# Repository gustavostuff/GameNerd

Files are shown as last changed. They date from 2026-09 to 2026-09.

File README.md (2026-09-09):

Logo V2

> **Status:** Active work has shifted to **[Retr01 Nano](nano/README.md)**, a smaller, simpler sibling meant to ship first. The full Retr01 design below is paused for now. It remains the long-term target once Nano is solid.

Retr01 is an MCU-assisted 8-bit system, complemented by a software toolchain. The software consists of 3 different (WIP) packages:

- **Retr01 Studio**: the game editor. Draw maps, tiles, and sprites, then hit **Play** to try your game (uses the emulator render code).
- **Retr01 Emu**: the standalone game player. Runs a cartridge image on your computer. Studio Play uses this same engine.
- **Retr01 Sim**: the board simulator. Shows the ICs and wiring of the motherboard so we can bring up the real design before hardware.

This is the overall hardware roadmap:

- **Retr01-A and Retr01-C** (Arcade and Console): One THT board for both shells. Same **23-IC** core, [**36-pin cart**](docs/cart.md), **RGBS + composite**, 5 V barrel. Arcade microswitch headers **and** PCB footprints for **2x Switchcraft 35RAPC** TRS ([`docs/controllers.md`](docs/controllers.md)).
- **Retr01-H (stage 2)**: Handheld. SMD, battery, LCD + driver, contact pads. Same software contract. It will also include 3.5mm ports for controllers and possibly one more for mono audio + composite.

## Apps

`./build-all` builds Release **Studio**, **Emu**, **Sim**, **Nano Studio**, **Nano Emu**, and **Nano Sim** into `bin/`. `./studio`, `./emu`, and `./sim` (at root) run the full Retr01 binaries. `./unit-tests` runs their test suites.

**Retr01 Nano** (design + apps under [`nano/`](nano/README.md)): `./nano_studio` (optional project path), `./nano_emu [cart.r01nano]`, and `./nano_sim [cart.r01nano]`.

## Main specs

| Aspect | Description |
|--|--|
| CPU | W65C02S @ **8 MHz** |
| Playfield | **128 x 120** of logical resolution (**16 x 15** tiles), board **2x** to **256 x 240** RGBS field |
| Art | **8 x 8** tiles, **2 bpp**, **64** master colors on-board Color PROM IC |
| Worlds | up to **8** worlds x **48** screens each (384-screen "real state"). All within a 512KB cartridge |
| Scroll | **2 x 2** live nametable window + **true second BG** (SNES-like parallax via color-0 show-through) |
| Sprites | **128** OAM entries, **16** per scanline |
| VRAM / RAM | **32 KB** interleaved VRAM + **32 KB** system RAM |

In cartridge, same **32 KB PRG** as classic NES NROM games (Exitebike, Balloon Fight, Ice Climbers) but it buys far more game: **4.5x** more CPU cycles per frame at **8 MHz**, **32 KB** system RAM (not 2 KB). Scroll, sprite line fill and world map streaming are hardware jobs, so PRG stays game logic, not VBlank nametable tricks. A structured **BG0** far plane scrolls under BG1 (color **0** windows) for real dual-layer parallax, not a mapper hack. See [`docs/selling_points.md`](docs/selling_points.md).

## Screenshots

Peek at Retr01 Studio:

Studio - Graphics

Studio - Audio

Emulator:

Emu

Sim:

Sim

Main PCB - preliminary design, not tested:

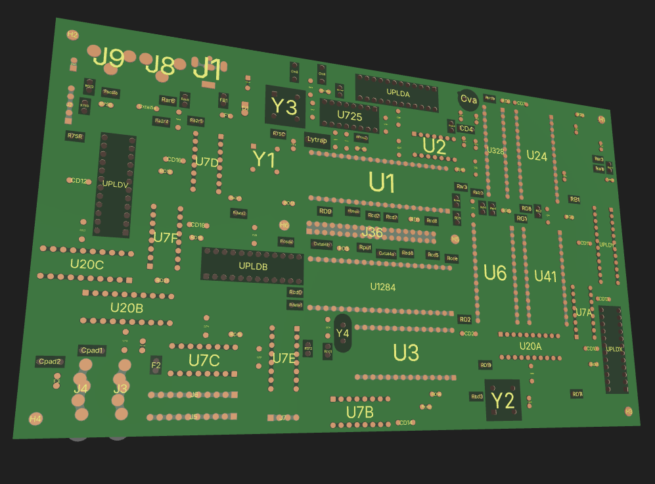
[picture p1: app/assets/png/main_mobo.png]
Main PCB


Cart PCB - preliminary design, not tested:

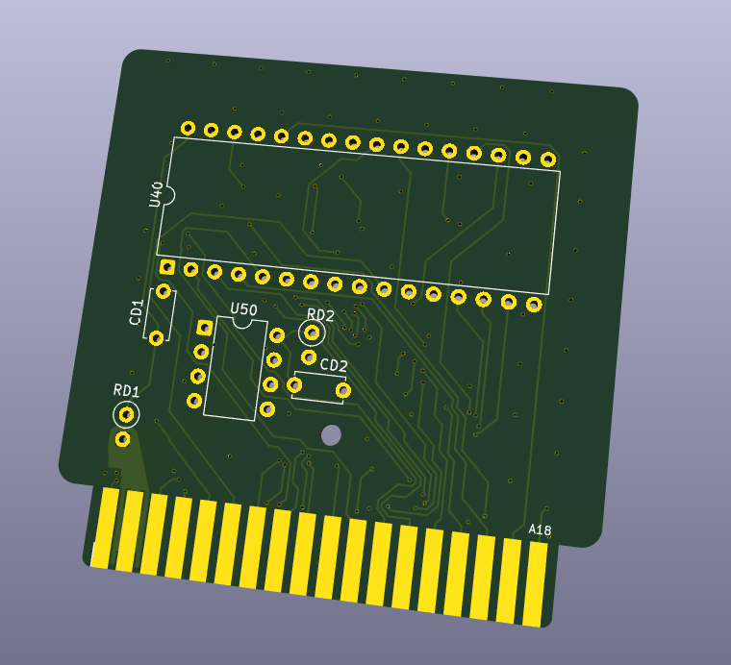
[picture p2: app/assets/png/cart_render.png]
Cart PCB


## Where to go next

- [`docs/graphics.md`](docs/graphics.md): VRAM, BG0/BG1, sprites, palettes, graphics ports
- [`docs/selling_points.md`](docs/selling_points.md): NES vs Retr01, including **SNES-like parallax (BG0)**
- [`docs/memory.md`](docs/memory.md): chips, cart layout, read/write timing
- [`docs/hardware.md`](docs/hardware.md): IC BOM, block diagram, bring-up (chips only)
- [`docs/cart.md`](docs/cart.md): cartridge pinout, form factor, USB-C flasher
- [`docs/controllers.md`](docs/controllers.md): Retr01-A arcade vs Retr01-C pad protocol
- [`docs/lightgun.md`](docs/lightgun.md): CRT light gun accessory (roadmap)
- [`docs/passive_rf_etc.md`](docs/passive_rf_etc.md): passives, ports, stackup / RF
- [`docs/sound.md`](docs/sound.md): APU and bytecode
- [`hw/`](hw/): part list + [`hw/md/`](hw/md/) chip notes. Live KiCad: [`hw/kicad/`](hw/kicad/README.md)

Built for people who want to *make* 8-bit games, not only play them.

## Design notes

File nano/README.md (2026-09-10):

# Retr01 Nano

**The smallest, cutest, simplest cartridge-based dual gaming system (arcade + console).**

**Status: Phase 1 bring-up next.** Host Studio / Emu / Sim already run a MAP-only picture path. Console silicon starts with a bare RGBS lab setup (below). Later phases grow toward the full Nano form already sketched in [`docs/`](docs/).

Retr01 Nano is a **spiritual child** of [Retr01](../README.md): same 128-wide arcade language, far less hardware. One **ATmega1284P** runs a **fixed, open console firmware**. Games live on a **tiny dual-sided cartridge** (SPI EEPROM + save EEPROM). There is **no 6502** and **no external video ASIC**.

## Roadmap (phases)

We are starting at **Phase 1** (not phase 0). Later phases add the rest of the product. The tables and docs below describe that **final form**. Phase 1 is only the smallest path that proves RGBS on a real CRT.

### How we bring up hardware

We grow the console **one phase at a time** instead of assembling the full board and then sorting out every fault at once. Each phase documents, models, builds, and tests a bounded slice of hardware. If something fails, the cause is almost certainly in what that phase added.

Within each phase:

1. **Document** the hardware and how it should behave (pin map, nets, timing, expected picture / signals). Much of the final BOM is already planned in [`docs/`](docs/), so this step often refines known parts rather than inventing them.
2. **Model** that slice in SKiDL directly, or first in **Nano Sim** and then in SKiDL (see [`schematic_generator/`](schematic_generator/), including `generate_phase1.py`).
3. **Import** the updated / expanded netlist into KiCad. Generate or refresh a realistic BOM there (cross-check against the docs from step 1).
4. **Buy** only the new parts for that phase, wire them onto the current protoboard, and **test** on the bench (flash, probe, CRT).

That loop keeps documentation, design, implementation, and validation aligned. Full-board bring-up is deferred until the slices already work.

### Phase 1 (now): RGBS video lab

Goal: prove the video pipeline on a real CRT. Firmware holds a small pattern in ATmega RAM (black backdrop plus a few randomly placed colored squares from the **8** board FG colors), composes **128x96 @ ~60 Hz**, and drives **RGBS** at **256x192** via **2x**. No cart load yet.

| Need | Role |
|---|---|
| ATmega1284P **PDIP-40** | MCU. Flash open firmware. Hold the RAM pattern |
| External **20 MHz** crystal (+ load caps) | Solid clock from Phase 1 (same preferred rate as the final board) |
| 1 or 2 protoboards | Wire MCU + crystal + resistor DAC + power only |
| USBasp | Flash the ATmega (ISP / `J_ISP` pinout) |
| DC barrel jack to screw-terminal adapter | Plug Mean Well **+5V** into the female jack. Screw jumpers on **+** / **-** into the proto rails |
| Resistors | Build analog **R / G / B / CSYNC** (RGBS) per [`docs/pinmap.md`](docs/pinmap.md) |

**Out of scope for Phase 1:** player input, audio, cart flash, save EEPROM, AD725 / composite, sprites, Studio cart load on the MCU.

**Success:** flash via USBasp, run a minimal scanline kernel, see a stable **128x96** (shown **2x**) picture of random colored squares on black over RGBS on the CRT.

### Later phases (final form)

Build toward the full Nano already planned in the docs:

| Area | Final form (docs) |
|---|---|
| Worlds / screens | Up to **8** worlds, **16** present screens/world, **16x16** virtual grid |
| Picture | **1 bpp** tiles, **8** board FG colors, black backdrop, **128x96** logical, **256x192** RGBS via **2x** |
| Motion | Instant screen switch only (no scrolling) |
| Sprites | Soft display sprites (rebuilt after MAP base). Caps TBD in [`docs/graphics.md`](docs/graphics.md) |
| Players | **2P** pad bytes (Retr01 spirit) |
| Audio | **2 PWM** channels (music pulse + SFX), resistor-mixed |
| Cart | **25LC1024** (128 KB game) + **24C64** save, cute **8+8** edge |
| Firmware | Fixed open image on the 1284. Games are cart data |

| | Retr01 (full) | Retr01 Nano (final form) |
|--|---|---|
| CPU / host | 6502 + MCUs | Single ATmega1284P @ 20 MHz (preferred) |
| Storage | Large cart flash + 24C64 | **Cute cart:** **25LC1024** (128 KB, DIP-8) + **24C64** (DIP-8) |
| Firmware | Cart PRG + MCU assists | **Fixed open** 1284 firmware (community-flashable) |
| Video | Multi-layer tile / sprite pipeline | 1 bpp tiles, attr FG color, soft sprites (later) |
| Worlds | Up to 8, rich MAP | Up to **8** worlds, **16** screens/world, **16x16** screen grid |
| Resolution (target) | 128x120 logical playfield | **128x96** logical, **256x192** RGBS via **2x** |
| Motion | Pixel scroll + streaming | **Instant screen switch only** |
| Players | 2P arcade GPIO | **2P** same pad-byte spirit |
| Audio | Multi-channel APU path | **2 PWM channels** (music pulse + SFX), resistor-mixed |

Primary product goal: a **minimal, stable 60 Hz** board with the smallest carts we can get away with, still feeling like Retr01. See [`docs/video.md`](docs/video.md) and [`docs/overview.md`](docs/overview.md).

## Host apps (Studio / Emu / Sim)

For now, **Nano Studio**, **Nano Emu**, and **Nano Sim** are **independent** trees under [`apps/`](apps/) (and root launchers). They may start as copies of the full Retr01 tools and diverge freely.

Later they are intended to **share common code** with the full Studio / Emu / Sim apps (shared libraries or extracted modules) instead of remaining permanent forks. Until that merge, prefer fixing Nano behavior in the Nano tree and keep full apps unchanged unless a change is deliberately shared.

**Apps:** [`apps/studio/`](apps/studio/) is Nano Studio. [`apps/emu/`](apps/emu/) is Nano Emu (MAP preview). [`apps/sim/`](apps/sim/) is the IC/netlist board. See [`apps/README.md`](apps/README.md).

| Runner | Picture | Host audio overlay |
|---|---|---|
| Nano Studio Play | MAP preview (export + emu) | Yes |
| `./nano_emu` | MAP preview | No |
| `./nano_sim` | Soft compose MAP | No |

Host runners are **ahead of Phase 1 silicon**. They already compose MAP tiles from a cart image. Phase 1 MCU firmware does not load carts yet. It only proves RGBS from patterns in ATmega RAM.

## Docs

| Doc | Topic |
|-----|---|
| [`docs/overview.md`](docs/overview.md) | Goals, cuts, roadmap |
| [`docs/graphics.md`](docs/graphics.md) | Worlds, screens, attr byte, MAP compose |
| [`docs/video.md`](docs/video.md) | RGBS, 2x to 256x192, line buffers, VBlank loads |
| [`docs/memory_and_software.md`](docs/memory_and_software.md) | MCU vs cart budgets, open firmware, SDK |
| [`docs/cache_architecture.md`](docs/cache_architecture.md) | How 16 KB SRAM caches cart MAP/CHR without filling to the brim |
| [`docs/sound.md`](docs/sound.md) | 2-channel music + SFX PWM |
| [`docs/cart_format.md`](docs/cart_format.md) | `.r01proj` + `.r01nano` / 128 KB flash layout |
| [`docs/hardware.md`](docs/hardware.md) | Mobo + cute cart connector, BOM sketch |
| [`docs/pinmap.md`](docs/pinmap.md) | MCU PORT / PDIP-40 map, headers, cart edge |
| [`schematic_generator/`](schematic_generator/) | SKiDL. Phase 1: `generate_phase1.py` -> `nano_phase1.net`. Full: `nano_mobo.net` + `nano_cart.net` |

From the repo root:

| Command | Role |
|---|---|
| `./nano_studio [project.r01proj]` | Nano Studio (`bin/nano_studio` from `./build-all`) |
| `./nano_emu [cart.r01nano]` | Nano Emu MAP preview (`bin/nano_emu`) |
| `./nano_sim [cart.r01nano]` | Nano Sim: IC/netlist board UI (islands + DIPs + SCR), not a fullscreen emu |

Source concept notes also live in `temp/Retr01_Nano_Spec.md`. Where this tree disagrees, **these docs win**.

## Non-goals (final product v1)

- Compatibility with full Retr01 `.retr01` cart images or 36-pin edge
- Composite / NTSC encoder chips on the Phase 1 lab (AD725 remains a later board option)
- Hardware sprites, BG0, any screen scrolling
- Full Retr01 Sim netlist reuse

**Authoring:** Nano Studio exports `.r01nano` today (MAP + CHR). Console firmware / C SDK on the 1284 start with Phase 1 RGBS bring-up. Direction: open **C** firmware/SDK plus a tiny assembly video kernel. Game data lands on the SPI cart in later phases.

## Screenshots

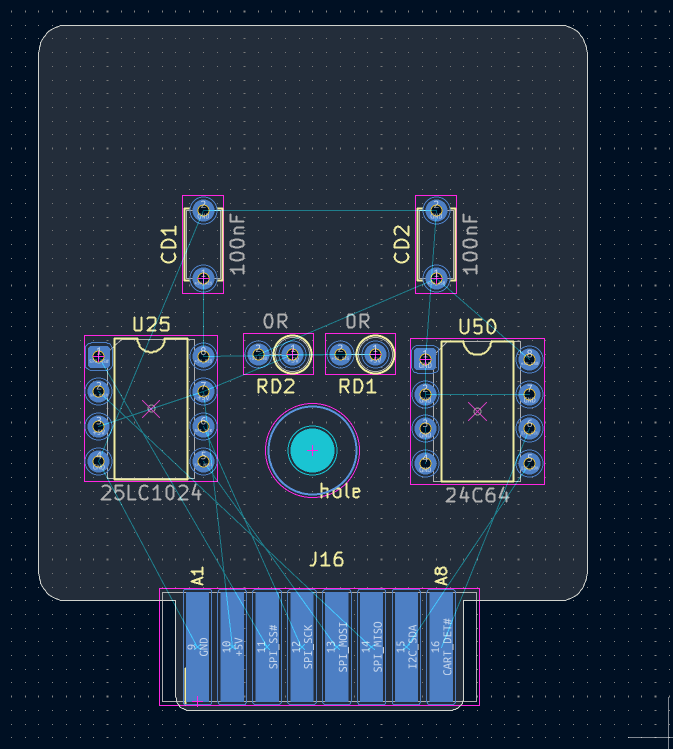
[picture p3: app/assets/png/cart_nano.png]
Nano cart


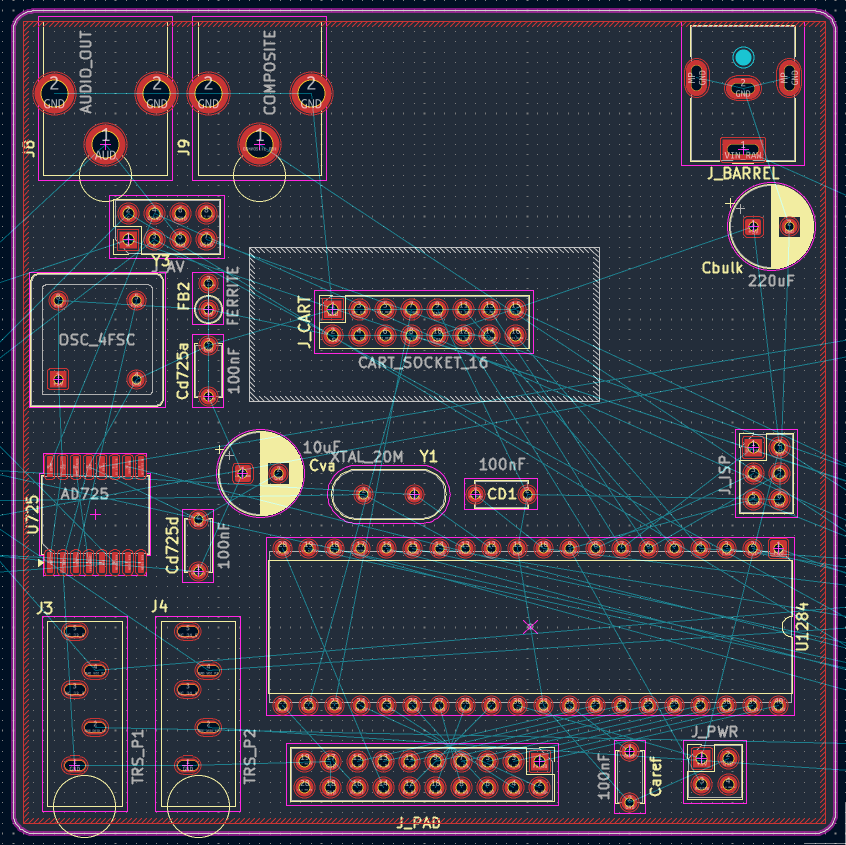
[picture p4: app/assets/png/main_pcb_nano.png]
Nano Main PCB


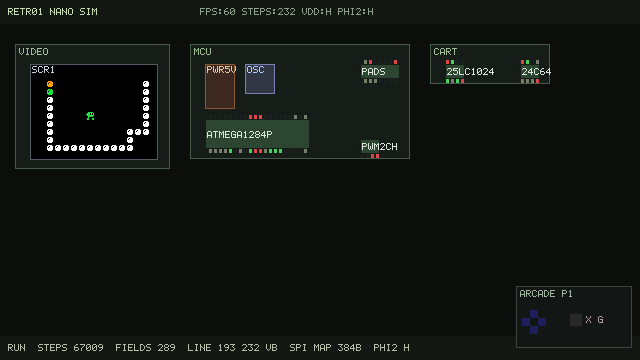
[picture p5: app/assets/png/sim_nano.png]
Nano Sim


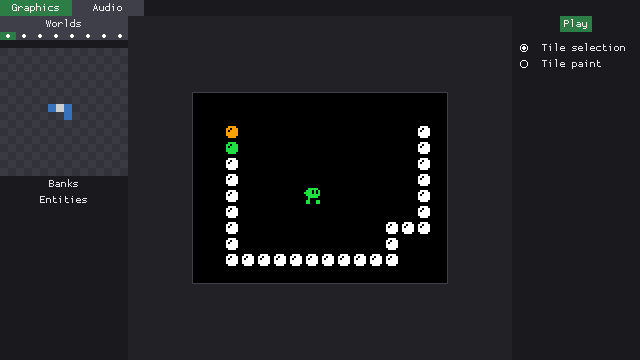
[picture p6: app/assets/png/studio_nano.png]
Nano Studio


## License / ownership

Same project umbrella as Retr01. Console firmware is intended to stay **open** for the community. See the parent repo for licensing when published.

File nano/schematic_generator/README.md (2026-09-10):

# Nano schematic generator (SKiDL)

Python package that turns Retr01 Nano motherboard + cart wiring into KiCad netlists.
Mirrors `app/schematic_generator/` (parent Retr01): pin numbers from official KiCad
symbols, inline SKiDL parts, separate mobo / cart netlists.

## Code-to-copper

1. Docs SoT: `nano/docs/pinmap.md`, `nano/docs/hardware.md`
2. `python generate.py --check`
3. `python generate.py` -> `output/nano_mobo.net` + `output/nano_cart.net`
4. Import each netlist into its KiCad project (see [Netlist import](#netlist-import) below). Outline starts at 100x100 mm (provisional).
5. Route (Quilter optional). Bypass uses per-IC local `+5V_<refdes>` + 0R bridges.

## Netlist import

Nano and full Retr01 share **one** footprint library: [`hw/kicad/Retr01_Lib.pretty`](../../hw/kicad/Retr01_Lib.pretty). The netlist only carries a **name** (e.g. `Retr01_Lib:Jack_3.5mm_Switchcraft_35RAPC2BVN4_Vertical`); KiCad loads the actual `.kicad_mod` from the project **`fp-lib-table`**.

Each Nano KiCad project includes `fp-lib-table` pointing at that folder. After editing a footprint in `Retr01_Lib.pretty`, re-import or **Update Footprints from Library** so pcbnew picks up the change (placed footprints are copies until refreshed).

**Mobo** (`nano/nano_main_pcb/nano_main_pcb_v_01/`):

1. Open `nano_main_pcb_v_01.kicad_pro`.
2. Confirm **Preferences -> Manage Footprint Libraries** shows **Retr01_Lib** (no broken path).
3. **File -> Import -> Netlist** -> `nano/schematic_generator/output/nano_mobo.net`.
4. Enable **Exchange footprint** (or delete old J3/J4/J8/J9 before re-import if footprints were stale).
5. Place / route. Custom parts from netlist: **J3/J4** TRS, **J8/J9** RCA, **J_CART** uses stock PinSocket 2x8 (not Retr01_Lib).

**Cart** (`nano/nano_cart_pcb/Nano_Cart_PCB_v_01/`):

1. Same `fp-lib-table` -> **Retr01_Lib**.
2. Import `output/nano_cart.net`. **J16** -> `Retr01_Lib:Cart_Edge_2x8_P2.54mm`.

## KiCad symbol mapping

Same pattern as parent `retr01_schem/pinmap.py` / `kicad_pin_extract.json`:

| Nano MPN | KiCad lib | KiCad symbol | Notes |
|---|---|---|---|
| ATmega1284P | MCU_Microchip_ATmega | **ATmega1284P-P** | PDIP-40 (mobo THT) |
| AD725 | (inline) | AD725ARZ wide SOIC-16 | `Package_SO:SOIC-16W_7.5x10.3mm_P1.27mm` |
| 25LC1024 | (inline / datasheet) | JEDEC SPI EEPROM | **PDIP-8** cart game image |
| 24C64 | Memory_EEPROM | **24LC64** (extends 24LC16) | **PDIP-8** |
| Passives | Device | R, C | |
| Barrel | Connector | Barrel_Jack_MountingPin | Footprint CUI PJ-063AH |
| Headers | Connector_Generic | Conn_02xN | 2x2 PWR, 2x3 ISP, 2x4 AV, 2x10 arcade |
| TRS / RCA | Retr01_Lib | 35RAPC2BVN4 / RCJ-01x | Same footprints as full Retr01 |

SKiDL still builds `Part(tool=SKIDL)` with **physical pad numbers**. Official KiCad
signal names are aliases (`PB5`, `~{CE}`, ...).

## Quick start

```bash
cd nano/schematic_generator
# reuse parent venv, or:
python -m venv .venv && source .venv/bin/activate
pip install -r requirements.txt

# Phase 1 lab (MCU + crystal + RGBS + ISP, no cart):
python generate_phase1.py --check
python generate_phase1.py
# -> output/nano_phase1.net

# Full mobo + cart (later phases / final form):
python generate.py --check
python generate.py
# -> output/nano_mobo.net + output/nano_cart.net
```

## Layout

```
nano/schematic_generator/
+-- generate.py              # full mobo + cart
+-- generate_phase1.py       # Phase 1 RGBS lab (no cart)
+-- requirements.txt
+-- nano_schem/
|   +-- bom.py
|   +-- pinmap.py
|   +-- kicad_pin_extract.json
|   +-- parts.py
|   +-- connect.py
|   +-- manifest.py
|   +-- cart_manifest.py
|   +-- board.py
|   +-- phase1_bom.py
|   +-- phase1_manifest.py
|   +-- phase1_board.py
+-- library/          # symlink to hw/kicad/Retr01_Lib.pretty
+-- output/
```

Cart gold fingers: `Retr01_Lib:Cart_Edge_2x8_P2.54mm` (same pad recipe as 2x18, 8/side).
Mobo cart slot: PinSocket 2x8 stand-in until EDAC CAD lands.

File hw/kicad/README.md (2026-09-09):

# Retr01 KiCad projects

Single home for PCB / project files and the custom footprint library.

**Netlists** still come from [`app/schematic_generator/`](../../app/schematic_generator/) (`python generate.py`). Import into the live projects below. Quilter Circuit Comprehension notes: [`docs/passive_rf_etc.md`](../../docs/passive_rf_etc.md) (power nets + bypass caps).

## Layout

| Path | Role |
|---|---|
| **[`motherboard/`](motherboard/)** | **Live** motherboard project. Open `Retr01_Motherboard.kicad_pro` |
| **[`cartridge/`](cartridge/)** | **Live** cartridge project. Open `Retr01_Cartridge.kicad_pro` |
| **[`Retr01_Lib.pretty/`](Retr01_Lib.pretty/)** | Custom footprints (TRS, RCA, cart gold fingers). Full Retr01 + **Nano** KiCad projects point here via `fp-lib-table` |
| **[`archive/`](archive/)** | Old boards and Quilter downloads (not the working copy) |

```text
hw/kicad/
+-- Retr01_Lib.pretty/     # authority footprint lib
+-- motherboard/           # live mobo (from former v07)
+-- cartridge/             # live cart
+-- archive/
    +-- motherboard_v01/   # first KiCad project
    +-- snapshots_v02/     # intermediate v02-v07 saves
    +-- quilter/           # Quilter candidate exports
```

## Cartridge gold fingers

Cart netlist `J36` uses `Retr01_Lib:Cart_Edge_2x18_P2.54mm` (pads **1-18** = A / F.Cu, **19-36** = B / B.Cu). Motherboard `J36` stays on the PinSocket stand-in.

**Import / swap in Pcbnew:**

1. Draw `Edge.Cuts` (~**55 x 55 mm**, thickness **1.6 mm**, **4-layer** F/GND/GND/B).
2. `File` -> `Import` -> `Netlist` -> `app/schematic_generator/output/retr01_cart.net` (or Update PCB from schematic if you keep a sch).
3. If an old PinSocket `J36` is still on the board: delete it, then Update PCB so the gold-finger footprint appears.
4. Place `J36` with origin on the insert edge. Pads point into the board (+X in the footprint). Silk **A1** marks side A pin 1.
5. Place U40 / U50 / caps and route.

**Quilter (cart):** Circuit Comprehension checklist is in [`docs/passive_rf_etc.md`](../../docs/passive_rf_etc.md#quilter-circuit-comprehension---cartridge-pcb) (4-layer SIG/GND/GND/SIG, full-board `+5V` on outers, `GND` on inners, stubs pour off, `CD1`/`CD2` only). KiCad: `J36` and `Edge.Cuts` locked; copper zones cover the full outline. After reopen, **Edit -> Fill All Zones**.

Confirm `fp-lib-table` resolves `Retr01_Lib` (already set for `cartridge/`).

SKiDL / schem generator uses the same footprints via a symlink: `app/schematic_generator/library/Retr01_Lib.pretty` -> this folder.

## Archive policy

Do not edit under `archive/` for new layout work. Copy a snapshot into `motherboard/` only if you intentionally revive an old spin. Quilter zips and candidate PCBs stay in `archive/quilter/`.

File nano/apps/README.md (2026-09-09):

# Nano apps

Host-side tools for Retr01 Nano.

| App | Path | Notes |
|-----|---|---|
| **Nano Studio** | [`studio/`](studio/) | Independent for now (started as a Studio fork). Built by `./build-all` as `bin/nano_studio` (`./nano_studio`). Nano caps: graphics, `.r01nano` / 128 KB, **Music+SFX**, 128x96 logical / 2x preview. Host Play via embedded emu. Host BGM/SFX overlay on Play. |
| **Nano Emu** | [`emu/`](emu/) | `.r01nano` picture + Host Play (WASD, Walk state, solid MAP). `./nano_emu`. No audio yet (lags Studio Play). |
| **Nano Sim** | [`sim/`](sim/) | IC/netlist board (islands, pins, wire settle). Nano parts only + SCR on canvas. Links emu core inside behavioral 1284. `./nano_sim`. Not a fullscreen emu. No host audio. |

**Independence now, shared code later:** Nano Studio / Emu / Sim do not need to stay wire-compatible with the full apps while Nano is designed. A later pass should extract shared modules so Nano and full tools stop duplicating forever.

Build and run details live in each app README. Nano console firmware is not here yet (design docs under [`../docs/`](../docs/)).

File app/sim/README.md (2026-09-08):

# Retr01 Board Simulator

IC-first board simulator for the Retr01 motherboard (arcade + console share one netlist). Separate from Retr01 Studio (authoring). Pin/behavior: [`hw/md/`](../../hw/md/). BOM and islands: [`docs/hardware.md`](../../docs/hardware.md).

**Goal:** simulate the Retr01 motherboard as discrete ICs (pins, package, datasheet behavior) wired like the real board. End state: boot a cart, accept pad input, show a digital playfield (logical 128x120 inside a 256x240 RGBS field / LCD sink). Accuracy tightens as tests demand it.

## Status

**9 canvas islands (O first / top-left) + wired-only E/I/P sprite glue, 23-IC soft `$FExx` on L, layer-2 smoke.** SDL board UI. No control-strip power/reset/cart UI (cart image comes from the argv `.retr01` path). Cart USB flasher is **not** on the main canvas: unit-tested via `flasher_bench` only.

| Island | Components (canvas) |
|---|---|
| O Video | `COMPOSITOR` + `AT28C16` (sim, target **AT27C256R**) + `LCD_SINK` + video `SN74HC245` (top-left) |
| A Power+clk | `PWR5V` + `OSC8M` + `SN74HC14` |
| C CPU + decode | `W65C02S`, `AS6C62256`, `ATF22V10` decode, CPU `SN74HC245` |
| G VRAM | 2nd `AS6C62256` + **3x** `SN74HC157` + `ATF22V10` VRAM glue |
| H Beam | `OSC_DOT` + `BEAM_XY` (X PLD) + `ATF22V10` Y compare vs soft `$FE04` |
| J Cart | cart `SN74HC245` (mobo socket path) |
| K APU | `ATMEGA328P` stub, `$FE40`-`$FE5F`, 8-voice mix (BGM+SFX) + digital PWM + WAVE monitor (no host speaker audio) |
| L MCU+linebuf | `ATMEGA1284P` (soft `$FExx`) + linebuf `AS6C62256` + **3x** `SN74HC157` |
| N Cart module | `SST39SF040` + cart `24C64` (detachable module. Argv `.retr01` is copied into flash) |

**Wired on the netlist, not separate canvas frames:** soft `$FExx` (no DIP island), **E** pads (`$FE60`/`$FE61` via 1284), **I** `BG_FETCH`, sprite field fill stats, **P** integration / NMI stats.

Bench-only (wired, not on canvas): `PRG_ROM` fallback when cart does not own `$8000+`.

**Letter note:** Silicon bring-up docs use **N** for the sprite path ([`docs/hardware.md`](../../docs/hardware.md)). On the sim canvas, **N** is the detachable **cart module** island. Sprite milestones still show as **N** in the health strip detail line.

**Cart load:** argv / default **`output/test_2.retr01`** is copied into cart `SST39SF040` after board reset (override: `./sim path/to/cart.retr01`). The **6502 executes cart PRG from flash** (Studio export includes palette + MAP->VRAM boot via `$FE93`->`$FE12`). Startup catchup runs that stream on a **worker thread** (~12k pin-level steps) so the SDL window stays responsive. `board_build` still installs a synthetic image for unit tests that do not call `r01s_board_load_cart`. Host softboot is opt-in only (`R01S_SOFTBOOT=1`). See [`PERFORMANCE.md`](PERFORMANCE.md).

**Cart flasher:** isolated from the main sim. Use `flasher_bench` + `test_cart_flash_flow` / `test_island_flasher`.

**1_FRAME_DEBUG:** `1_FRAME_DEBUG=true ./sim cart.retr01` logs byte-scale IC traffic (PRG/MAP/VRAM/beam/BG0/sprites/play) into a paginated on-screen panel (`[` `]` or PgUp/PgDn). Logging stops once BG (MAP->VRAM) and the first sprite field fill are done. Full dump: `retr01_sim/debug/frame1_trace.log`.

Why the worker exists: [`CATCHUP_THREADING.md`](CATCHUP_THREADING.md).

**Next:** optional machine EEPROM (1284 path). Retire bring-up overlay when game PRG owns MAP.

## Test layers

```text
  Layer 1: Unit (one IC)
       |
       v
  Layer 2: Island (few ICs + wires). See docs/hardware.md + test_island_abcdeghiojklmnp.c
       |
       v
  Layer 3: System (full board + cart + input + screen)
```

Layer 1: per-chip harness tests in `tests/`. Layer 2: island smoke in `tests/test_island_abcdeghiojklmnp.c`. Layer 3: full netlist + golden cart `output/test.retr01`.

## Cart ROM vs runners (triage)

When something looks wrong on screen, do not assume the `.retr01` is bad and do not assume the emu/sim is bad. Studio authoring, cart image, emu, and sim are different layers.

### Who owns what

| Layer | Artifact | On silicon / runners? | Notes |
|---|---|---|---|
| **Studio editor** | `output/test.r01proj` (+ UI) | **No** | Authoring only. Does not execute PRG |
| **Studio Play** | export then shared emu | **Yes** (via cart) | Same path as **Ctrl+E** + emu render. No Studio-only soft preview |
| **Cart image** | `output/test.retr01` (+ `test_flash.bin`) | **Yes** (flash) | Packed bytes SoT for PRG/CHR/MAP/pals. Layout in [`docs/graphics.md`](../../docs/graphics.md) |
| **Color PROM burn** | `test_prom.bin` | **Yes** (motherboard) | Not inside the cart. Kit -> R3G3B2. Target part **AT27C256R** ([`hw/md/AT27C256R.md`](../../hw/md/AT27C256R.md)) |
| **Boot asm listing** | `test_boot.s` | Human-readable only | Binary inside `.retr01` is what runners execute |
| **Emulator** | `retr01_emu` | Software-visible CPU/`$FExx` | Loads `.retr01`. Default: PRG catchup streams pals + start MAP. Softboot opt-in (`R01E_SOFTBOOT=1`). Host Play for camera/player. Used by Studio Play and standalone `./emu` |
| **Board sim** | `retr01_sim` | IC / island netlist | Copies argv/default `.retr01` into cart `SST39SF040`. Catchup ~12k pin-level steps. Flasher is `flasher_bench` unit tests only (not on main canvas). Softboot opt-in (`R01S_SOFTBOOT=1`). Host Play after catchup |

### What is in `test.retr01` today

| In ROM | Meaning |
|---|---|
| Header + pointer table | magic `retr01`, `format_ver` **2** only, world count, **36 B** ptr table (24-bit offs + lens) |
| Other screens + credits | Title + interstitial + credits **pages** in other-screens blob (raw 480 B or RLE). PRG owns presentation |
| Global BG/sprite palettes | 8 BG rows + 8 sprite rows (master indices, not RGB) |
| SPR CHR banks | Real tile bytes from Studio export (4 banks x up to 256 tiles) |
| Entity tables | Per-world type records (origin, hitbox, up to 4 parts) + instance list (type, world x/y) |
| 32 KB PRG | Palette + start-screen MAP stream (`$FE93` -> `$FE08`/`$FE09`/`$FE12`). Scroll/player/warps still **host** Play |
| World table + blobs | CHR banks, screen dir, 480 B present-screen payloads |

| **Not** in ROM | Meaning |
|---|---|
| **Metasprite catalog** | Studio JSON only. Export flattens parts into entity type records |
| Host Play motion, camera dead zone, player anim, warps | Emu / sim Host Play + `../common/r01_play_camera.c` (cart-backed). Not a Studio-only preview |
| Host Play BG0 | Emu + sim Host Play: cart BG0 cache, show-through under BG1 color 0, proportional scroll from present extents. Host overlay only (does not drive IC VRAM slots 4-7 or `$FE06`/`$FE07`) |
| Host collision source | Cart flash MAP attrs (`R01_ATTR_SOLID`). PRG collision stub not used by host runners |
| Editor UI state | UI only. Cart boots world **0** |
| Live camera seam streaming (2x2 shift) | Phase 1 PRG loads start screen only |
| Full game loop in 6502 | Still future. Host Play stands in |

### How to tell ROM bug vs runner bug

1. **Hex / dump the cart first.** If the dump is wrong, it is Studio export. If right, blame the runner or soft helpers.
2. **Same `.retr01` on emu and sim.** Both wrong the same way -> ROM/content or shared contract (`02`). Only one fails -> that runner.
3. **Studio Play is cart-backed.** It exports then runs emu. If Studio Play looks wrong, dump the cart. Do not assume a separate Studio compositor.
4. **Call out soft helpers.** `R01E_SOFTBOOT=1` / `R01S_SOFTBOOT=1` are opt-in host poke only.
5. **Color wrong?** Check `*_prom.bin` / board PROM path separately from cart palette indices.

## Architecture (summary)

| Topic | Choice |
|---|---|
| Time base | PHI2 half-steps from `OSC8M` (`R01S_PHI2_HALF_NS`). Combinatorial settle. `DELAY=typical|max` prints datasheet path budget (pin netlist stays zero-delay so catchup works) |
| Bus | Settle loop (`R01S_SETTLE_PASSES`). H+L -> hard abort. Undriven -> pull-up HIGH (`$FF`) |
| Wiring | Explicit `wire_*` in `board.c`. Global netlist deferred |
| Boot UX | Worker-thread MAP catchup. See [`CATCHUP_THREADING.md`](CATCHUP_THREADING.md) |
| Perf | [`PERFORMANCE.md`](PERFORMANCE.md) |

**Model:** every IC is an `R01sEntity` (pins + vtable). Islands hold entities. Island groups wire them. `r01s_board_build()` binds the full netlist onto **11** canvas frames. Undriven pins pull high. H+L aborts with a bus-fight report.

## Build

From the repo root:

```bash
./build-all
./sim
./unit-tests
```

Developer rebuild of this tree only:

```bash
cd app/sim
cmake -B build -DCMAKE_BUILD_TYPE=Release
cmake --build build
ctest --test-dir build --output-on-failure
./build/retr01_sim
```

Needs: CMake, a C compiler, SDL2 (`sdl2` package).

## Run

```bash
./sim
./sim output/other.retr01
./sim DELAY=typical   # print typ path budget vs PHI2 half
./sim DELAY=max       # print max (worst-case) path budget
# or: ./sim output/test_2.retr01 DELAY=max
```

`DELAY=typical|max` selects the datasheet corner and prints **path budget** (decode+245+573 vs PHI2 half). The pin netlist stays combinatorial. Deferred HC/PLD outputs miss `STA $FExx` in this settle model. Wall-clock UI FPS != sim ns. See [`PERFORMANCE.md`](PERFORMANCE.md).

**Controls:** `Space` pause/resume * `Ctrl+R` reset * `Ctrl+1` / `Ctrl+2` present scale * `R` rotate selected IC * **SCALE 1X/2X** (left sidebar or `G`. **2X** grows the video island to fit SCR1) * `.` single-step (while paused) * **COMPACT / ISLANDS** (HUD) * **left-drag chip** move * **right-click chip** orient H/V * **left-drag empty island** move frame * **bottom-right grip** resize * **Shift+arrows / wheel / middle-drag** pan * `Esc` quit.

**Layout persistence:** island frames + chip positions saved to `app/sim/ui_layout.json` (override with `R01S_LAYOUT`).

**Gamepads (island E -> `$FE60`/`$FE61`):** bottom-right panels or keyboard. HUD **ARCADE** (default) injects the bitfield directly. **PADS** routes through ATtiny85 poll/reply (`0x55`/`0xAA`) then into the same ports. After boot catchup, **Host Play** uses P1 for move + warps (Studio/emu rules: dead-zone camera, player anim blob, collision from cart MAP attrs):

| | Stick | X | Y | Coin | Start |
|--|---|---|---|---|---|
| **P1** | WASD (8-way) | **G** | **H** | 1 | 2 |
| **P2** | Arrows (8-way) | **,** / KP1 | **.** / KP2 | Shift | Enter |

Same keyboard map is used by standalone **emu** and Studio Play.

**Wave monitor (island K):** bottom-left overlay (drag, position in `ui_layout.json`). Lanes **B1-B5** / **S6-S8** draw stable math waveforms from the active voice (period = pitch). **A** is the mixed analog scope ring. After Host Play, silent BGM matches emu: scans `custom_logic.c` for `r01_bgm_play(ctx, N)` and drives B1-B5 from `output/data/bgm_trackN.bin` (Studio **Export**). No host speaker. See [`docs/sound.md`](../../docs/sound.md).

Live probe (top-right) shows **VDD / PHI2 / RESB**. Status bar shows CPU `PC` / `AB` / phase / cycle count.

## Layout

| Path | Role |
|---|---|
| `include/retr01_sim/` | Public headers (`entity`, `pin`, `bus`, `board`, `island*`, `types`) |
| `src/board.c` | Board recipe. 9 canvas islands, wiring, settle loop |
| `src/main.c` | SDL entry |
| `chips/` | Per-part models |
| `tests/` | Layer-1 unit tests + `test_island_abcdeghiojklmnp` (layer 2) |

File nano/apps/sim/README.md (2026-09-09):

# Retr01 Nano Simulator

**Board IC / netlist sim** for Retr01 Nano. Foundation for SKiDL -> Quilter, not a second fullscreen emulator window.

## Is ~60 FPS "because Nano is simple?"

**Yes, now, with one caveat.**

After fixing multi-field catchup, each UI frame advances **exactly one RGBS field** (~232 scanline steps). Scanline work is cheap on this tiny netlist, so the host finishes a field within one vsync easily. Full Retr01 Sim stays ~1 FPS because each step still does heavy beam/VRAM settle across ~23 ICs.

| Still soft (OK for now) | Pin-accurate / board-true |
|---|---|
| Soft compose via emu core (= FW SRAM compose) | Nets in [`nano/docs/pinmap.md`](../../docs/pinmap.md) |
| No AVR instruction ISA | SPI/I2C/PWM/XTAL/pad/sync on real PORT names |
| No pixel-timed FG GPIO DAC shift | 25LC1024 + 24C64 cart entities, WP#/HOLD# tied |
| I2C protocol stub | 1 step = 1 RGBS line + VBlank SPI byte clocks |
| No host BGM/SFX (Studio Play has that overlay) | Pads / move via behavioral 1284 + emu core |

## Board

| Island | Parts |
|---|---|
| **VIDEO** | `SCREEN_SINK` 256x192 |
| **MCU** | `PWR5V`, crystal stand-in (`OSC8M` entity @ 20 MHz timing), `ATMEGA1284P` PDIP-40, `PADS` P1+P2, `PWM2CH` |
| **CART** | `25LC1024` + `24C64` |

MCU package on the PCB is **PDIP-40**. Sim draws the same PORT names (wire by net, not DIP number).

**SCR scaling:** the sink glyph is **128x96**. The **256x192** RGBS buffer is drawn with an **integer** fit (exact 2:1 downscale). That avoids uneven nearest-neighbor pixels from board snap rounding.

## Build / run

```bash
./build-all
./nano_sim output/nano/test.r01nano
```

**Controls:** SPACE pause. WASD+G = P1. arrows+,.= P2. Esc. RMB pan. Ctrl+1/2/3 scale.

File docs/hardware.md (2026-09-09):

# Retr01 Hardware

**IC-focused** doc: the **23-chip** Retr01 motherboard + cart (shared by arcade and console shells), how those blocks connect, and island bring-up. Through-hole DIP target, ~**14 x 12 cm** minimum 4-layer PCB.

Passives, connectors, stackup, ESD/PPTC, and RF practice live in [`passive_rf_etc.md`](passive_rf_etc.md). Not here.

**Related:** [`memory.md`](memory.md) (chips, read/write timing). [`graphics.md`](graphics.md) (VRAM, sprites). [`sound.md`](sound.md) (APU). [`cart.md`](cart.md) (cartridge + flasher). [`programming.md`](programming.md) (AVR / PLD / OTP / cart flash tools). [`controllers.md`](controllers.md) (pads). [`passive_rf_etc.md`](passive_rf_etc.md) (non-IC). Per-chip notes: [`hw/md/`](../hw/md/). Bring-up sim: [`app/sim/`](../app/sim/README.md).

---

## Runners today vs silicon target

**Emu / Sim Host Play / Studio Play** are the source of truth for what runs in software today. **Silicon** sections in this doc family describe the motherboard and cart we are building toward. When they differ, runners win until code is updated.

| Topic | Runners today | Silicon / roadmap target |
|---|---|---|
| Cart image | `.retr01` loaded from host file path (Sim default: `output/test_2.retr01` into cart flash) | SST39SF040 on 36-pin cart, USB-C flasher ([`cart.md`](cart.md)) |
| Cart flasher | Sim island **F** is visual only. Programming path tested via `flasher_bench` harness (**WIP** in main sim UI) | USB-C bench programs cart in socket ([`cart.md`](cart.md#usb-c-cartridge-flasher)) |
| Color PROM | Sim chip model **AT28C16** (64-entry table) | **AT27C256R** OTP ([`hw/md/AT27C256R.md`](../hw/md/AT27C256R.md)) |
| `PPUCTRL` (`$FE00`) | Emu honors L1/L0/SPR enable + NMI. Camera-wrap bits stored, not enforced | Full bitfield incl. wrap modes ([`graphics.md`](graphics.md#ppuctrl-fe00)) |
| `$FExx` ports | Soft `$FExx` on `R01sBoard` (`peek_fe` / `poke_fe`) | Scroll/raster in ATF22V10. Soft ports on 1284 ([`graphics.md`](graphics.md#fexx-ownership)) |
| Cart save | `$FE22`-`$FE24` in-memory 8 KB buffer, no `RDY` stall | 1284 I2C master + `RDY` stall ([`memory.md`](memory.md)) |
| Machine EEPROM | `$FE70`-`$FE72` in-memory 4 KB buffer, no `RDY` stall | 1284 internal EEPROM + `RDY` stall ([`memory.md`](memory.md)) |
| Pads | `$FE60` / `$FE61` from Host Play / UI (Sim: ARCADE direct or PADS via ATtiny85 poll) | Arcade GPIO or Retr01-C UART ([`controllers.md`](controllers.md)) |
| Pad UART netlist | Sim Pads mode: byte-level OD poll/reply on ATtiny85 entities (no TRS / 1284 USART) | 115200 open-drain on TRS DATA |
| BG0 scroll | `$FE06` / `$FE07` latched. Host Play uses proportional scroll unless CPU overrides | Soft on 1284 (`SEL_FE06`/`FE07`) |

Studio Play uses the same Emu core as standalone `./emu`.

---

## 23 IC parts is the current goal

| Block | Parts | Role on PCB |
|---|---|---|
| CPU | W65C02S | Game logic, `$FExx` writes, MAP/VRAM streaming |
| Helper MCUs | ATmega1284P, ATmega328P | Sprites/pads/EEPROM/soft `$FExx` vs dedicated APU |
| SRAM x3 | AS6C62256 | System RAM, interleaved VRAM, sprite line buffer |
| Cart storage | SST39SF040 + 24C64 | 512 KB flash on cart + I2C save EEPROM ([`cart.md`](cart.md)) |
| Video glue | 5x ATF22V10, 6x HC157, 3x HC245 | Decode, beam, interleave, registered scroll/raster, bus isolation |
| Color out | AT27C256R OTP | 64-entry R3G3B2 PROM -> binary-weighted DAC -> RGBS (75 ohm to GND) |
| Composite (support) | AD725 + 14.31818 MHz can | RGB->NTSC into J9. Outside the 23-IC logic count. Chip is wide SOIC-16. Full Retr01: DIP-16 + Proto Advantage PA0006. Nano: direct SOIC-16W ([`passive_rf_etc.md`](passive_rf_etc.md)) |

**Count:** **23** (21 mobo + 2 cart). Escape **+1 PLD** if compositor or scroll/raster fit overflows. **74HC14** (reset/clock) and **AD725** (composite) are outside the 23.

**Clocks:** CPU **8.000 MHz**, dot **5.369318 MHz**, 1284 **20 MHz**, 328P **16 MHz**. Raster **341x262**, ~**60.098 Hz**.

---

## Bill of materials

| Qty | Part | PCB role |
|-----|---|---|
| 1 | W65C02S | 8 MHz game CPU |
| 1 | ATmega1284P | 20 MHz: OAM, sprite line fill, pads, machine EEPROM, soft `$FExx` |
| 1 | ATmega328P | 16 MHz: APU (`$FE40`-`$FE5F`) |
| 1 | AS6C62256 | 32 KB system RAM |
| 1 | AS6C62256 | 32 KB interleaved VRAM |
| 1 | AS6C62256 | 32 KB sprite line-buffer SRAM |
| 1 | SST39SF040 | 512 KB cart flash (socket on mobo early) |
| 5 | ATF22V10 | Decode, VRAM+scroll X, beam X+scroll Y, beam Y+raster, compositor+MAP A14-18 |
| 6 | 74HC157 | VRAM + line-buffer address mux |
| 3 | 74HC245 | CPU / video / cart-OAM bus isolation |
| 1 | AT27C256R | Color PROM (6-bit index -> R3G3B2, 45 ns OTP) |
| 1 | 24C64 (cart) | Per-game save EEPROM |

Vendor datasheets (WDC, Alliance, Microchip / Atmel, SST): look up each part by name on the manufacturer site when pinouts or AC timing matter.

---

## How blocks connect on the PCB

Four compute domains share **5 V** and **never** paint a full framebuffer:

```text
                    +------------------+
  Cart SST39SF040 --| PRG / CHR / MAP  |-- CHR read (BG dots + 1284 VBlank/HBlank)
                    +--------+---------+
                             |
  W65C02S -------------------+------- $FExx (PLD regs + 1284 soft) + PLD decode
       |                     |              |
       | PHI2                |              +---> ATmega328P (APU)
       v                     |
  AS6C62256 sys RAM          +---> ATmega1284P (OAM, pads, EEPROM, soft $FExx)
       |
       +-- $FE10-$FE12 -----> AS6C62256 VRAM (interleaved with BG fetch)
                                    |
  Dot clock + beam PLDs ------------+---> tile/attr -> cart CHR -> palette -> PROM
                                    |
  ATmega1284P ---------------------> AS6C62256 (sprite field + BG0 ping-pong)
                                    |
  Compositor PLD -------------------> RGBS (+ SCALE DIP 1x/2x)
```

**Bus rule:** three HC245 domains + PLD `/OE` ---> one driver at a time per domain.

**SCALE DIP:** **2x** default (128x120 logical fills **256x240** RGBS). **1x** centers 128x120. Raster timing unchanged.

**VRAM interleave (island G):** PHI2 high = CPU may R/W `$FE10`-`$FE12`. PHI2 low = BG fetch owns VRAM. Three HC157 mux low address bits between CPU path and beam VA (line-buffer uses the other three). Details: [`memory.md`](memory.md).

---

## Signal paths

### Background video

1. Beam PLDs step **341x262** and fetch tile/attr from **VRAM** on PPU phases (BG1 slots 0-3).
2. BG1 scroll (`$FE02`/`$FE03`) is registered inside VRAM-glue / beam-X PLDs and offsets into the BG1 2x2 workbench ([`graphics.md`](graphics.md)).
3. Attr **BANK** picks CHR tile from cart flash. Active palette indices -> **Color PROM** -> DAC.
4. Compositor PLD muxes sprite vs BG1 vs BG0 (show-through when BG1 index is **0**) vs backdrop.

### Second background (BG0)

SNES-like far plane: authored second tilemap, color-0 show-through under BG1, proportional scroll for depth ([`selling_points.md`](selling_points.md#snes-like-parallax-bg0)).

1. Software keeps BG0 screens in VRAM slots **4-7** and sets `$FE06`/`$FE07` (often proportional to BG1 scroll).
2. Target silicon / sim: **HBlank** fills the next BG0 line from slots 4-7 + cart CHR (sim uses cart BG0 cache into linebuf). Sprites use **VBlank** for a full playfield field so they do not steal HBlank.
3. Emu Host Play composites BG0 under BG1 color 0 from the cart BG0 cache in the full-frame renderer (not a separate HBlank worker). See [`graphics.md`](graphics.md).

### Sprites

1. CPU fills **OAM** in 1284 via `$FE20`/`$FE21`.
2. Locked split with BG0: **VBlank** plots the full **120x128** sprite field. **HBlank** fills the next BG0 line. Active dots apply BG1 color-0 show-through. Cap **16** sprites per logical scanline.

### Pads

1. All pad paths feed the **ATmega1284P**. CPU reads packed bits at **`$FE60`** (P1) and **`$FE61`** (P2). Bit set = pressed ([`controllers.md`](controllers.md)).
2. **Silicon / PCB target:** one motherboard carries **both** I/O styles (arcade vs console is shell / population, not a different PCB):
 - **Retr01-A (arcade):** **J5/J6** 1x10 microswitch headers + **J7** 1x4 power/reset ([`controllers.md`](controllers.md#locked-headers-schematic-freeze)).
 - **Retr01-C (console):** **2x Switchcraft 35RAPC** TRS for aux pads. Pad boards use **ATtiny85** on a **3-wire** (5 V / DATA / GND) half-duplex UART link ([`controllers.md`](controllers.md)). Populate jacks for console. DNP OK on pure arcade builds.
3. **Runners today (Emu / Sim):** Host Play drives `$FE60` / `$FE61`. Sim HUD **ARCADE** = direct inject. **PADS** = ATtiny85 poll/reply into those ports. TRS jack netlist / 1284 USART not modeled yet.
4. Ports / ESD / PPTC: [`passive_rf_etc.md`](passive_rf_etc.md).

### Audio

1. CPU writes **`$FE40`-`$FE5F`** (bytecode to 328P). See [`sound.md`](sound.md).
2. Path = PLD decode + CPU HC245 + 328P latch/port. **1284 does not synthesize.**

### Raster IRQ

1. `$FE04` compare value is registered inside the beam-Y PLD (load on `SEL_FE04`).
2. Y-beam match ---> **IRQB** to 6502.

### Five ATF22V10 roles (target)

| PLD | Job |
|-----|-----|
| Decode (UPLDA) | Chip-selects for `$FExx` windows and bus `/OE` |
| VRAM glue (UPLDB) | Interleave enable with PHI2 + HC157 AB + **scroll X** register |
| Beam X (UPLDX) | Dot counter / H timing inside 341 + **scroll Y** register |
| Beam Y (UPLDY) | Line counter / **raster Y** register + compare / NMI edges |
| Compositor (UPLDV) | Sprite vs BG1 vs BG0 show-through + Color PROM index + **CART_A14-A18** MAP export |

---

## Protoboard bring-up

Prove **islands** on breadboard before full PCB. Pass = island smoke test, not a shipped game.

```text
A Power --> B Clocks --> C CPU+RAM+PRG --> D soft $FExx --> E Pads
                              |
                              +--> G VRAM interleave --> H Beam --> I BG fetch ----+
                              |                                                    |
J Cart flash -----------------+                                                    +--> O RGBS --> P Integration
K 328P APU ------------------------------------------------------------------------+
L 1284 soft $FExx / OAM --> M Line buf --> N Sprites ------------------------------+
```

| Island | Pass |
|---|---|
| **G** VRAM | `$FE10`-`$FE12` R/W, no PHI2 fight |
| **H** Beam | Stable 341x262, NMI stub |
| **N** Sprites | Expected pixels in line buffer |
| **O** Video | RGBS stable at 2x or 1x SCALE |

Full letter list, sim canvas grouping (11 frames), and port smoke checks: [`app/sim/README.md`](../app/sim/README.md). Sim canvas **N** is the cart module. Silicon bring-up **N** in the diagram below is the sprite path (wired via 1284/L, not a separate sim frame).

---

## Form factors

| Variant | What differs |
|---|---|
| **Retr01-A** | Arcade shell. Wire **arcade controller** headers to cabinet microswitches. RGBS + composite + mono audio, 5 V barrel. TRS jacks optional (DNP OK). |
| **Retr01-C** | Console shell. **Same motherboard.** Populate **2x 35RAPC** TRS for aux pads ([`controllers.md`](controllers.md)). Arcade headers still present for DIY sticks. Same AV + cart ([`cart.md`](cart.md)). |
| **Retr01-H** | Handheld SMD later, same cart / `$FExx` software contract |

**Cart programming:** USB-C **cartridge flasher** (ATmega32U4 bench board). Not on the motherboard. See [`cart.md`](cart.md). **Sim:** flasher island is on the canvas for layout. USB programming is **WIP** (harness tests only).

Ports and passives: [`passive_rf_etc.md`](passive_rf_etc.md).

---

## Resolved / deferred topics

| Topic | Resolution |
|---|---|
| Color PROM speed | **AT27C256R** 45 ns OTP ([`hw/md/AT27C256R.md`](../hw/md/AT27C256R.md)). Unused address pins tied **GND**. Binary-weighted outputs through **75 ohm** to ground -> **~0.7 Vpp** RGBS. |
| Composite | **AD725** NTSC from RGBS + CSYNC ([`passive_rf_etc.md`](passive_rf_etc.md)). **AV outs: RGBS + composite.** Full Retr01: DIP-16 + PA0006. Nano: direct SOIC-16W. |
| `$FExx` | Scroll/raster in PLDs. Soft ports on 1284 ([`graphics.md`](graphics.md#fexx-ownership)). |
| Cart I2C save API | `$FE22`-`$FE24` via 1284 master ([`memory.md`](memory.md#cart-save-eeprom-24c64-on-cartridge)). |
| Machine EEPROM API | `$FE70`-`$FE72` + `RDY` stall ([`memory.md`](memory.md#atmega1284p-internal-eeprom-4-kb)). |
| Aux pad protocol | Retr01-C 3-wire UART ([`controllers.md`](controllers.md)). |
| Cart edge + flasher | 36-pin pinout + USB-C flasher ([`cart.md`](cart.md)). |
| Chip programming | AVR ISP, ATF JEDEC, Color PROM OTP, cart flash ([`programming.md`](programming.md)). |
| VBlank sprite budget | 1284 @ 20 MHz: ~25k cycles in VBlank. Full **128**-entry field with Y-buckets ~12-16k cycles ([`graphics.md`](graphics.md#sprites)). |

| Topic | Still open |
|---|---|
| RGBS / AD725 analog tuning | Targets locked in [`passive_rf_etc.md`](passive_rf_etc.md). Bench on first spin |
| Flasher firmware | Protocol locked in [`cart.md`](cart.md). Implement on 32U4 |
| UPLDA SEL pin sharing | **Accepted this spin:** pin 14=`FE00`/`FE06`, 15=`FE02`/`FE07`, 22=`FE92`/`FE93`, 23=`FE10`/`FE11`/`FE12`. Soft ports that share a SEL need address demux or +1 PLD before freeze. See [`hw/md/ATF22V10.md`](../hw/md/ATF22V10.md#uplda-sel-sharing) |
| UPLDB FE10/FE11 | **Accepted:** both on pin 22 after FE02 took pin 23 |
| HC245 DIR/OE | **Accepted this spin:** driven from UPLDB (UPLDA I/O budget) |
| 1284 soft strobe pins | Only PD0/PD1 free for FE08 + MAP family. FE00/FE05 share FE06/FE08 pins. Firmware contract: [`hw/md/ATmega1284P.md`](../hw/md/ATmega1284P.md#soft-fexx) |

---

## Historical note

Nine SN74HC573 latches once held `$FExx` I/O. They are gone from the BOM. Port ownership is in [`graphics.md`](graphics.md#fexx-ownership).

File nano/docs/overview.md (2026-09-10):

# Overview

**Status: Phase 1 RGBS lab next.** Host Studio / Emu / Sim run a MAP-only picture path today. Console silicon starts with ATmega + proto + resistor RGBS only. Later phases grow toward the locked feature sketch below (worlds, sprites, 2P, audio, cart). Hardware is brought up **incrementally** (document, model, KiCad/BOM, proto test per phase). See [`../README.md`](../README.md#roadmap-phases).

## Intent

Retr01 Nano keeps the *feel* of Retr01:

- 128-wide playfield
- Arcade cabinet language
- Worlds and screens on a small cart
- One clear machine you can reason about end to end

It drops the heavy motherboard: no 6502, no PLD tile engine, no OAM, no BG0, no rich APU. The console MCU runs **fixed open firmware**. Each game is a **tiny cartridge**.

## Design goals

1. One **ATmega1284P** (20 MHz preferred) as the whole console.
2. Stable progressive **RGBS** at **60 Hz**.
3. **Cute dual-sided carts** (**8+8** gold fingers, same pad pitch/width as full Retr01). See [`hardware.md`](hardware.md).
4. Instant screen switches only (no scrolling).
5. **MAP-only** picture path today. Soft sprites will be rebuilt later from this base.

## Locked feature sketch

| Feature | Value | Notes |
|---|---|---|
| Resolution | **128x96** logical, **256x192** RGBS (2x) | Letterboxing / empty bands OK in the logical grid |
| Frame rate | **60 Hz** stable | Progressive RGBS only (v1) |
| Pixels | **1 bpp** | FG color from per-tile attr (8 colors). Backdrop always **black** |
| Tiles | **8x8** | |
| Screen | **16x12** tiles | Matches 128x96 |
| World grid | **16x16** screens | Max **8** worlds, **16** present screens/world |
| BG banks | **4** per world | Selected by attr bank bits |
| Sprites | **None** (MAP-only host compose) | Soft sprites TBD. See [`graphics.md`](graphics.md) |
| Scroll | **None** | Instant screen switch in VBlank |
| Audio | **2 PWM channels** | Music pulse + SFX. Resistor mix to one jack ([`sound.md`](sound.md)) |
| Input | **2 players** | Retr01 `$FE60` / `$FE61` bit spirit |
| Console Flash | 128 KB on 1284 | Open firmware + kernel only |
| Cart game ROM | **25LC1024** **128 KB** (PDIP-8) | PRG data, MAP, CHR, music. **8+8** edge ([`hardware.md`](hardware.md)) |
| Cart save | **24C64** always | Simpler cart routing than optional populate |

## Explicitly dropped (vs full Retr01)

- 6502 CPU and `$FExx` bus as a product requirement
- Large 36-pin cart edge / SST39SF040 class flash
- Hardware tile engine / full Retr01 OAM ASIC path (Nano has no sprites yet)
- Color PROM and multi-layer BG0
- Fine pixel or tile scrolling
- Complex multi-channel APU
- Composite / NTSC encode path

## Relationship to full Retr01

**Spiritual child**, not a binary-compatible subset.

- Same pad-byte spirit and 128-wide arcade language
- Different cart electricals and image format
- Studio / Emu / Sim for full Retr01 stay separate

## Build roadmap (firmware first)

1. Rock-solid **128x96** compose + **256x192** (2x) RGBS kernel with double line buffer.
2. In-RAM nametable renderer (tile + attr, black backdrop).
3. SPI cart read + **instant screen load** in VBlank.
4. Entity stamp pass (priority over MAP).
5. PWM audio + 2P GPIO.
6. Tiny sample cart game.
7. Only then push vertical resolution.

PCB and cute-cart connector can proceed in parallel (see [`hardware.md`](hardware.md)). Motherboard outline starts at **100 x 100 mm**, provisional. SKiDL: [`../schematic_generator/`](../schematic_generator/). Provisional port pin map: [`pinmap.md`](pinmap.md). SRAM cache policy: [`cache_architecture.md`](cache_architecture.md).

## Open items

- Exact C SDK / host OS tooling
- Community flash tools for cart images (Studio already exports `.r01nano`)
- Game authoring polish beyond Nano Studio
- Final RGBS connector shell
- Later: TRS light gun on the pad bus ([`hardware.md`](hardware.md#planned-later-not-in-v1-netlist--pcb)). RCA/AD725/TRS are already in the mobo netlist

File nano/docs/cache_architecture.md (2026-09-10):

# Cart cache architecture (ATmega1284P)

**Status: design.** MCU stays **ATmega1284P** (16 KB SRAM). Cart flash is the source of truth. Firmware **caches aggressively** into SRAM for the live world/screen, and **leaves explicit headroom** so the kernel never sits at 100% RAM.

Related: [`memory_and_software.md`](memory_and_software.md), [`graphics.md`](graphics.md), [`video.md`](video.md).

## Goals

1. **Never SPI-fetch in the active scanline kernel.** RGBS timing plays only from SRAM.
2. **Cache everything that makes 60 Hz easy:** current MAP screen, all **4** CHR banks for the active world, world directory, small audio scratch.
3. **Do not saturate** the 16 KB. Keep a reserved free band for stack growth and future firmware.
4. Cart remains authoritative. Caches are disposable views refilled on world/screen changes.

## Planning assumptions (freeze later with cart format)

| Item | Planning value | Notes |
|---|---|---|
| Tiles per BG bank | **256** | Index is one byte |
| Bytes per 8x8 1 bpp tile | **8** | |
| CHR bank size | **2 KB** | 256 x 8 |
| Four banks / world | **8 KB** | Fits in 1284P with room to spare |
| Screen nametable | **384 B** | 16x12 x (tile + attr) |
| Soft sprites | **TBD** | Not in host compose yet |

If a future cart format uses fewer tiles per bank, the CHR cache shrinks and headroom grows.

## SRAM map (16 KB)

Target fill: about **70-80%** used when a world is hot. About **20-30%** kept free.

```text
+---------------------------+  0
| Soft stack + ISR slack    |  ~0.75 KB  (grows downward in practice)
+---------------------------+
| Firmware BSS / globals    |  ~0.5 KB
| Pads, PWM, frame counters |
+---------------------------+
| RESERVED HEADROOM         |  ~2.5 KB   never assigned to caches
+---------------------------+
| Audio scratch / song ptrs |  ~0.25 KB
+---------------------------+
| (sprite / game RAM TBD)   |  ~1.0 KB   reserved for future soft sprites
+---------------------------+
| Screen MAP cache          |  384 B     current nametable
| Screen MAP prefetch (opt) |  384 B     next screen (optional)
+---------------------------+
| World directory cache     |  ~0.25 KB  present-screen list / offsets
+---------------------------+
| CHR cache bank 0..3       |  8 KB      full world CHR
+---------------------------+
| Compose / stamp scratch   |  ~0.25 KB  optional dirty helpers
+---------------------------+
| Double line buffers       |  32 B      scanout
+---------------------------+  16 KB
```

### Budget table

| Region | Size | Lifetime |
|---|---|---|
| CHR banks 0-3 (active world) | **8192 B** | Until world change |
| Current screen nametable | **384 B** | Until screen switch |
| Prefetch nametable (optional) | **384 B** | Until consumed / discarded |
| World directory | **~256 B** | Until world change |
| Soft sprite / game RAM (TBD) | **~1024 B** | Reserved; unused in MAP-only hosts |
| Line buffers | **32 B** | Permanent |
| Audio scratch | **~256 B** | Permanent / track change |
| Firmware BSS + pads | **~512 B** | Permanent |
| **Reserved headroom** | **~2560 B** | Untouched by cache allocator |
| Stack peak allowance | **~768 B** | Inside / beside headroom |

Exact linker layout can shuffle order. The numbers are the contract: **CHR all four banks resident**, **MAP current resident**, **~2.5 KB reserved empty**.

## Cache tiers

```text
COLD   Cart SPI only (25LC1024)
         |
         |  world enter (multi-VBlank OK)
         v
WARM   World directory + CHR banks 0..3 in SRAM
         |
         |  screen enter (one VBlank)
         v
HOT    Current nametable (+ optional prefetch) + linebufs
         |
         |  active display
         v
KERNEL Reads HOT/WARM SRAM only. No SPI.
```

### World enter (WARM fill)

When `world` changes:

1. SPI-read world directory into RAM.
2. SPI-read **all four** CHR banks into the 8 KB CHR cache.
3. May span **several VBlanks** (8 KB SPI is fine across a few frames at 60 Hz). Show a black frame or previous screen until WARM is valid.

### Screen enter (HOT fill)

When the screen switches (only motion model):

1. SPI-read **384 B** nametable for the new screen into the current MAP slot (one VBlank, easy).
2. If prefetch holds that screen already, **swap pointers** instead of reading.
3. Optionally kick a prefetch read for a predicted neighbor (door / edge) into the second 384 B slot during later spare VBlank time.

### Active frame (no SPI)

Each frame in HOT:

1. Start from cached nametable.
2. Scanline kernel walks tiles, indexes **CHR cache[bank][tile]**, applies flip + FG color, backdrop black.
3. Soft sprites (when reintroduced) stamp after MAP; not in the host path yet.

## What is not cached (stays on cart)

- Other worlds CHR/MAP
- Cold music banks beyond the small scratch / current pattern
- Save payloads (go through 24C64 when needed)
- Large script blobs until the SDK defines streaming windows

This keeps the 16 KB from turning into a second cart image.

## Prefetch policy (optional but recommended)

Because Nano has **no scrolling**, the expensive case is only screen switches.

| Policy | Behavior |
|---|---|
| None | Every switch SPI-reads 384 B in VBlank (still OK) |
| Single prefetch | After a screen loads, read one predicted neighbor MAP into the second slot |
| Pointer swap | On walk into the prefetched screen, swap current/prefetch and refill the empty slot |

CHR does **not** need prefetch if all four banks for the world are already WARM.

## Soft sprites (TBD)

Reserved ~1 KB in the SRAM sketch for a future soft sprite / game table. Host compose is MAP-only until that path is rebuilt.

## Failure / overflow rules

- If a cart world declares more CHR than 8 KB, firmware **rejects** the world or loads a reduced bank set (format must declare sizes).
- Cache allocator must **never** eat the reserved headroom.
- If SPI underruns a WARM fill, stay on black / last good frame. Do not enter the active kernel with incomplete CHR pointers.

## Why 1284P (not 644) for this plan

| | ATmega644 (4 KB) | ATmega1284P (16 KB) |
|--|---|---|
| All 4 CHR banks resident | No (would dominate RAM) | **Yes (~8 KB)** |
| MAP + entities + headroom | Tight / windowed CHR only | **Comfortable** |
| SPI only on world/screen edges | Required + CHR streaming | **World/screen edges only** |

Nano keeps **1284P** so "cache all we can" means **full world CHR + live MAP**, not a thin tile window.

## Summary

- Cart = source of truth  
- SRAM = full **world CHR** + **current screen MAP** + **entities** + linebufs  
- SPI = world enter + screen enter (+ optional MAP prefetch)  
- Active video = SRAM only  
- **~2.5 KB** deliberately left free  

That is the intended use of the 1284P memory advantage.

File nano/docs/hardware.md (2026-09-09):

# Hardware

**Status: design -> connector freeze for Sim/SKiDL.** Goals: **smallest practical motherboard**, and the **cutest dual-sided carts** we can build.

Reference class to beat on mobo size: early Uzebox-style boards (DIP AVR, RCA pair, NES plugs, NTSC encoder). See [uzebox.org](https://uzebox.org/). Nano wins by deleting parts and using a tiny cart, not by packing a large BOM tighter.

Port / edge electrical SoT: [`pinmap.md`](pinmap.md).  
SKiDL netlists: [`nano/schematic_generator/`](../schematic_generator/) (`nano_mobo.net`, `nano_cart.net`).

## Why Nano can be smaller

| Uzebox-like board | Retr01 Nano |
|---|---|
| DIP-40 AVR | **DIP-40** ATmega1284P (THT). Only SMD IC is **AD725ARZ** |
| 8-bit R-2R + NTSC encoder | **1 bpp** FG + **AD725ARZ** SOIC-16 + RGBS header |
| Dual RCA | **CUI RCJ-012/014** mono audio + composite (same as full Retr01) |
| NES plugs | **2x10** arcade + **2x Switchcraft 35RAPC** TRS (Retr01-C pads) |
| No / large cart | **Tiny dual-sided gold-finger cart**, **8 pads/side** |
| MIDI | None |

## Motherboard block diagram

```text
  Barrel 5V (PJ-063AH) ---> protection / bulk ---> 5V plane
                                    |
                          +----------+-------------+
   Crystal 20 MHz ------> |      ATmega1284P       |<-- J_ISP (2x3 AVR)
                          |      (open FW)         |
  J_PAD arcade 2P ------> |                        |---- FG + CSYNC -------> J_AV (RGBS+AUD)
  J3/J4 TRS (UART) -----> |  PD2 PAD_DATA          |---- PWM mix ------+---> J8 audio RCA
                          |                        |                   |
                          |                        |---- SPI/I2C ----------> J_CART (2x8 edge)
                          +----------+-------------+
                                    |
                              R/G/B + CSYNC (AC couple)
                                    |
                              +-----+------+
                              | AD725ARZ   |<-- Y3 14.31818 MHz
                              | (SOIC-16)  |
                              +-----+------+
                                    |
                                 J9 composite RCA
```

## Motherboard outline (provisional)

| Item | Value |
|---|---|
| Board size | **100 x 100 mm** (10 x 10 cm) |
| Status | **Starting target only** (not locked). Quilter / hand layout may shrink or grow |

Fits DIP-40, cart edge, barrel, headers, and passives with room to spare for first spin. Prefer keeping connectors on edges. Final outline follows placement.

## Cute cartridge (locked 8+8)

Classic **plane gold fingers**, both sides. Same finger recipe as full Retr01 cart ([`docs/cart.md`](../../docs/cart.md)), fewer positions.

| Item | Value |
|---|---|
| Contacts | **8 per side** (16 total) |
| Pitch | **2.54 mm** (same as Retr01 36-pin) |
| Finger pad size | **8 x 1.7 mm** (same as Retr01) |
| Board thickness | **1.6 mm** |
| Finger center span | **7 x 2.54 = 17.78 mm** (A1..A8) |
| Outline | As small as flash + EEPROM + fingers allow (no minimum size goal beyond that) |

**Doable:** yes. Same pad width/pitch as the large cart. Only the mating length shrinks.

### Cart IC packages (hand-buildability)

**Edge pads != IC pins.** The cart connector is **8+8** for SPI/I2C/power only. Both cart ICs are **PDIP-8** (fully THT).

| Role | Locked MPN | Package | Notes |
|---|---|---|---|
| Game image | **25LC1024-I/P** | **PDIP-8** | 1 Mbit SPI EEPROM, **2.5-5.5 V**, JEDEC SPI pinout. SKiDL default. |
| Save EEPROM | **24C64** family | **PDIP-8** | Same pinout as SOIC. |

Optional SMD twin for game chip: **25LC1024-I/SM** (SOIJ-8, ~208 mil). Legacy **SST25VF010A** (SOIC-8 150 mil, 3.3 V only) is no longer the cart default.

Flasher FW must use **25LC1024** write/erase commands (SPI EEPROM), not raw NOR flash opcodes. Reads for `.r01nano` streaming match JEDEC SPI.

DIP-16 / parallel NOR still do not fit the cute **8+8** edge model (see prior notes).

### Female connector (motherboard + flasher)

| Role | Part (target) | Notes |
|---|---|---|
| Mobo / flasher cart slot | **EDAC 395-016-520-201** class (**2x8**, straight / vertical) or Sullins **EBC08DRXN** | Same family as full Retr01's 2x18 EDAC 395. KiCad stand-in until CAD lands: `PinSocket_2x8_P2.54mm_Vertical` |
| Cart PCB fingers | Custom `Cart_Edge_2x8_P2.54mm` (clone of `Cart_Edge_2x18_...` truncated) | Pads 1-8 = side A (F.Cu), 9-16 = side B (B.Cu under A) |

Right-angle 2x8 (console shell later) can swap footprint later. **Electrical pinout stays**.

### Cart edge pinout (play + program)

Signals needed for **25LC1024** + 24C64 are only **eight unique nets**. Both sides carry mirrored power/SPI/I2C for contact reliability. **B8** is detect.

| Pos | Side A | Side B |
|-----|---|---|
| 1 | `GND` | `GND` |
| 2 | `VCC` | `VCC` |
| 3 | `SPI_SS#` | `SPI_SS#` |
| 4 | `SPI_SCK` | `SPI_SCK` |
| 5 | `SPI_MOSI` | `SPI_MOSI` |
| 6 | `SPI_MISO` | `SPI_MISO` |
| 7 | `I2C_SDA` | `I2C_SDA` |
| 8 | `I2C_SCL` | `CART_DET#` (cart ties to `GND`, mobo pull-up) |

Flash `HOLD#` / `WP#` **tied on the cart PCB** (not on the edge). SPI programming uses the **same SPI pins** (no parallel `WE#`).

## Programming: USBasp for MCU, then MCU flashes the cart

**Yes:** one **USBasp** on **J_ISP** fully programs the **ATmega1284P** (console firmware + fuses). After that, with the ATmega **running**, that firmware flashes the **plugged-in cart** (SPI master, `PB4` = `SPI_SS#`) with the `.r01nano` game image into the **25LC1024**. Optional 24C64 work goes over I2C from the same FW.

USBasp never talks to the cart chips itself (wrong protocol: `SPI_SS#` / I2C are not on the 6-pin ISP header). The cart write is always **through the running 1284**.

```text
  USBasp --J_ISP--> ATmega1284P   (console FW, once / when updating)
                         |
                         | SPI (PB4 SS#) + I2C
                         v
                    plugged-in cart (25LC1024 + 24C64)
```

### Preferred field flow

1. **USBasp -> J_ISP:** write open console firmware (and fuses) into the 1284. While ISP holds `RESET#`, cart `SPI_SS#` stays idle (high) so the 25LC1024 stays deselected on the shared SPI lines.
2. **Unplug USBasp (or leave it idle).** Power the board, cart inserted. Console FW runs and **SPI-masters** the cart to program / verify `.r01nano`.

How the host feeds the image *into* that running FW is TBD (UART, USB CDC, Studio tool, etc.). That host link is not ISP / avrdude.

### Bench flasher (still useful)

| Port on **motherboard** | Connector | Programs |
|---|---|---|
| **J_ISP** | **2x3** vertical pin header (AVR ISP) | ATmega1284P console firmware / fuses (USBasp) |
| **J_CART** | **2x8** card-edge female | Play socket. Also the face a bench tool uses for direct cart SPI/I2C |

| Port on **Nano flasher** (bench PCB) | Connector | Programs |
|---|---|---|
| Cart slot | Same **2x8** EDAC-class | `.r01nano` into 25LC1024 + optional 24C64 (no console required) |
| Console ISP lead | **2x3** ISP cable / header | Same USBasp/Atmel-ICE pinout as J_ISP |

**One hardware flasher** = USB MCU (or host + USBasp dock) with **both** a 2x8 cart socket and a 2x3 ISP header. Use it for blank carts, recovery, or before console FW cart-write exists.

Motherboard **J_ISP** stays for field console updates without removing the DIP.

## Connectors (motherboard, locked intent)

All bring-up I/O uses **vertical 2.54 mm pin headers** unless noted.

| Ref | Connector | Pins | Nets |
|-----|---|---|---|
| **J_BARREL** | **CUI PJ-063AH** (2.1 mm ID), same as full Retr01 | n/a | Tip = +5 V in, sleeve = GND ([`docs/passive_rf_etc.md`](../../docs/passive_rf_etc.md)) |
| **J_PAD** | **2x10** vertical pin header | 20 | P1 left col + P2 right col (`Px_D0..D7`), dual `GND`, key/NC (microswitches to GND) |
| **J3 / J4** | **Switchcraft 35RAPC2BVN4** vertical TRS | 5 each | Tip=`+5V` (PPTC), Ring=`PAD_DATA`, Sleeve=`GND` ([`controllers.md`](../../docs/controllers.md)) |
| **J_PWR** | **2x2** vertical pin header | 4 | `+5V`, `GND`, `RESET#`, `NC` (bench power/reset access) |
| **J_AV** | **2x4** vertical pin header | 8 | `R`, `G`, `B`, `CSYNC`, `AUD`, `AGND`, `VGND`, key/NC (bench RGBS) |
| **J8** | **CUI RCJ-012** black RCA | 2 | Mono `AUD` tip / shell GND |
| **J9** | **CUI RCJ-014** yellow RCA | 2 | NTSC `COMPOSITE_OUT` tip / shell GND |
| **J_ISP** | **2x3** vertical pin header | 6 | Standard AVR ISP: `MOSI`, `MISO`, `SCK`, `RESET#`, `VCC`, `GND` |
| **J_CART** | EDAC-class **2x8** vertical card edge | 16 | See cart table |

**J_AV notes:** Bring-up / scope RGBS + AUD. Same `R`/`G`/`B`/`CSYNC` guns feed the AD725. `CSYNC` is H+V resistor-mix (FW XOR later). `AGND` / `VGND` star to plane near the connector.

**AV encode:** **U725** = **AD725ARZ** soldered direct (wide SOIC-16, only SMD IC). **Y3** = Abracon **ACH-14.31818MHZ-EK**. COMP -> 75 ohm -> **J9**. Same electrical recipe as full Retr01 ([`docs/passive_rf_etc.md`](../../docs/passive_rf_etc.md)).

**J_PAD notes:** One ribbon-friendly **2x10**. Bit *n* is paired across columns. Full pin table: [`pinmap.md`](pinmap.md).

**TRS notes:** Same jack + 3-wire protocol as Retr01-C (**35RAPC2BVN4** on VN4 CD holes only, not arbitrary 3.5 mm geometries). Full footprint / pad map: [`docs/passive_rf_etc.md` VN4 TRS](../../docs/passive_rf_etc.md#vn4-trs-footprint-authoritative). Arcade **J_PAD** and TRS **J3/J4** coexist. Shell/BOM chooses which path you use. Software pad bytes stay the same bitfield.

## Motherboard floorplan sketch

```text
+--------------------------------------------------+
| [J_BARREL]  [J_ISP 2x3]  [J_PWR 2x2]  [J3] [J4]  |
|              ATmega1284P DIP-40                  |
|           xtal + decoupling                      |
|   FG R-pack     PWM R-mix + DC block             |
| [J_AV 2x4]  [J8 aud] [J9 comp]  [J_CART 2x8]     |
|         [U725 SOIC] [Y3 14.3]                    |
|              [J_PAD 2x10 arcade]                 |
+--------------------------------------------------+
```

## Passiveives / other parts (reasonable v1 estimate)

Outside the ICs. Counts are order-of-magnitude for SKiDL BOM planning.

| Class | Est. qty | Role |
|---|---|---|
| 100 nF X7R (MCU, flash, EEPROM, local) | **8-12** | HF bypass at every VCC pin |
| 1-10 uF ceramic bulk | **2-4** | Island / post-barrel bulk |
| Bulk electrolytic / polymer at barrel | **1** | Input reservoir |
| Reverse-polarity diode or P-FET ideal diode | **1** | Barrel abuse |
| Optional PPTC on barrel | **1** | Cable fault |
| 20 MHz crystal | **1** | MCU clock |
| Crystal load caps | **2** | Per crystal datasheet |
| I2C pull-ups (SDA/SCL) | **2** | Typically 4.7 kohm to 5 V |
| RESET pull-up (+ optional RC) | **1-2** | Open RESET# |
| Cart `CART_DET#` pull-up | **1** | |
| Series R on SPI/I2C to cart edge (optional ESD) | **4-8** | Soften edges / TVS companion |
| TVS at barrel / cart / headers (bring-up: light) | **2-6** | Touchable nets |
| FG resistor network (3-bit -> RGB + sync) | **1 network or ~10 discretes** | 8 FG colors + black |
| PWM mix resistors + DC block cap | **4-6** | Music + SFX -> `AUD` -> J_AV + J8 |
| AD725 AC couple / YTRAP / 75R / analog ferrite | **~10** | Same class as full Retr01 |
| TRS PPTC + series R + pull-up + local C | **~7** | J3/J4 path |
| ISP / header pin shrouds | as needed | Polarized 2x3 preferred |

**ICs (recap):** ATmega1284P **PDIP-40**. Cart **25LC1024 PDIP-8** + **24C64 PDIP-8**. AV: **AD725ARZ** wide SOIC-16 (direct) + **ACH-14.31818** can. See [cart IC packages](#cart-ic-packages-hand-buildability).

## Pad bit layout

Same spirit as full Retr01 `$FE60` / `$FE61` (bit set = pressed):

| Bit | Button |
|-----|---|
| 0 | Right |
| 1 | Left |
| 2 | Down |
| 3 | Up |
| 4 | X |
| 5 | Y |
| 6 | Coin / Select |
| 7 | Start |

## Power

- **5 V** from barrel for bring-up (logic level of the 1284 @ 20 MHz).
- USB-C power-only remains an optional later shell feature. **Barrel is the locked v1 inlet**.
- ISP is the recovery path for console firmware.

## Planned later (not in v1 netlist / PCB)

These are intentional follow-ons beyond the current SKiDL bring-up.

| Feature | Intent | Parent Retr01 reference |
|---|---|---|
| **TRS TVS / full ESD** | Populate TVS packs on Tip/DATA like parent `--full-esd` | [`docs/passive_rf_etc.md`](../../docs/passive_rf_etc.md) |
| **Light gun** | Same TRS bus / protocol family as pads (CRT accessory roadmap) | [`docs/lightgun.md`](../../docs/lightgun.md) |
| **RCA shell polish** | Final connector placement / silkscreen for console shell | - |

v1 already includes **J_AV**, **J8/J9** RCA, **AD725**, **J_PAD**, and **J3/J4** TRS. Pad byte contract matches full Retr01 so TRS pads and arcade headers share game I/O meaning.

## Bring-up order

1. Video kernel on a 1284 breakout (RGBS on **J_AV**, no cart yet)
2. SPI memory on a breakout as a fake cart
3. First cute cart PCB + 2x8 slot
4. Dual-port flasher (cart socket + ISP)
5. Populate **U725/Y3** and verify **J9** composite, then **J8** mono
6. TRS pad boards on **J3/J4** (console FW UART poll)
7. Refine motherboard outline from the **100 x 100 mm** starting target

## Non-goals for v1 PCB

- Full Retr01 36-pin cart compatibility
- MIDI
- Complex PMIC / Li-ion
- Light-gun accessory (roadmap only)

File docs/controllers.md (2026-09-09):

# Retr01 Controllers

Input paths for the **shared motherboard** (arcade **Retr01-A** and console **Retr01-C**). Software contract is always **`$FE60`** (P1) and **`$FE61`** (P2): bit set = pressed. Layout: [`graphics.md`](graphics.md#graphics-fexx-ports).

**Related:** [`hardware.md`](hardware.md) (pads section, [runners vs silicon](hardware.md#runners-today-vs-silicon-target)). TRS jack passives: [`passive_rf_etc.md`](passive_rf_etc.md). Light gun extension (roadmap): [`lightgun.md`](lightgun.md).

---

## Software bitfield (all paths)

Same mask for P1 and P2:

| Bit | Button |
|-----|---|
| 7 | Start |
| 6 | Coin |
| 5 | Y |
| 4 | X |
| 3 | Up |
| 2 | Down |
| 1 | Left |
| 0 | Right |

**1 = pressed**, **0 = released**.

The **ATmega1284P** owns pad sampling and presents bytes at `$FE60` / `$FE61`. The W65C02S only reads those ports.

---

## Retr01-A: Arcade (direct GPIO)

Sticks and buttons are **microswitch-to-GND** circuits into the **ATmega1284P**. Each switch closes its signal pin to the header **GND**.

| Item | Spec |
|---|---|
| MCU | ATmega1284P samples GPIO and packs `$FE60` / `$FE61` |
| Harness | Series **47 ohm** per signal (in SKiDL). TVS optional at layout |
| TRS jacks | May be **DNP** on pure cabinet builds |

No serial protocol on this path. Debouncing is firmware policy on the 1284.

### Locked headers (schematic freeze)

Three connectors on the motherboard:

| Refdes | Part | Role |
|---|---|---|
| **J5** | **1x10** pin header, 2.54 mm | Player 1 controls |
| **J6** | **1x10** pin header, 2.54 mm | Player 2 controls |
| **J7** | **1x4** pin header, 2.54 mm | Cabinet **+5 V / GND / RESET** |

Pin 1 is marked on the silkscreen (square pad). Headers face the cabinet harness edge.

#### J5 - Player 1 (1x10)

Pin order matches the `$FE60` bitfield (**LSB = pin 1**):

| Pin | Net | `$FE60` bit | Switch |
|-----|-----|---|---|
| 1 | `P1_RIGHT` | 0 | Right |
| 2 | `P1_LEFT` | 1 | Left |
| 3 | `P1_DOWN` | 2 | Down |
| 4 | `P1_UP` | 3 | Up |
| 5 | `P1_X` | 4 | X |
| 6 | `P1_Y` | 5 | Y |
| 7 | `P1_COIN` | 6 | Coin |
| 8 | `P1_START` | 7 | Start |
| 9 | `GND` | - | Switch common |
| 10 | `GND` | - | Switch common (spare) |

#### J6 - Player 2 (1x10)

Same physical order as J5 for `$FE61`:

| Pin | Net | `$FE61` bit | Switch |
|-----|-----|---|---|
| 1 | `P2_RIGHT` | 0 | Right |
| 2 | `P2_LEFT` | 1 | Left |
| 3 | `P2_DOWN` | 2 | Down |
| 4 | `P2_UP` | 3 | Up |
| 5 | `P2_X` | 4 | X |
| 6 | `P2_Y` | 5 | Y |
| 7 | `P2_COIN` | 6 | Coin |
| 8 | `P2_START` | 7 | Start |
| 9 | `GND` | - | Switch common |
| 10 | `GND` | - | Switch common (spare) |

#### J7 - Power / reset (1x4)

Shared cabinet feed for lamps / coin door / front-panel reset. **Does not** replace the barrel jack (J1). It is a harness tap from the post-ferrite **+5 V** rail.

| Pin | Net | Role |
|-----|-----|---|
| 1 | `+5V` | Fused board 5 V out to cabinet |
| 2 | `GND` | Ground |
| 3 | `RESET_N` | Active-low reset (momentary to GND). Ties into HC14 / `RESB` reset tree |
| 4 | `GND` | Ground (return / keying spare) |

**Why 10 + 10 + 4:** eight bitfield lines need eight pins. Dual GND on each player header simplifies harness commons without a third connector. Power and reset stay off the control ribbons so a shorted stick wire cannot backfeed the rail through a signal pin.

---

## Retr01-C: Aux pads (3-wire + ATtiny85)

Console builds populate **2x Switchcraft 35RAPC2BVN4** TRS jacks (P1, P2, vertical). Optional **pad boards** use an **ATtiny85** and a **male-male 3.5 mm aux** cable (no proprietary tether).

### Cable (3 conductors)

| Conductor | Signal |
|---|---|
| Tip | **5 V** (jack pad **4**) |
| Ring | **DATA** (jack pad **2**) |
| Sleeve | **GND** (jack pad **1**, shell) |

Pads **3** and **5** are plated for mechanical hold on the VN4 footprint. They are **NC** on **35RAPC2BVN4** (no internal switches). Exact tip/ring assignment is fixed at schematic time. Protection (PPTC on VCC, TVS, series R on DATA): [`passive_rf_etc.md`](passive_rf_etc.md).

**Footprint intent:** **one** Switchcraft **VN4 CD** hole pattern only (5x oval pill slots, drill 0.90 x 2.00 mm, Y-long. Datasheet "slots" are terminal tabs, not PCB holes. Datasheet recommended round hole is dia 2.00 mm). Fits **2BVN4** (locked) and mechanically **3BVN4** / **4BVN4**. Pads **3** and **4** must stay copper-separate (no peanut short). **Not** a generic dual footprint for inline-3 or unrelated 2+1 jacks. Full detail: [`passive_rf_etc.md` VN4 TRS footprint](passive_rf_etc.md#vn4-trs-footprint-authoritative).

### Electrical: open-drain UART bus

| Item | Spec |
|---|---|
| Pull-up | **4.7 kohm** on **DATA** at the **motherboard** (1284 side) |
| Host | ATmega1284P UART TX/RX tied together, **open-drain** |
| Pad | ATtiny85 UART TX/RX tied together, **open-drain** |
| Topology | Half-duplex **1-wire UART** on the DATA line |

Both ends release high (idle). Either side pulls low to transmit.

### Protocol

| Parameter | Value |
|---|---|
| Baud | **115200** 8N1 |
| Frame budget | **< 200 us** per exchange (fits in **VBlank**) |
| Poll (host -> pad) | Host sends **1 byte**: **`0x55`** = P1 poll, **`0xAA`** = P2 poll (**locked**) |
| Reply (pad -> host) | Pad samples buttons, then sends **1 byte** state using the bitfield table above |

**Per-frame sequence (once per vertical blank):**

1. 1284 asserts open-drain TX and sends poll byte.
2. Target ATtiny receives poll. If addressed, drives reply byte on DATA.
3. 1284 captures reply into shadow for `$FE60` or `$FE61`.

Pads that miss a poll hold last state until the next good frame.

### Pad MCU

| Item | Spec |
|---|---|
| Part | **ATtiny85** (pad PCB) |
| Power | **5 V** from Tip (through port PPTC on mobo) |
| Buttons | Active-low into GPIO. Firmware packs the bitfield |

### Bring-up status

| Layer | Status |
|---|---|
| Silicon / docs | Protocol locked (this file) |
| Sim / emu | **Arcade** (default): Host Play drives `$FE60`/`$FE61` directly. **Pads**: Sim ATtiny85 entities + poll/reply into those ports (HUD ARCADE/PADS toggle). No TRS netlist / 1284 USART yet |
| Firmware | 1284 pad firmware + ATtiny85 pad sketch. Post-schematic. Flash tools: [`programming.md`](programming.md) |

---

## Open topics (controllers)

| Topic | Note |
|---|---|
| Debounce | Pad-side vs 1284-side threshold |
| Light gun | Identify **`0x02`**, timer read **`0x5A`**. See [`lightgun.md`](lightgun.md) |
| Arcade series-R / TVS footprints | **47 ohm** in SKiDL. Optional TVS at layout |

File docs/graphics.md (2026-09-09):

# Retr01 Graphics

How the picture is built: VRAM workbench, BG fetch, sprites, palettes. Software-visible behavior lives here.

**Related:** [`memory.md`](memory.md) (cart layout, chip timing). [`hardware.md`](hardware.md) (BOM, beam path).

---

## Display

| Item | Value |
|---|---|
| Logical playfield | **128x120** (**16x15** tiles). Games and Studio work here |
| RGBS active field | **256x240** inside **341x262** |
| Clocks | CPU **8.000 MHz**, dot **5.369318 MHz**, ~**60.098 Hz** |
| SCALE DIP | **2x** default (fills CRT). **1x** centers 128x120. Not a `$FExx` bit |

Games author and scroll in **128x120**. Hardware scales that rectangle into the RGBS field. Emulators draw the logical field (often presented 2x for pixels).

---

## Tiles (CHR)

| Item | Value |
|---|---|
| Size | **8x8** pixels |
| Depth | **2 bpp** (color index **0-3** inside a 4-color palette) |
| Bytes | **16** per tile (NES-style bitplanes) |
| Banks | **4** BG + **4** sprite per world (**256** tiles each, **4 KB**/bank) |

Layout of one tile:

```text
 bytes 0-7   bitplane 0 (LSB of color index), one byte per row
 bytes 8-15  bitplane 1 (MSB of color index), one byte per row
 bit 7 = leftmost pixel
```

Color index **0** is transparent for sprites and shared backdrop for BG. Final RGB comes from active palette indices -> board Color PROM. CHR lives in **cart flash**, not CPU address space. Attr **BANK** bits pick which of the four banks supplies the tile.

---

## VRAM workbench

Eight live nametable slots in 32 KB VRAM. Each slot **512 B** (**480 B** used: 240 tile + 240 attr at `+0xF0`, **32 B** pad).

| Slots | Role |
|---|---|
| **0-3** | BG1 camera field (**2x2**, main playfield) |
| **4-7** | BG0 camera field (**2x2**, second BG behind BG1) |

**BG1** is the normal graphics layer: the playable, navigable screens (camera, collision, platforms). **BG0** is the second background behind that main BG. It shows through where BG1 uses color index **0**. This BG is not interactive for the player. Details: [Second background (BG0)](#second-background-bg0).

Scroll `$FE02`/`$FE03` (BG1): **0-127** / **0-119**. Scroll `$FE06`/`$FE07` (BG0): same ranges for the far plane. Hardware does **not** auto-load MAP. Crossing a screen border = software streams **480 B**/screen via `$FE12` (or MAP `$FE93` -> VRAM).

**How BG1 scroll works in practice:**

1. Keep four neighboring playfield screens loaded in slots **0-3** (the 2x2 workbench).
2. Write BG1 scroll latches as the camera moves inside that 128x120 window.
3. When the camera would leave the workbench, stream the newly needed screen(s) into the far slots (interleaved VRAM writes), then keep scrolling.
4. Mid-frame scroll changes apply on the **next** tile fetch.

```text
+-------------+-------------+
|  Slot 0     |  Slot 1     |
+-------------+-------------+
|  Slot 2     |  Slot 3     |
+-------------+-------------+
        ^ 128x120 viewport (BG1 scroll)
```

```text
MAP grid (6 screens)             VRAM slots (2x2 load)
+-----+-----+-----+              +---------+---------+
|  A  |  B* |  C  |              | 0: B    | 1: C    |
+-----+-----+-----+              +---------+---------+
|  D  |  E  |  F  |  player -->  | 2: E    | 3: F    |
+-----+-----+-----+              +---------+---------+

 With zero scroll values for X and Y, VRAM sees B, C, E and F.

 If we scroll left a bit, VRAM loads:

+---------+---------+
| 0: A    | 1: B    |
+---------+---------+
| 2: D    | 3: E    |
+---------+---------+
```

| VRAM offset | Use |
|---|-----|
| `$0000`-`$07FF` | BG1 camera slots 0-3 |
| `$0800`-`$0FFF` | BG0 camera slots 4-7 |
| `$1000`-`$3FFF` | Scratch |
| `$4000`-`$7FFF` | Reserved |

**Streaming cost:** ~480 B per screen (~**11** CRT lines @ ~12 cyc/B with interleave). Scroll 1 px = 1-2 latch writes. See [`memory.md`](memory.md) for PHI2 CPU/PPU phases.

---

## Background fetch (hardware)

Each visible dot:

1. Beam + BG1 scroll ---> VRAM tile index + attr byte (slots 0-3).
2. Attr **BANK** (bits 1-0) ---> cart CHR tile fetch.
3. Attr **PAL** + active palette row ---> master index ---> **Color PROM** (board).
4. Compositor picks sprite vs BG1 vs BG0 vs backdrop (see **Second background** below).

Mid-frame scroll applies on the **next** tile fetch. Do not edit a nametable cell under the beam (tear).

```text
BG attr byte
7 6 5 4 3 2 1 0
| | | | | | |_|__ BANK 0-3   (hardware)
| | | | |_|______ PAL 0-3    (hardware)
| | | |__________ FLIP_H     (hardware)
| | |____________ FLIP_V     (hardware)
| |______________ SOLID      (software only, video ignores)
|________________ ANIM       (software only, 4-frame strip B..B+3)
```

`$FE31`-`$FE37` optional bank **stamp** helpers. Live fetch uses per-tile / per-OAM attr bits.

---

## Sprites

**128** OAM entries via `$FE20`/`$FE21` in **1284**. Entry: `Y, tile, attr, X` (**512 B** total).

```text
OAM attr byte (all bits hardware - 1284 sprite field / compositor)
7 6 5 4 3 2 1 0
| | | | | | |_|__ BANK 0-3
| | | | |_|______ PAL 0-3
| | | |__________ FLIP_H
| | |____________ FLIP_V
| |______________ PRIORITY
|________________ SIZE (0=8x8, 1=8x16 tile pair)
```

**`$FE20` / `$FE21`:** `$FE20` loads pointer bits **[7:0]** and clears bit **8**. `$FE21` data auto-incs a **9-bit** pointer that wraps at **512**, so a sequential fill from `$FE20=0` covers all 128 entries. Cap **16** sprites per **logical** scanline (unchanged).

**Locked raster split (with BG0):** fill the **full 120x128** sprite field in **VBlank** (Y-buckets of 8 px, then plot). Give **HBlank** to BG0 line fill. Beam reads sprite pixels from the field during active display. Where BG1 color index is **0**, the compositor shows the prepared BG0 line (BG1 mask / show-through).

**VBlank budget (1284 @ 20 MHz):** ~20 scanlines of vertical blank, about **25,000** CPU cycles. With **128** OAM + Y-buckets, field fill targets about **12-16k** cycles (~50-65%). Sim models this as `linebuf_oam_fill_field` and records `oam_fill_cycles_est`. Entity / metasprite expansion on the 1284 is the next phase ([`temp/128_sprites_and_entities_design.md`](../temp/128_sprites_and_entities_design.md)).

```text
Priority (opaque wins):
  sprite  >  BG1  >  BG0  >  backdrop
```
---

## Palettes

Two layers: **cart indices** and **board Color PROM**.

1. **Cart** stores 8 global BG rows + 8 global sprite rows (**256 B** total). Each entry is a **6-bit master index** (0-63), not RGB.
2. **Active row:** software picks row N (often via `$FE38` hint) then copies **4 BG + 4 sprite** palettes (**32** indices) into `$FE08`/`$FE09`.
3. **Color PROM (board):** 64 entries of packed **R3G3B2**. Studio quantizes kit swatches when burning the PROM.
4. **Shared color 0** across all 8 active palettes (backdrop / BG1 show-through / sprite transparency).

`$FE08` = address into the 32-byte active buffer. `$FE09` = data with auto-inc. No `$FE08`/`$FE09` load at boot = undefined colors until PRG writes them. Phase 1 boot PRG streams the start row from cart pals.

---

## Second background (BG0)

**Pitch:** Retr01's SNES-like parallax plane. BG1 is the playfield. BG0 is a real second tilemap that scrolls underneath wherever BG1 uses palette index **0**. Make the far world's present bbox smaller than BG1's and you get slower motion for free (`scroll_BG0 = scroll_BG1 * extent_BG0 / extent_BG1`). Not a mapper IRQ trick. Compositor show-through every dot (Sim / silicon). Emu Host Play composites the same order in the full-frame renderer. Selling narrative: [`selling_points.md`](selling_points.md#snes-like-parallax-bg0).

Structured far plane (**BG0**) behind the main BG. **BG1** is the normal playable/navigable playfield.

This **replaces** the old two-slot parallax payload model (former slots 4-5 only, Single / Pair H / Pair V).

| Item | Value |
|---|---|
| Layout | Up to **8** present screens anywhere on the **16x16** map. Scroll ratio uses the enclosing present bbox |
| Live window | VRAM slots **4-7** (2x2), same MAP stream path as BG1 |
| Scroll | `$FE06` / `$FE07` (0-127 / 0-119 inside the BG0 workbench) |
| Cart | Up to **8** present BG0 screens per world (dir + **480 B** payloads after BG1 MAP). Dir coords are bbox-origin relative |
| Authoring | Studio Worlds: BG1/BG0 sub-button. Place screens freely on the **16x16** chess (max **8** present) |

### Show-through

Where BG1 palette index is **0**, the compositor shows the BG0 pixel (else backdrop if BG0 is also transparent). **Missing / unloaded BG1 VRAM slots** (outside the present-screen world bbox streamed into the 2x2 workbench) show **backdrop**, not BG0 - only true color-0 show-through reveals the far plane.

```text
if sprite opaque      -> sprite
else if BG1 index != 0 -> BG1
else                  -> BG0 (or backdrop)
```

Emu Host Play composites BG0 under BG1 color 0 from the cart BG0 cache in the full-frame renderer. Sim prepares each BG0 line in **HBlank** and applies the BG1 color-0 mask on active dots. Silicon target matches that split (VRAM slots 4-7 + cart CHR on the BG0 path).

### Proportional scroll (parallax)

Default is software (6502 or Host Play), not a PLD auto-ratio. This is the **parallax depth** knob:

```text
scroll_BG0_x = scroll_BG1_x * cols_BG0 / cols_BG1
scroll_BG0_y = scroll_BG1_y * rows_BG0 / rows_BG1
```

`cols_*` / `rows_*` are the **enclosing present extents** of each plane (used screens bbox), not the virtual **16x16**. Example: BG0 **2x2**, BG1 **4x4** -> BG0 scrolls at half rate on both axes (mountains crawl while the playfield runs). If `cols_BG0 == 1`, X stays 0 (same for rows). If BG0 extent is **equal or larger** than BG1 on an axis (`cols_BG0 >= cols_BG1`), that axis does not scroll. Absolute BG0 scroll override is allowed for cutscenes.

World/screen/cart caps: [`memory.md`](memory.md) (**48** BG1 present/world, **16x16** virtual grid, cell coords as nibbles).

---

## Graphics `$FExx` ports

| Addr | Name | Role |
|---|---|---|
| `$FE00` | `PPUCTRL` | See [bitfield](#ppuctrl-fe00) |
| `$FE01` | `PPUSTATUS` | bit7 VBlank, bit6 raster hit (read clears latched bits) |
| `$FE02`/`$FE03` | BG1 scroll X/Y | 0-127 / 0-119 inside the BG1 2x2 workbench |
| `$FE04`/`$FE05` | raster / IRQ | Scanline compare Y (`$FE04`) + raster control (`$FE05`) |
| `$FE06`/`$FE07` | BG0 scroll X/Y | 0-127 / 0-119 inside the BG0 2x2 workbench |
| `$FE08`/`$FE09` | pal addr/data | Active master indices (**32 B**), auto-inc on `$FE09` |
| `$FE10`-`$FE12` | VRAM addr/data | hi, lo, data auto-inc (interleaved) |
| `$FE20`/`$FE21` | OAM addr/data | auto-inc into 1284 OAM |
| `$FE22`-`$FE24` | cart EEPROM | Save mailbox via 1284 ([`memory.md`](memory.md)) |
| `$FE30` | `WORLD` | Active world index **0-7** (select helper) |
| `$FE31`-`$FE37` | bank helpers | Optional attr stamps |
| `$FE38` | `PAL_ROW` | Palette row hint (software still copies `$FE08`/`$FE09`) |
| `$FE40`-`$FE5F` | APU | Bytecode window to 328P ([`sound.md`](sound.md)) |
| `$FE60`/`$FE61` | pads P1/P2 | Bit set = pressed ([`controllers.md`](controllers.md)) |
| `$FE70`-`$FE72` | machine EEPROM | 1284 internal EEPROM mailbox ([`memory.md`](memory.md)) |
| `$FE90`-`$FE93` | MAP | Cart seek + read auto-inc ([`memory.md`](memory.md)) |

`$FE80` unused.

### `PPUCTRL` (`$FE00`)

**Silicon target** bitfield:

| Bit | Name | Meaning |
|-----|---|---|
| 7 | NMI_EN | **1** = assert CPU **NMI** on VBlank |
| 6-5 | L1_CAM | BG1 camera mode: **00** clamp, **01** wrap H, **10** wrap V, **11** wrap both |
| 4-3 | L0_CAM | BG0 camera mode (same encoding) |
| 2 | SPR_EN | Sprites enable |
| 1 | L0_EN | Layer 0 / BG0 enable |
| 0 | L1_EN | Layer 1 / BG1 enable |

**Runners today (Emu):** **L1_EN**, **L0_EN**, **SPR_EN**, and **NMI_EN** affect rendering. Camera-wrap bits (4-3, 6-5) are stored but not enforced yet. See [`hardware.md`](hardware.md#runners-today-vs-silicon-target).

### `$FExx` ownership

Critical real-time bytes are registered inside existing ATF22V10s. Soft bytes live on the ATmega1284P. Software writes the same `$FExx` addresses either way.

| Port | Owner | Notes |
|---|---|---|
| `$FE02` | UPLDB (scroll X reg) | Load on `SEL_FE02` + CPU D. Used every beam/dot. |
| `$FE03` | UPLDX (scroll Y reg) | Load on `SEL_FE03`. |
| `$FE04` | UPLDY (raster Y reg) | Internal compare vs beam Y. `EQ#` -> IRQB. No external Q hop. |
| `$FE00` | ATmega1284P soft | `PPUCTRL` |
| `$FE05` | ATmega1284P soft | Raster control |
| `$FE06` / `$FE07` | ATmega1284P soft | BG0 scroll (already soft) |
| `$FE08` | ATmega1284P soft | Palette address |
| `$FE90`-`$FE92` | ATmega1284P soft | Full 24-bit MAP seek |
| `CART_A0`-`A13` | W65C02S `CPU_A` | Unchanged direct to J36 |
| `CART_A14`-`A18` | UPLDV registered export | Hard pin path for MAP high bits (1284 GPIO budget exhausted). Loaded from CPU D on `SEL_FE91`/`FE92`. |

Ports **not** in this table (`$FE09` palette data, `$FE10`-`$FE12` VRAM, OAM, APU, mailboxes) use other paths (MCU, qualified strobes, or direct read ports).

**Sim note:** soft `$FExx` on `R01sBoard` (`peek_fe` / `poke_fe`) and health under island L (1284). No separate soft-$FExx DIP island on the Sim canvas. See [runners vs silicon](hardware.md#runners-today-vs-silicon-target).

**Fitter escape:** if product terms or pins overflow on the three PLDs holding 24 scroll/raster bits, add +1 ATF22V10 for those bits only.

---

## Resolved topics

| Topic | Resolution |
|---|---|
| `PPUCTRL` camera bits | Bitfield above |
| `$FExx` ownership | table above |
| 8x16 sprite VBlank timing | ~12-16k / ~25k cycles at 128 OAM ([sprites](#sprites)) |
| BG0 HBlank fill | Next BG0 line into linebuf `$4000` ping-pong. BG1 color-0 mask on active dots |

| Topic | Still open |
|---|---|
| BG `ANIM` rate | Global vs per-game |
| Living-tile list cap | **32** vs **64** cells (`retr01_ANIM_MAX`) |

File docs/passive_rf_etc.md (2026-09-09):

# Retr01 Passives, Ports, and RF

Non-IC parts and board-level RF / EMC practice. ICs, bus architecture, and island bring-up stay in [`hardware.md`](hardware.md) (that doc is chip-focused on purpose).

**Related:** [`hardware.md`](hardware.md) (23-IC BOM, islands). [`sound.md`](sound.md) (APU DAC). [`cart.md`](cart.md) (36-pin edge). Color PROM: [`hw/md/AT27C256R.md`](../hw/md/AT27C256R.md). Pads: [`controllers.md`](controllers.md).

Power assumption: **stable external 5 V** (barrel / PSU). No on-board switching regulator in the baseline. Passives are **outside** the 23-IC goal.

---

## What actually bites first

RF emissions are real, but they rarely keep a discrete 5 V game board from **booting and painting**. Function-first risks are usually **propagation delay** across HC / PLD / SRAM paths (datasheet ranges, worth simulating). MCU clocks sit mostly **inside** the package. Board clocks (PHI2, dot) matter more for layout than for "will it work."

Take CE / FCC seriously when selling into regulated markets. Until then, prefer **direct traces**, a **continuous return path**, and comparative RF checks over over-engineering every harmonic.

---

## 4-layer stackup (return path first)

The highest-frequency content on this board is not the clock fundamental. It is the **harmonics of sharp digital edges**. Those currents need a **continuous, nearby return**.

**Avoid** the common trap **signal-power-ground-signal**:

- HF return wants to hug the adjacent plane.
- A layer change from top signal to bottom signal jumps the return from the power plane to the ground plane (or vice versa).
- That discontinuity radiates.
- Stitch caps between power and ground can pass some of that return (high-pass between planes), but real caps have inductance. The **highest** frequencies still see an open. Cap impedance vs frequency is **V-shaped**. Audio "bypass" intuition does not map cleanly onto digital edge harmonics.

**Target stackup for Retr01** (motherboard and cartridge):

| Layer | Role |
|---|---|
| Top | Signals + **5 V pours** (flood around traces, pour last) |
| Inner 1 | **GND** |
| Inner 2 | **GND** |
| Bottom | Signals + **5 V pours** as needed |

Both inners as ground keeps a solid reference under every signal layer and avoids power-plane return hops. Distribute 5 V with shapes on the outer layers, not a dedicated mid-board power plane.

Still: keep high-activity nets relatively **direct**, return to ground **ASAP** (vias, stitching at connectors and under DIPs), and keep clocks / bus runs off long pad-port cables.

---

## Propagation delay (functional, not RF)

Before chasing antennas, budget chip-to-chip delay:

- PHI2 / decode / HC245 / latch / SRAM / PLD paths must close inside the 8 MHz and dot-clock windows.
- Use datasheet **min/typ/max** propagation. Worst-case stacks matter more than RF folklore.
- Sim (`app/sim`): default is zero-delay for catchup. Opt in with **`./sim ... DELAY=typical|max`** (or env `R01S_PROP_DELAY`) to print HC/PLD/SRAM path budget vs PHI2 half. Pin netlist stays combinatorial. See `tests/test_timing.c` and [`PERFORMANCE.md`](../app/sim/PERFORMANCE.md).

---

## Power entry and rail hygiene

External 5 V is trusted for regulation, not for abuse or cable noise. Treat the barrel as a noisy entry.

| Item | Role |
|---|---|
| Barrel jack (**CUI PJ-063AH**, 2.1 mm ID) | 5 V in (shared motherboard) |
| Series PPTC on VIN | Board-level short / overload. Hold above full-board idle, trip on hard short |
| Reverse-polarity diode (or P-FET ideal diode) | Blocks reverse barrel plug |
| Bulk cap at entry (**220 uF** low-ESR electrolytic or polymer, locked) | Holds rail through plug bounce and load steps |
| Input ferrite (or CMC on 5 V / GND pair) | Damps cable-borne RF before the pours |
| Local **100 nF X7R** on every IC VCC pin (mm from pin) | HF bypass. Mandatory for HC / PLD / AVR edge rates |
| Local **4.7 uF** ceramic per island / large DIP (default in 1-10 uF class) | Mid-band reservoir (6502, 1284, 328P, PLD cluster, SRAM bank) |
| Ferrite + **10 uF** into **analog / video** spur | Isolates Color PROM DAC and APU DAC from digital di/dt |

Never snake return current through video or pad-port copper. Stitch GND vias at every connector shell and under each DIP.

**Package policy:** mobo passives are **THT** (axial R, disc ceramic C, radial electrolytic where noted, axial TVS/inductor). The only intentional SMD silicon is **AD725ARZ** (wide SOIC-16).
- **Full Retr01** mobo: DIP-16 holes + **Proto Advantage PA0006** (SOIC-to-DIP). First spin stays hand-solderable THT via that adapter.
- **Nano** mobo: solder **AD725ARZ** direct (`Package_SO:SOIC-16W_7.5x10.3mm_P1.27mm`). Only SMD IC on that board.
Retr01-H may revisit more SMD later.

**KiCad footprints** (from `bom.py`): standing axials for density. R `Resistor_THT:R_Axial_DIN0207_L6.3mm_D2.5mm_P2.54mm_Vertical`, ESD TVS stand-in `Diode_THT:D_DO-35_SOD27_P2.54mm_Vertical_CathodeUp`, reverse Schottky `Diode_THT:D_DO-41_SOD81_P2.54mm_Vertical_CathodeUp`, YTRAP L `Inductor_THT:L_Axial_L11.0mm_D4.5mm_P5.08mm_Vertical_Fastron_MECC`. PPTC / ferrite beads reuse the resistor axial hole pattern until a THT MPN is locked.

### Footprint audit (KiCad vs locked silicon)

| Class | Verdict |
|---|---|
| **ATF22V10**, **ATmega328P** | `DIP-*_W7.62mm` (300 mil). Was wrongly 600 mil until fixed |
| **AS6C62256**, **AT27C256R**, **SST39SF040**, **W65C02S**, **ATmega1284P** | `DIP-*_W15.24mm` (600 mil). Correct |
| **74HC*** | `DIP-*_W7.62mm`. Correct |
| **Y1-Y3** ACH half-size | `Oscillator_DIP-8`. Correct |
| **Y4/Y5** ABLS7M | `Crystal_HC49-U_Vertical`. Correct |
| **U725** AD725 | Full Retr01: DIP-16 + **PA0006**. Nano: direct SOIC-16W. See locked connectors |
| **R / disc C / YTRAP L** | Vertical THT class footprints. OK for 1/4 W / disc / MECC-class |
| **Cbulk / Cva** | `CP_Radial_D8.0mm_P3.50mm`. Fine for many 10 uF. Confirm **220 uF** can body when locking MPN (some need D10 / P5.00) |
| **D1** Schottky | **DO-41** (not DO-35). 1N581x rectifier class |
| **Tvs*** | DO-35 THT stand-in. Docs target SOD-323 PESD for production SMD |
| **F1/F2/F3 PPTC**, **FB1/FB2** ferrite | Resistor-axial **stand-in** until THT MPN locked |
| **J36** | PinSocket stand-in for EDAC hole pattern |
| **J3/J4**, **J8/J9** | Custom `Retr01_Lib` (locked drawings) |
| **SW1** SCALE | 1x02 header stand-in for SPST / DIP switch |

Do not assume pin-count defaults (24/28 pin => 600 mil). Match each MPN datasheet package code (24P3 / 28P3 = 300 mil).

**Passive profiles** (`python generate.py`):

| Profile | Flag | What changes |
|---|---|---|
| **BRINGUP** (default) | (none) | No cart/TRS **TVS**. No arcade **47 ohm** series (J5/J6 wire straight to 1284). Keeps cart **33 ohm** series, R-2R, bypass, Quilter 0R bridges. |
| **FULL** | `--full-esd` | Production ESD clamps + arcade series resistors. |

Populate TVS / arcade series on a later spin or regenerate with `--full-esd` when you want the full I/O protection BOM.

### Quilter power nets (Circuit Comprehension) - motherboard

SKiDL uses per-IC `+5V_<refdes>` stubs (via `RD*` 0 ohm) so Quilter can parent each bypass cap. Quilter often auto-lists those stubs plus some signal nets as high-current / power. Fix the list before pour:

| Action | Nets |
|---|---|
| **Pour on** (only these) | `+5V`, `+5V_ANALOG` |
| **Keep listed, pour off** | every `+5V_U*`, `+5V_BULK`, `VIN_RAW`, `VIN_PROT`, `VIN_FUSED` |
| **Delete from Power Nets** | `VIDEO_R` / `VIDEO_G` / `VIDEO_B`, all `VRAM_A*` (DAC outs and address bus, not power) |

Quick rule: pour only on bare `+5V` and `+5V_ANALOG`. Everything else in that table is a stub, input chain, or a misclassified signal.

### Quilter bypass capacitors (Circuit Comprehension) - motherboard

Quilter auto-lists many caps as IC bypass. Keep only true VCC/pin bypass. Trash the rest before place/route.

| Action | Caps |
|---|---|
| **Keep** | `CD1`-`CD21` (per-IC 100 nF on `+5V_<refdes>`). `Cd725a` / `Cd725d` (U725 APOS pin **4** / DPOS pin **14**) |
| **Delete** | `Cbulk` (entry bulk, often parented to `RDbulk`). `Cva` (analog spur reservoir). `Cxtal4a`/`Cxtal4b`/`Cxtal5a`/`Cxtal5b` (Y4/Y5 **load** caps, 22 pF. Crystal Oscillators section owns those). `Cytrap` if listed (YTRAP tank C, not pin bypass) |
| **Delete (optional)** | `Cpad1` / `Cpad2` (TRS VCC after PPTC at J3/J4. Correct near the jack, wrong for the bypass engine) |

Expected keep set: **23** rows (21x `CD*` + 2x `Cd725*`). Do not chase high confidence on deleted rows. They are not IC bypass by design.

### Quilter (Circuit Comprehension) - cartridge PCB

Project: [`hw/kicad/cartridge/`](../hw/kicad/cartridge/). Same stub pattern as the mobo (`RD*` 0 ohm into `+5V_U*`), fewer parts.

**Stackup (4-layer, matches motherboard):** **F.Cu** signal - **In1.Cu** GND - **In2.Cu** GND - **B.Cu** signal. Board thickness **1.6 mm** (edge-connector mating). Inner planes are solid `GND` pours over the full board. Outers carry signals + full-board `+5V` pours (clearance around non-power finger pads). Pick Quilter's **4-layer** profile. Map inners as ground.

**Power nets:**

| Action | Nets |
|---|---|
| **Pour on** | `+5V` only on **F.Cu / B.Cu** (**Attempt Power Pour** checked). ~**500 mA** is fine |
| **Keep listed, pour off** | `+5V_U40`, `+5V_U50` (uncheck **Attempt Power Pour**) |
| **Ground** | `GND` = **Primary Ground** (planes on **In1 / In2**) |

On the cart KiCad board, `+5V` must reach **J36** A2/B2 and both **RD*** pin-2 pads (the four copper nodes on bare `+5V`). Keep `J36` seated on `Edge.Cuts` with fingers **on** the board (not hanging past the outline) or Quilter reports **Net is not fully connected**.

**Bypass capacitors:**

| Action | Caps |
|---|---|
| **Keep** | `CD1` -> U40 pin **32**, `CD2` -> U50 pin **8**, both **100 nF** (high confidence is expected) |
| **Delete** | anything else Quilter invents |

**Placement locks** (KiCad before upload): lock `J36` gold fingers and `Edge.Cuts`. Copper zones cover the full board (no tongue keepout). Details: [`hw/kicad/README.md`](../hw/kicad/README.md#cartridge-gold-fingers).

---

## Clocks and reset

| Item | Locked part / value |
|---|---|
| **Y1** PHI2 | **Abracon ACH-8.000MHZ-EK** - 8.000 MHz, 5 V HCMOS, half-size DIP-8 can (~12.7x12.7 mm). Footprint `Oscillator:Oscillator_DIP-8` (pins **1=OE, 4=GND, 5=OUT, 8=Vcc**). OE tied high |
| **Y2** dot | **Abracon ACH-5.369318MHZ-EK** - same package/footprint. Exact NTSC/3. **Primary:** Abracon factory-order. **Alternate:** any 5 V HCMOS DIP-8 XO at **5.369318 MHz +/-50 ppm**. Do **not** use 5.000/6.000 MHz for video |
| **Y3** AD725 4FSC | **Abracon ACH-14.31818MHZ-EK** - same package/footprint |
| **Y4** 1284 | **Abracon ABLS7M-20.000MHZ-D2Y-T** HC-49/U + **2x 22 pF** to GND |
| **Y5** 328P | **Abracon ABLS7M-16.000MHZ-D2Y-T** HC-49/U + **2x 22 pF** to GND |
| Series damping | **33 ohm** locked (`Rphi`, `Rdot`) on PHI2 and DOT at the can output |
| **74HC14** (outside 32-count) | Schmitt cleanup for reset / slow edges |
| RC + Schmitt (or supervisor, e.g. MCP120-class) on `/RESB` and AVR `RESET` | Power-on reset. Hold low until 5 V is solid |
| Pull-ups on open-drain resets / IRQB | Typical **4.7-10 kohm** |

Board clocks matter for layout cleanliness. They are not automatically a show-stopper for RF. Keep traces short, away from cart edge and pad jacks. No unterminated stubs.

---
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

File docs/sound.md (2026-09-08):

# Retr01 Sound

Software + hardware specification for the dedicated APU path. Channel map, DPCM, and bytecode protocol (NES-style tracker on 6502 + software mixer on AVR). Silicon: [`hardware.md`](hardware.md). Register window: **`$FE40`-`$FE5F`** ([`graphics.md`](graphics.md)).

---

## 1. Hardware architecture overview

Retr01 has **no fixed-function audio ASIC**. Roles split like the rest of the board:

| Role | Who |
|---|-----|
| Sequencer / tracker | **W65C02S** (game PRG), driven by **60 Hz NMI** |
| Synthesizer / mixer (APU) | **ATmega328P** @ 16 MHz (island **K**) |
| Analog out | 328P **8-bit digital mix** -> discrete **R-2R** (**R = 10.0 kohm**, **2R = 20.0 kohm**, 1%) + **1 kohm** / **10 uF** AC build-out ([`passive_rf_etc.md`](passive_rf_etc.md)) |

Flow:

1. The **W65C02S** streams **compressed bytecode** from cart ROM.
2. Custom **bus-bridge** logic (below) hands bytes from the 8 MHz 6502 domain to the 16 MHz AVR.
3. The **328P** mixes waveforms in software and drives the DAC.
4. The **ATmega1284P** does **not** synthesize audio (sprites, pads, machine EEPROM only).

```text
  Cart PRG / track data
        |
        v
  W65C02S  -> NMI 60 Hz ->  decompress / delay / bitmask
        |
        |  STA $FE4x...          Bus Bridge
        v
  ATmega328P APU  -> mix 8 ch ->  R-2R DAC / amp
```
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

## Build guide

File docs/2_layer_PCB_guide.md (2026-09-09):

# Two-layer PCB guide (KiCad)

A practical walkthrough for finishing a board like the Nano cart: parts placed, ratsnest visible, copper not routed yet. Aimed at **2-layer** boards in KiCad (PCB Editor).

## What a 2-layer board is

| Layer | Usual KiCad name | Typical use |
|---|---|---|
| Top copper | `F.Cu` (Front) | Most signal traces, component pads (THT pads go through both) |
| Bottom copper | `B.Cu` (Back) | Ground pour, and/or more signal traces |
| Board outline | `Edge.Cuts` | Shape of the PCB |
| Silkscreen | `F.SilkS` / `B.SilkS` | Refdes, labels (optional on bottom) |

Through-hole pads (DIPs, headers, cart fingers) have copper on **both** sides by default. Surface-mount pads live on one side only.

You only have **two** copper sheets. That is enough for many small boards if you plan pours and a few vias carefully.

## Bottom copper: ground only, or traces too?

**Both are valid.** You are not wrong.

Common patterns on 2-layer boards:

1. **Bottom mostly ground pour**  
   Large copper fill on `B.Cu` tied to `GND`. Top carries most signals. Short jumps to the bottom when the top is blocked. Best for noise, return paths, and hand soldering heat sinking.

2. **Bottom used as a second signal layer**  
   When top has no clear path from A to B, drop a **via**, run on `B.Cu`, via back up. Very normal. You may still want a ground pour in the leftover space on bottom (or top).

3. **Split roles**  
   Example: bottom = GND pour + a few power or stubborn nets. Top = SPI/I2C/signals.

What to avoid:

- Long parallel runs of fast clocks on both sides of a thin board without thinking about return path (less critical on a tiny slow SPI cart, more critical on high-speed digital).
- Leaving large floating copper islands (connect pours to a net, usually `GND`, or delete unused copper).

**Rule of thumb for Nano-style carts and bring-up mobos:** pour **GND on the bottom**, route signals on top, and use the bottom for **short escape traces** when top is crowded. That matches your mental model and is a solid default.

## Before you draw copper

1. **Open the PCB** that already has footprints + netlist (ratsnest lines).
2. Confirm **Board Setup -> Layers**: at least `F.Cu` and `B.Cu` enabled (default for 2-layer).
3. **Board Setup -> Design Rules -> Constraints**: set sensible minima for your fab (examples for cheap 2-layer):
   - Clearance ~ 0.2 mm
   - Track width ~ 0.25-0.3 mm for signals. Wider for power (0.5-1.0 mm)
   - Via diameter / drill per fab (e.g. 0.6 / 0.3 mm)
4. **Net classes** (optional): give `+5V` and `GND` a wider track class.
5. Lock **Edge.Cuts** and keep the cart finger geometry alone until routing is done.

Ratsnest is only a reminder of connectivity. Copper traces (and pours) are what the fab builds.

## Routing traces in KiCad (PCB Editor)

### Basic signal trace

1. Press **X** (or toolbar **Route Tracks**).
2. Click the starting pad (or an existing trace end).
3. Move toward the target. Click to place corners.
4. Click the destination pad to finish. Ratsnest for that connection disappears when the net is fully connected.
5. **End** / Esc exits route mode.

Tips:

- Stay on **one layer** until you need to cross something.
- Prefer short, direct runs. Avoid sharp acute angles if you can (45 deg bends are fine).
- For THT DIPs, leave room for the iron. Do not pack traces under where you need access if you hand-solder.

### Changing layer mid-route (via)

When top has no clear path:

1. While routing, press **V** to place a **via** (or switch layer with the layer hotkeys / click the layer tab).
2. Continue on `B.Cu`.
3. Via back to `F.Cu` near the destination if the pad is easier to hit from the top.

Vias are plated holes that connect `F.Cu` to `B.Cu`. Use them freely on 2-layer boards. Just do not sprinkle dozens under a tiny DIP if a short bottom hop will do.

Hotkeys worth remembering:

| Key | Action |
|-----|---|
| **X** | Route track |
| **V** | Place via (while routing) |
| **PgUp / PgDn** | Front / back layer (or use layer selector) |
| **E** | Edit (click a track/via) |
| **Delete** | Remove selected copper |
| **B** | Fill copper zones (after zones exist) |
| **Ctrl+B** | Rebuild all zones |

Exact keys can vary slightly by KiCad version. Check **Preferences -> Hotkeys** if one does not match.

## Ground (and power) pours

A **zone** is a filled copper area attached to a net.

### Add a bottom ground pour

1. Switch active layer to **B.Cu**.
2. **Add -> Copper Zone** (or toolbar zone tool).
3. Outline the board inside `Edge.Cuts` (click corners, double-click / finish to close).
4. In the dialog: set **Net** to `GND`, layer `B.Cu`, clearance and minimum width from your rules.
5. Press **B** to fill.

You should see solid (or hatched) copper on the bottom connected to every GND pad it can reach. Gaps appear around tracks and pads per clearance.

Optional:

- Light **F.Cu** GND pour in empty top areas (helps, but keep soldering pads clear).
- Separate **+5V** zone only if the board is simple and you understand splits. Many small boards just use wide traces for +5V instead.

### Keep pours healthy

- After moving tracks, press **B** again so fills update.
- Use **Inspect -> Continuity** / DRC before fab.
- Cart edge: keep finger pads and soldermask openings as the footprint defines them. Do not flood over gold-finger geometry carelessly.

## Suggested order for a board like the cart image

Your layout already has U25 (25LC1024), U50 (24C64), bypass caps, 0R bridges, and J16 fingers. A calm route order:

1. **Power first**  
   `+5V` from J16 to the 0R bridges / VCC pins with a **wider** track. `GND` stubs short to pads that will sit in the pour.
2. **SPI cluster** (J16 -> U25)  
   SS#, SCK, MOSI, MISO as a neat group on `F.Cu` if possible.
3. **I2C** (J16 -> U50)  
   SDA, SCL. Leave space for pull-ups if they live on the mobo (they do on Nano).
4. **Local bypass**  
   CD1/CD2 should hug U25/U50 VCC-GND with very short leads (already placed near the chips is good).
5. **Bottom pour GND**, then **B** to fill.
6. **Unresolved ratsnest**: use vias + short `B.Cu` hops, then refill zones.
7. **DRC** (Design Rules Checker). Fix clearance, unconnected items, courtyard overlaps.
8. Silkscreen tidy-up, then plot Gerbers / fab outputs.

Mounting holes: if the center hole is non-plated mechanical only, keep copper clearance. If it should tie to GND, use a plated hole or a pad on the GND net.

## Crossings and "no path on top"

| Situation | Typical fix |
|---|---|
| Two signals must cross | One stays on `F.Cu`, the other vias to `B.Cu` and back |
| Trace blocked by a pad row | Arc around, or via under/ beside and run on bottom |
| Power needs to cross a signal bundle | Power on bottom for a short span, or rearrange parts |
| Everything fights on a tiny board | Pour GND on bottom. Accept more vias. Widen outline slightly |

You do **not** need a 4-layer board for this cart class of design.

## Checks before you order

1. **Ratsnest empty** (or only intentional no-connects).
2. **DRC clean** for your rule set.
3. **3D viewer**: parts fit, DIP orientation (pin 1), cart edge direction.
4. Confirm fab accepts your min track/via/clearance.
5. Export Gerbers + drill per fab instructions (File -> Fabrication Outputs).

## Nano cart notes (context for the screenshot)

- Edge nets are few: GND, +5V, SPI, I2C. That is an easy 2-layer route.
- Fully THT DIPs: route on top where possible. Bottom pour helps heat and GND.
- `RD*` 0 ohm parts are for Quilter-style local +5V islands on denser boards. On a tiny cart they still just bridge as short links. Treat them as wire jumpers in copper if that matches your netlist intent.
- Do not confuse **edge pad count (8+8)** with **IC pin count**. Fingers are the connector. Chips sit inland.

## Short glossary

| Term | Meaning |
|---|---|
| Ratsnest | Straight-line "air wires" showing unrouted connections |
| Track / trace | Copper path you draw |
| Via | Plated hole joining layers |
| Zone / pour | Filled copper region on a net |
| DRC | Automatic rule check |
| THT | Through-hole (pads on both sides) |

## Further reading in this repo

- Nano cart / mobo hardware: [`nano/docs/hardware.md`](../nano/docs/hardware.md)
- Cart edge recipe: [`docs/cart.md`](cart.md)
- Full Retr01 passives / fab-ish notes: [`docs/passive_rf_etc.md`](passive_rf_etc.md)

KiCad menus move slightly between versions. If a command name differs, search the PCB Editor command palette / Preferences hotkeys for "Route", "Via", and "Copper Zone".

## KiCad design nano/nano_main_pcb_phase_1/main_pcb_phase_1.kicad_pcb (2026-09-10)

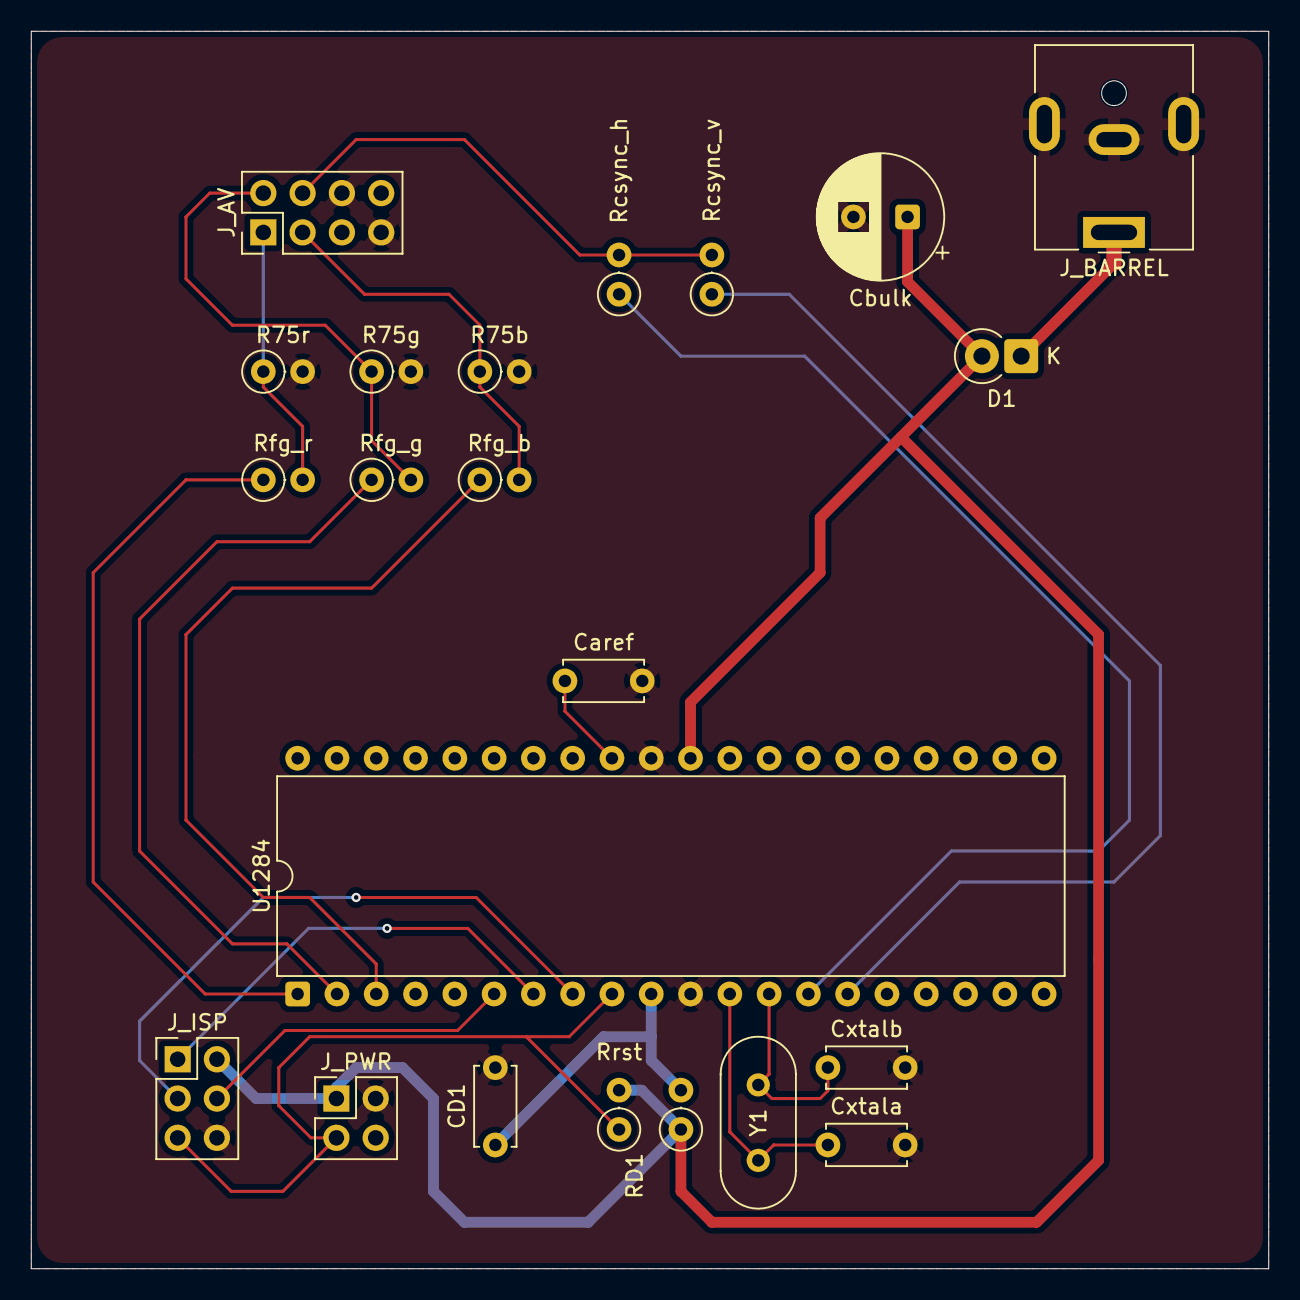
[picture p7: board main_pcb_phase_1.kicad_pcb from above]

Board: 2 copper layers, 80.0 x 80.0 mm, 22 parts (0 on the bottom side), 20 nets.

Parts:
CD1: 100nF; C_Disc_D5.0mm_W2.5mm_P5.00mm
Caref: 100nF; C_Disc_D5.0mm_W2.5mm_P5.00mm
Cbulk: 220uF; CP_Radial_D8.0mm_P3.50mm
Cxtala: 22pF; C_Disc_D5.0mm_W2.5mm_P5.00mm
Cxtalb: 22pF; C_Disc_D5.0mm_W2.5mm_P5.00mm
D1: SCHOTTKY; D_DO-41_SOD81_P2.54mm_Vertical_CathodeUp
J_AV: J_AV; PinHeader_2x04_P2.54mm_Vertical
J_BARREL: BARREL_5V; BarrelJack_CUI_PJ-063AH_Horizontal
J_ISP: J_ISP; PinHeader_2x03_P2.54mm_Vertical
J_PWR: J_PWR; PinHeader_2x02_P2.54mm_Vertical
R75b, R75g, R75r: 75R; R_Axial_DIN0207_L6.3mm_D2.5mm_P2.54mm_Vertical
RD1: 0R; R_Axial_DIN0207_L6.3mm_D2.5mm_P2.54mm_Vertical
Rcsync_h: 1k; R_Axial_DIN0207_L6.3mm_D2.5mm_P2.54mm_Vertical
Rcsync_v: 1k; R_Axial_DIN0207_L6.3mm_D2.5mm_P2.54mm_Vertical
Rfg_b: 470R; R_Axial_DIN0207_L6.3mm_D2.5mm_P2.54mm_Vertical
Rfg_g: 470R; R_Axial_DIN0207_L6.3mm_D2.5mm_P2.54mm_Vertical
Rfg_r: 470R; R_Axial_DIN0207_L6.3mm_D2.5mm_P2.54mm_Vertical
Rrst: 10k; R_Axial_DIN0207_L6.3mm_D2.5mm_P2.54mm_Vertical
U1284: ATmega1284P; DIP-40_W15.24mm
Y1: XTAL_20M; Crystal_HC49-U_Vertical

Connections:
+5V: Cbulk.1, D1.2, J_ISP.2, J_PWR.1, RD1.1, Rrst.2, U1284.30
+5V_U1284: CD1.1, RD1.2, U1284.10
AREF: Caref.1, U1284.32
B: J_AV.3, R75b.1, Rfg_b.2
CSYNC: J_AV.4, Rcsync_h.2, Rcsync_v.2
FG0: Rfg_r.1, U1284.1
FG1: Rfg_g.1, U1284.2
FG2: Rfg_b.1, U1284.3
G: J_AV.2, R75g.1, Rfg_g.2
GND: CD1.2, Caref.2, Cbulk.2, Cxtala.2, Cxtalb.2, J_AV.6, J_AV.7, J_BARREL.2, J_BARREL.MP, J_ISP.6, J_PWR.2, R75b.2, R75g.2, R75r.2, U1284.11, U1284.31
HSYNC: Rcsync_h.1, U1284.14
R: J_AV.1, R75r.1, Rfg_r.2
RESET#: J_ISP.5, J_PWR.3, Rrst.1, U1284.9
SPI_MISO: J_ISP.1, U1284.7
SPI_MOSI: J_ISP.4, U1284.6
SPI_SCK: J_ISP.3, U1284.8
VIN_RAW: D1.1, J_BARREL.1
VSYNC: Rcsync_v.1, U1284.15
XTAL1: Cxtalb.1, U1284.13, Y1.2
XTAL2: Cxtala.1, U1284.12, Y1.1

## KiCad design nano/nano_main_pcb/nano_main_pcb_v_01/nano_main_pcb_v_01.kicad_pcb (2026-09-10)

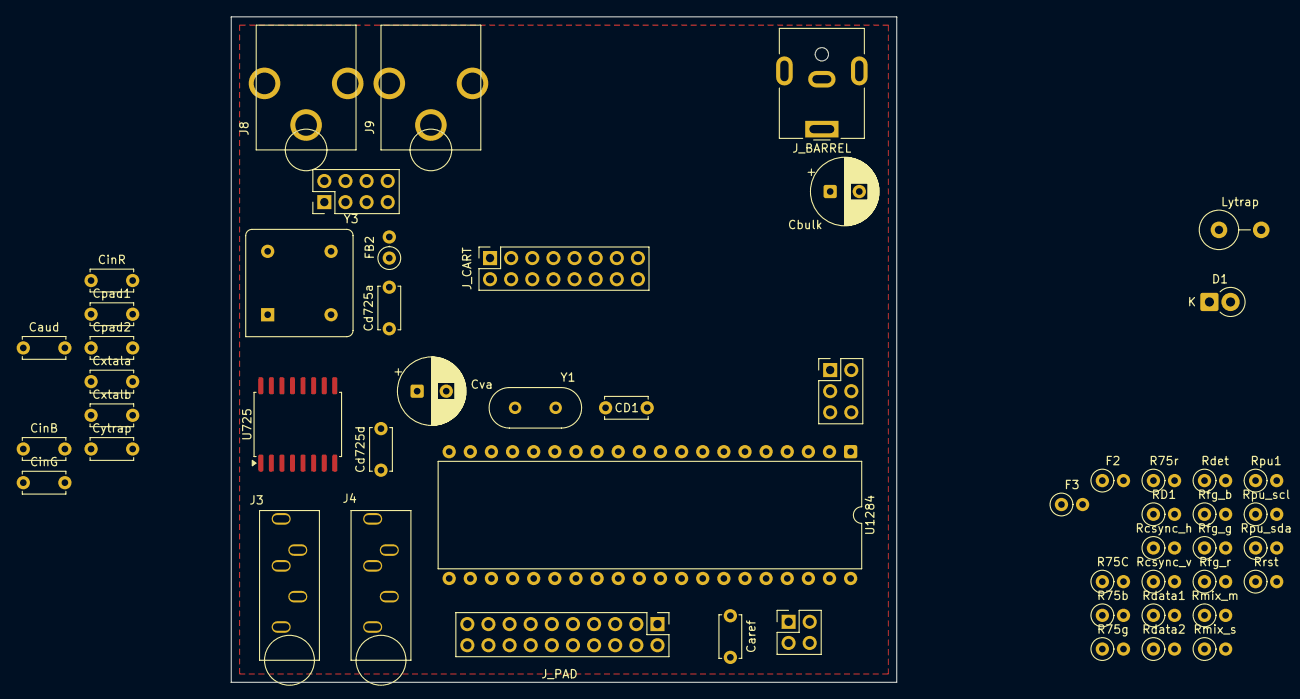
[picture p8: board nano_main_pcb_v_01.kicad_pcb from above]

Board: 2 copper layers, 80.0 x 80.0 mm, 53 parts (0 on the bottom side), 59 nets, no tracks yet.

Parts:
CD1: 100nF; C_Disc_D5.0mm_W2.5mm_P5.00mm
Caref: 100nF; C_Disc_D5.0mm_W2.5mm_P5.00mm
Caud: 10uF; C_Disc_D5.0mm_W2.5mm_P5.00mm
Cbulk: 220uF; CP_Radial_D8.0mm_P3.50mm
Cd725a, Cd725d: 100nF; C_Disc_D5.0mm_W2.5mm_P5.00mm
CinB: 100nF; C_Disc_D5.0mm_W2.5mm_P5.00mm
CinG: 100nF; C_Disc_D5.0mm_W2.5mm_P5.00mm
CinR: 100nF; C_Disc_D5.0mm_W2.5mm_P5.00mm
Cpad1, Cpad2: 100nF; C_Disc_D5.0mm_W2.5mm_P5.00mm
Cva: 10uF; CP_Radial_D8.0mm_P3.50mm
Cxtala: 22pF; C_Disc_D5.0mm_W2.5mm_P5.00mm
Cxtalb: 22pF; C_Disc_D5.0mm_W2.5mm_P5.00mm
Cytrap: 100nF; C_Disc_D5.0mm_W2.5mm_P5.00mm
D1: SCHOTTKY; D_DO-41_SOD81_P2.54mm_Vertical_CathodeUp
F2, F3: PPTC; R_Axial_DIN0207_L6.3mm_D2.5mm_P2.54mm_Vertical
FB2: FERRITE; R_Axial_DIN0207_L6.3mm_D2.5mm_P2.54mm_Vertical
J3: TRS_P1; Jack_3.5mm_Switchcraft_35RAPC2BVN4_Vertical
J4: TRS_P2; Jack_3.5mm_Switchcraft_35RAPC2BVN4_Vertical
J8: AUDIO_OUT; CUI_RCJ-01x_Vertical
J9: COMPOSITE; CUI_RCJ-01x_Vertical
J_AV: J_AV; PinHeader_2x04_P2.54mm_Vertical
J_BARREL: BARREL_5V; BarrelJack_CUI_PJ-063AH_Horizontal
J_CART: CART_SOCKET_16; PinSocket_2x08_P2.54mm_Vertical
J_ISP: J_ISP; PinHeader_2x03_P2.54mm_Vertical
J_PAD: J_PAD; PinHeader_2x10_P2.54mm_Vertical
J_PWR: J_PWR; PinHeader_2x02_P2.54mm_Vertical
Lytrap: L_YTRAP; L_Axial_L11.0mm_D4.5mm_P5.08mm_Vertical_Fastron_MECC
R75C, R75b, R75g, R75r: 75R; R_Axial_DIN0207_L6.3mm_D2.5mm_P2.54mm_Vertical
RD1: 0R; R_Axial_DIN0207_L6.3mm_D2.5mm_P2.54mm_Vertical
Rcsync_h: 1k; R_Axial_DIN0207_L6.3mm_D2.5mm_P2.54mm_Vertical
Rcsync_v: 1k; R_Axial_DIN0207_L6.3mm_D2.5mm_P2.54mm_Vertical
Rdata1, Rdata2: 47R; R_Axial_DIN0207_L6.3mm_D2.5mm_P2.54mm_Vertical
Rdet: 10k; R_Axial_DIN0207_L6.3mm_D2.5mm_P2.54mm_Vertical
Rfg_b: 470R; R_Axial_DIN0207_L6.3mm_D2.5mm_P2.54mm_Vertical
Rfg_g: 470R; R_Axial_DIN0207_L6.3mm_D2.5mm_P2.54mm_Vertical
Rfg_r: 470R; R_Axial_DIN0207_L6.3mm_D2.5mm_P2.54mm_Vertical
Rmix_m: 1k; R_Axial_DIN0207_L6.3mm_D2.5mm_P2.54mm_Vertical
Rmix_s: 1k; R_Axial_DIN0207_L6.3mm_D2.5mm_P2.54mm_Vertical
Rpu1: 4.7k; R_Axial_DIN0207_L6.3mm_D2.5mm_P2.54mm_Vertical
Rpu_scl: 4.7k; R_Axial_DIN0207_L6.3mm_D2.5mm_P2.54mm_Vertical
Rpu_sda: 4.7k; R_Axial_DIN0207_L6.3mm_D2.5mm_P2.54mm_Vertical
Rrst: 10k; R_Axial_DIN0207_L6.3mm_D2.5mm_P2.54mm_Vertical
U725: AD725; SOIC-16W_7.5x10.3mm_P1.27mm
U1284: ATmega1284P; DIP-40_W15.24mm
Y1: XTAL_20M; Crystal_HC49-U_Vertical
Y3: OSC_4FSC; Oscillator_DIP-8

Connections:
+5V: Cbulk.1, D1.2, F2.1, F3.1, FB2.1, J_CART.2, J_CART.10, J_ISP.2, J_PWR.1, RD1.1, Rdet.2, Rpu1.1, Rpu_scl.2, Rpu_sda.2, Rrst.2, U725.1, U725.5, U725.15, U1284.30, Y3.1, Y3.8
+5V_ANALOG: Cd725a.1, Cd725d.1, Cva.1, FB2.2, U725.4, U725.14
+5V_U1284: CD1.1, RD1.2, U1284.10
AD725_BIN: CinB.2, U725.8
AD725_GIN: CinG.2, U725.7
AD725_RIN: CinR.2, U725.6
AREF: Caref.1, U1284.32
AUD: Caud.2, J8.1, J_AV.5
AUD_MIX: Caud.1, Rmix_m.2, Rmix_s.2
B: CinB.1, J_AV.3, R75b.1, Rfg_b.2
CART_DET#: J_CART.16, Rdet.1, U1284.4
COMPOSITE_OUT: J9.1, R75C.2
COMP_RAW: R75C.1, U725.10
CSYNC: J_AV.4, Rcsync_h.2, Rcsync_v.2, U725.16
FG0: Rfg_r.1, U1284.1
FG1: Rfg_g.1, U1284.2
FG2: Rfg_b.1, U1284.3
FSC4: U725.3, Y3.5
G: CinG.1, J_AV.2, R75g.1, Rfg_g.2
GND: CD1.2, Caref.2, Cbulk.2, Cd725a.2, Cd725d.2, Cpad1.2, Cpad2.2, Cva.2, Cxtala.2, Cxtalb.2, Cytrap.2, J3.1, J4.1, J8.2, J9.2, J_BARREL.2, J_BARREL.MP, J_CART.1, J_CART.9, J_ISP.6, J_PAD.17, J_PAD.18, J_PWR.2, U725.2, U725.13, U1284.11, U1284.31, Y3.4
HSYNC: Rcsync_h.1, U1284.14
I2C_SCL: J_CART.8, Rpu_scl.1, U1284.22
I2C_SDA: J_CART.7, J_CART.15, Rpu_sda.1, U1284.23
P1_D0: J_PAD.1, U1284.40
P1_D1: J_PAD.3, U1284.39
P1_D2: J_PAD.5, U1284.38
P1_D3: J_PAD.7, U1284.37
P1_D4: J_PAD.9, U1284.36
P1_D5: J_PAD.11, U1284.35
P1_D6: J_PAD.13, U1284.34
P1_D7: J_PAD.15, U1284.33
P2_D0: J_PAD.2, U1284.24
P2_D1: J_PAD.4, U1284.25
P2_D2: J_PAD.6, U1284.26
P2_D3: J_PAD.8, U1284.27
P2_D4: J_PAD.10, U1284.28
P2_D5: J_PAD.12, U1284.29
P2_D6: J_PAD.14, U1284.20
P2_D7: J_PAD.16, U1284.21
PAD_DATA: Rdata1.1, Rdata2.1, Rpu1.2, U1284.16
PAD_DATA_P1: J3.2, Rdata1.2
PAD_DATA_P2: J4.2, Rdata2.2
PAD_VCC_P1: Cpad1.1, F2.2, J3.4
PAD_VCC_P2: Cpad2.1, F3.2, J4.4
PWM_MUSIC: Rmix_m.1, U1284.19
PWM_SFX: Rmix_s.1, U1284.18
R: CinR.1, J_AV.1, R75r.1, Rfg_r.2
RESET#: J_ISP.5, J_PWR.3, Rrst.1, U1284.9
SPI_MISO: J_CART.6, J_CART.14, J_ISP.1, U1284.7
SPI_MOSI: J_CART.5, J_CART.13, J_ISP.4, U1284.6
SPI_SCK: J_CART.4, J_CART.12, J_ISP.3, U1284.8
SPI_SS#: J_CART.3, J_CART.11, U1284.5
VGND: J_AV.7, R75b.2, R75g.2, R75r.2
VIN_RAW: D1.1, J_BARREL.1
VSYNC: Rcsync_v.1, U1284.15
XTAL1: Cxtalb.1, U1284.13, Y1.2
XTAL2: Cxtala.1, U1284.12, Y1.1
YTRAP: Lytrap.1, U725.12
YTRAP_MID: Cytrap.1, Lytrap.2

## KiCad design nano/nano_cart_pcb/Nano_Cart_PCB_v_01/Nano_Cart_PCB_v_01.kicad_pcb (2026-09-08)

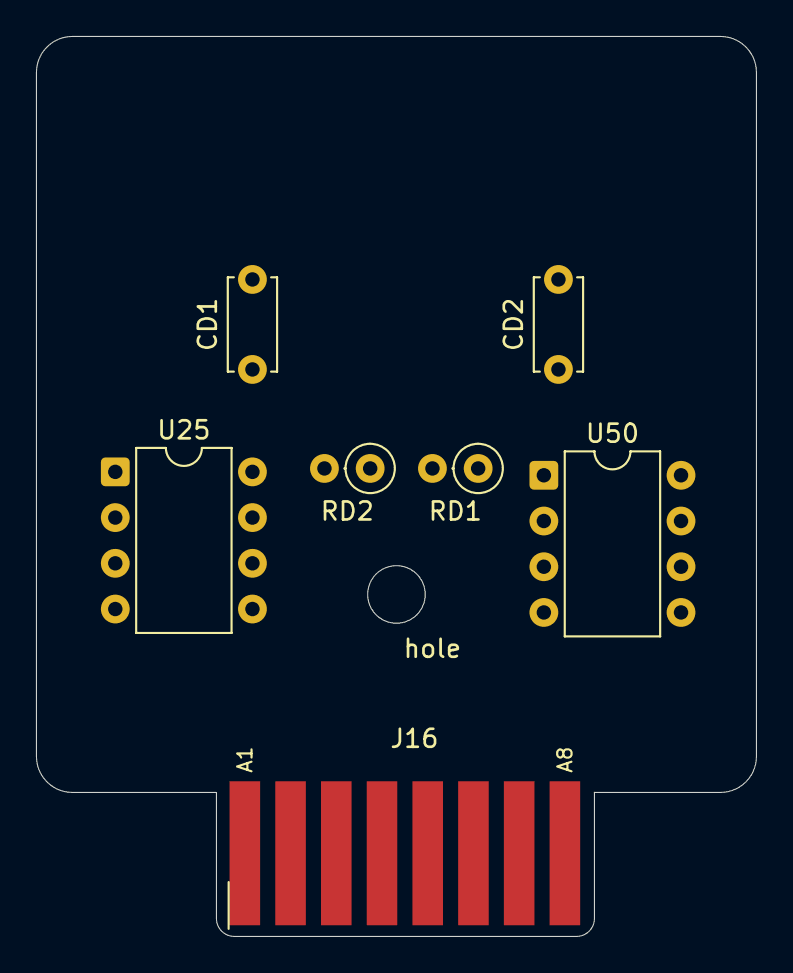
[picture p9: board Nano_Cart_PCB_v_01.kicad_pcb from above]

Board: 2 copper layers, 40.0 x 50.0 mm, 8 parts (0 on the bottom side), 10 nets, no tracks yet.

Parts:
CD1, CD2: 100nF; C_Disc_D5.0mm_W2.5mm_P5.00mm
J16: CART_EDGE_16; Cart_Edge_2x8_P2.54mm
RD1, RD2: 0R; R_Axial_DIN0207_L6.3mm_D2.5mm_P2.54mm_Vertical
U25: 25LC1024; DIP-8_W7.62mm
U50: 24C64; DIP-8_W7.62mm
hole: MountingHole_3.2mm_M3

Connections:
+5V: J16.2, J16.10, RD1.1, RD2.1, U25.3, U25.7
+5V_U25: CD1.1, RD1.2, U25.8
+5V_U50: CD2.1, RD2.2, U50.8
GND: CD1.2, CD2.2, J16.1, J16.9, U25.4, U50.1, U50.2, U50.3, U50.4, U50.7
I2C_SCL: J16.8, U50.6
I2C_SDA: J16.7, J16.15, U50.5
SPI_MISO: J16.6, J16.14, U25.2
SPI_MOSI: J16.5, J16.13, U25.5
SPI_SCK: J16.4, J16.12, U25.6
SPI_SS#: J16.3, J16.11, U25.1

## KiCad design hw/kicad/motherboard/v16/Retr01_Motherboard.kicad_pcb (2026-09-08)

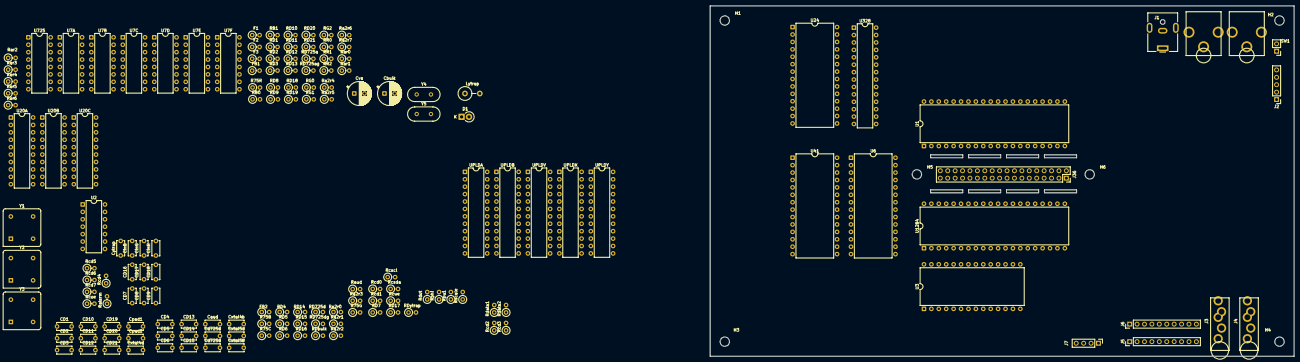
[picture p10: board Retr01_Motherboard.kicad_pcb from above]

Board: 4 copper layers, 200.0 x 120.0 mm, 162 parts (0 on the bottom side), 214 nets, no tracks yet.

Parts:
CD1, CD2, CD3, CD4, CD5, CD6, CD7, CD8, CD9, CD10, CD11, CD12, CD13, CD14, CD15, CD16, CD17, CD18, CD19, CD20, CD21: 100nF; C_Disc_D5.0mm_W2.5mm_P5.00mm
Caud: 10uF; C_Disc_D5.0mm_W2.5mm_P5.00mm
Cbulk: 220uF; CP_Radial_D8.0mm_P3.50mm
Cd725a, Cd725d: 100nF; C_Disc_D5.0mm_W2.5mm_P5.00mm
CinB: 100nF; C_Disc_D5.0mm_W2.5mm_P5.00mm
CinG: 100nF; C_Disc_D5.0mm_W2.5mm_P5.00mm
CinR: 100nF; C_Disc_D5.0mm_W2.5mm_P5.00mm
Cpad1, Cpad2: 100nF; C_Disc_D5.0mm_W2.5mm_P5.00mm
Cva: 10uF; CP_Radial_D8.0mm_P3.50mm
Cxtal4a, Cxtal4b, Cxtal5a, Cxtal5b: 22pF; C_Disc_D5.0mm_W2.5mm_P5.00mm
Cytrap: 100nF; C_Disc_D5.0mm_W2.5mm_P5.00mm
D1: SCHOTTKY; D_DO-41_SOD81_P2.54mm_Vertical_CathodeUp
F1, F2, F3: PPTC; R_Axial_DIN0207_L6.3mm_D2.5mm_P2.54mm_Vertical
FB1, FB2: FERRITE; R_Axial_DIN0207_L6.3mm_D2.5mm_P2.54mm_Vertical
H1, H2, H3, H4, H5, H6: MountingHole_3.2mm_M3
J1: BARREL_5V; BarrelJack_CUI_PJ-063AH_Horizontal
J2: RGBS_HDR; PinHeader_1x05_P2.54mm_Vertical
J3: TRS_P1; Jack_3.5mm_Switchcraft_35RAPC2BVN4_Vertical
J4: TRS_P2; Jack_3.5mm_Switchcraft_35RAPC2BVN4_Vertical
J5: ARCADE_P1; PinHeader_1x10_P2.54mm_Vertical
J6: ARCADE_P2; PinHeader_1x10_P2.54mm_Vertical
J7: CAB_PWR_RST; PinHeader_1x04_P2.54mm_Vertical
J8: AUDIO_OUT; CUI_RCJ-01x_Vertical
J9: COMPOSITE; CUI_RCJ-01x_Vertical
J36: CART_EDGE_36; PinSocket_2x18_P2.54mm_Vertical
Lytrap: L_YTRAP; L_Axial_L11.0mm_D4.5mm_P5.08mm_Vertical_Fastron_MECC
R75B, R75C, R75G, R75R: 75R; R_Axial_DIN0207_L6.3mm_D2.5mm_P2.54mm_Vertical
RB0: 2k; R_Axial_DIN0207_L6.3mm_D2.5mm_P2.54mm_Vertical
RB1: 1k; R_Axial_DIN0207_L6.3mm_D2.5mm_P2.54mm_Vertical
RD1, RD2, RD3, RD4, RD5, RD6, RD7, RD8, RD9, RD10, RD11, RD12, RD13, RD14, RD15, RD16, RD17, RD18, RD19, RD20, RD21: 0; R_Axial_DIN0207_L6.3mm_D2.5mm_P2.54mm_Vertical
RD725a, RD725ag, RD725d, RD725dg: 0R; R_Axial_DIN0207_L6.3mm_D2.5mm_P2.54mm_Vertical
RDbulk: 0R; R_Axial_DIN0207_L6.3mm_D2.5mm_P2.54mm_Vertical
RDytrap: 0R; R_Axial_DIN0207_L6.3mm_D2.5mm_P2.54mm_Vertical
RG0: 4k; R_Axial_DIN0207_L6.3mm_D2.5mm_P2.54mm_Vertical
RG1: 2k; R_Axial_DIN0207_L6.3mm_D2.5mm_P2.54mm_Vertical
RG2: 1k; R_Axial_DIN0207_L6.3mm_D2.5mm_P2.54mm_Vertical
RR0: 4k; R_Axial_DIN0207_L6.3mm_D2.5mm_P2.54mm_Vertical
RR1: 2k; R_Axial_DIN0207_L6.3mm_D2.5mm_P2.54mm_Vertical
RR2: 1k; R_Axial_DIN0207_L6.3mm_D2.5mm_P2.54mm_Vertical
Ra2r0, Ra2r1, Ra2r2, Ra2r3, Ra2r4, Ra2r5, Ra2r6, Ra2r7: 20k; R_Axial_DIN0207_L6.3mm_D2.5mm_P2.54mm_Vertical
Rar0, Rar1, Rar2, Rar3, Rar4, Rar5, Rar6: 10k; R_Axial_DIN0207_L6.3mm_D2.5mm_P2.54mm_Vertical
Raterm: 20k; R_Axial_DIN0207_L6.3mm_D2.5mm_P2.54mm_Vertical
Raud: 1k; R_Axial_DIN0207_L6.3mm_D2.5mm_P2.54mm_Vertical
Rcd0, Rcd1, Rcd2, Rcd3, Rcd4, Rcd5, Rcd6, Rcd7: 33R; R_Axial_DIN0207_L6.3mm_D2.5mm_P2.54mm_Vertical
Rcoe: 33R; R_Axial_DIN0207_L6.3mm_D2.5mm_P2.54mm_Vertical
Rcscl: 33R; R_Axial_DIN0207_L6.3mm_D2.5mm_P2.54mm_Vertical
Rcsda: 33R; R_Axial_DIN0207_L6.3mm_D2.5mm_P2.54mm_Vertical
Rcwe: 33R; R_Axial_DIN0207_L6.3mm_D2.5mm_P2.54mm_Vertical
Rdata1, Rdata2: 47R; R_Axial_DIN0207_L6.3mm_D2.5mm_P2.54mm_Vertical
Rdot: 33R; R_Axial_DIN0207_L6.3mm_D2.5mm_P2.54mm_Vertical
Rphi: 33R; R_Axial_DIN0207_L6.3mm_D2.5mm_P2.54mm_Vertical
Rpu1: 4.7k; R_Axial_DIN0207_L6.3mm_D2.5mm_P2.54mm_Vertical
Rscale: 10k; R_Axial_DIN0207_L6.3mm_D2.5mm_P2.54mm_Vertical
SW1: SCALE_SW; PinHeader_1x02_P2.54mm_Vertical
U1: W65C02S; DIP-40_W15.24mm
U2: SN74HC14; DIP-14_W7.62mm
U3, U6, U41: AS6C62256; DIP-28_W15.24mm
U7A, U7B, U7C, U7D, U7E, U7F: SN74HC157; DIP-16_W7.62mm
U20A, U20B, U20C: SN74HC245; DIP-20_W7.62mm
U24: AT27C256R; DIP-28_W15.24mm
U328: ATmega328P; DIP-28_W7.62mm
U725: AD725; DIP-16_W7.62mm
U1284: ATmega1284P; DIP-40_W15.24mm
UPLDA: ATF22V10; DIP-24_W7.62mm
UPLDB: ATF22V10; DIP-24_W7.62mm
UPLDV: ATF22V10; DIP-24_W7.62mm
UPLDX: ATF22V10; DIP-24_W7.62mm
UPLDY: ATF22V10; DIP-24_W7.62mm
Y1: OSC8M; Oscillator_DIP-8
Y2: OSC_DOT; Oscillator_DIP-8
Y3: OSC_4FSC; Oscillator_DIP-8
Y4: XTAL_20M; Crystal_HC49-U_Vertical
Y5: XTAL_16M; Crystal_HC49-U_Vertical

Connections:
+5V: F2.1, F3.1, FB2.1, J7.1, J36.2, J36.20, RD1.2, RD2.2, RD3.2, RD4.2, RD5.2, RD6.2, RD8.2, RD9.2, RD10.2, RD11.2, RD12.2, RD13.2, RD14.2, RD15.2, RD16.2, RD17.2, RD18.2, RD19.2, RD20.2, RD21.2, RDbulk.2, Rpu1.1, SW1.2, U2.14, U725.1, U725.5, U725.15, Y1.1, Y1.8, Y2.1, Y2.8, Y3.1, Y3.8
+5V_ANALOG: Cva.1, FB2.2, RD7.2, RD725a.2, RD725d.2
+5V_BULK: Cbulk.1, FB1.2, RDbulk.1
+5V_U1: CD1.1, RD1.1, U1.8
+5V_U3: CD2.1, RD2.1, U3.28
+5V_U6: CD5.1, RD5.1, U6.28
+5V_U7A: CD13.1, RD13.1, U7A.16
+5V_U7B: CD14.1, RD14.1, U7B.16
+5V_U7C: CD15.1, RD15.1, U7C.16
+5V_U7D: CD16.1, RD16.1, U7D.16
+5V_U7E: CD17.1, RD17.1, U7E.16
+5V_U7F: CD18.1, RD18.1, U7F.16
+5V_U20A: CD19.1, RD19.1, U20A.20
+5V_U20B: CD20.1, RD20.1, U20B.20
+5V_U20C: CD21.1, RD21.1, U20C.20
+5V_U24: CD7.1, RD7.1, U24.28
+5V_U41: CD6.1, RD6.1, U41.28
+5V_U328: CD4.1, RD4.1, U328.7
+5V_U725_APOS: Cd725a.1, RD725a.1, U725.4
+5V_U725_DPOS: Cd725d.1, RD725d.1, U725.14
+5V_U1284: CD3.1, RD3.1, U1284.10
+5V_UPLDA: CD8.1, RD8.1, UPLDA.24
+5V_UPLDB: CD9.1, RD9.1, UPLDB.24
+5V_UPLDV: CD12.1, RD12.1, UPLDV.24
+5V_UPLDX: CD10.1, RD10.1, UPLDX.24
+5V_UPLDY: CD11.1, RD11.1, UPLDY.24
AD725_BIN: CinB.2, U725.8
AD725_GIN: CinG.2, U725.7
AD725_RIN: CinR.2, U725.6
ASUM0: Ra2r0.2, Rar0.1, Raterm.1
ASUM1: Ra2r1.2, Rar0.2, Rar1.1
ASUM2: Ra2r2.2, Rar1.2, Rar2.1
ASUM3: Ra2r3.2, Rar2.2, Rar3.1
ASUM4: Ra2r4.2, Rar3.2, Rar4.1
ASUM5: Ra2r5.2, Rar4.2, Rar5.1
ASUM6: Ra2r6.2, Rar5.2, Rar6.1
AUD0: Ra2r0.1, U328.14
AUD1: Ra2r1.1, U328.15
AUD2: Ra2r2.1, U328.16
AUD3: Ra2r3.1, U328.17
AUD4: Ra2r4.1, U328.18
AUD5: Ra2r5.1, U328.19
AUD6: Ra2r6.1, U328.23
AUD7: Ra2r7.1, U328.24
AUDIO_OUT: Caud.2, J8.1
AUDIO_SUM: Caud.1, Ra2r7.2, Rar6.2, Raud.1
BEAM_LB_A5: U7D.6, U7E.6, U7F.6, UPLDX.16, UPLDY.3
BEAM_Y0: U7D.3, U7E.3, U7F.3, UPLDX.15, UPLDY.2
BEAM_Y2: U7D.10, U7E.10, U7F.10, UPLDX.17, UPLDY.4
BEAM_Y3: U7D.13, U7E.13, U7F.13, UPLDX.18, UPLDY.5
BEAM_Y4: UPLDX.19, UPLDY.6
BEAM_Y5: UPLDX.20, UPLDY.7
BEAM_Y6: UPLDX.21, UPLDY.8
BEAM_Y7: UPLDX.22, UPLDY.9
CART_A0: J36.4, U1.9, U3.10, UPLDA.2
CART_A1: J36.5, U1.10, U3.9, UPLDA.3
CART_A2: J36.6, U1.11, U3.8, UPLDA.4
CART_A7: J36.11, U1.16, U3.3, UPLDA.9
CART_A8: J36.12, U1.17, U3.25
CART_A9: J36.13, U1.18, U3.24
CART_A10: J36.14, U1.19, U3.21
CART_A14: J36.31, UPLDV.15
CART_A15: J36.32, UPLDV.16
CART_A16: J36.33, UPLDV.17
CART_A17: J36.34, UPLDV.18
CART_A18: J36.35, UPLDV.19
CART_D0: J36.22, Rcd0.2
CART_D0_MCU: Rcd0.1, U20C.18
CART_D1: J36.23, Rcd1.2
CART_D1_MCU: Rcd1.1, U20C.17
CART_D2: J36.24, Rcd2.2
CART_D2_MCU: Rcd2.1, U20C.16
CART_D3: J36.25, Rcd3.2
CART_D3_MCU: Rcd3.1, U20C.15
CART_D4: J36.26, Rcd4.2
CART_D4_MCU: Rcd4.1, U20C.14
CART_D5: J36.27, Rcd5.2
CART_D5_MCU: Rcd5.1, U20C.13
CART_D6: J36.28, Rcd6.2
CART_D6_MCU: Rcd6.1, U20C.12
CART_D7: J36.29, Rcd7.2
CART_D7_MCU: Rcd7.1, U20C.11
CART_OE_MCU: Rcoe.1, UPLDB.20
CART_OE_N: J36.30, Rcoe.2
CART_WE_MCU: Rcwe.1, UPLDB.21
CART_WE_N: J36.36, Rcwe.2
COMPOSITE_OUT: J9.1, R75C.2
COMP_RAW: R75C.1, U725.10
CPU_A3: J36.7, U1.12, U3.7, UPLDA.5
CPU_A4: J36.8, U1.13, U3.6, UPLDA.6
CPU_A5: J36.9, U1.14, U3.5, UPLDA.7
CPU_A11: J36.15, U1.20, U3.23
CPU_A12: J36.16, U1.22, U3.2
CPU_A13: J36.17, U1.23, U3.26
CPU_A14: U1.24, U3.1
CPU_A_LO6: J36.10, U1.15, U3.4, UPLDA.8
CPU_BE: U1.36, UPLDA.10
CPU_D3: U1.30, U3.15, U6.15, U7A.13, U7A.14, U20A.5, U20A.15, U20C.5, U328.5, U1284.27, UPLDB.5, UPLDV.11, UPLDX.5, UPLDY.17
CPU_D5: U1.28, U3.17, U6.17, U7B.5, U7B.6, U20A.7, U20A.13, U20C.7, U328.11, U1284.29, UPLDB.7, UPLDX.7, UPLDY.19
CPU_D6: U1.27, U3.18, U6.18, U7B.10, U7B.11, U20A.8, U20A.12, U20C.8, U328.12, U1284.20, UPLDB.8, UPLDX.8, UPLDY.20
CPU_RWB: U1.34, UPLDA.11
CPU_VA0: U1.33, U3.11, U6.11, U7A.2, U7A.3, U20A.2, U20A.18, U20C.2, U328.2, U1284.24, UPLDB.2, UPLDV.8, UPLDX.2, UPLDY.14
CPU_VA2: U1.31, U3.13, U6.13, U7A.10, U7A.11, U20A.4, U20A.16, U20C.4, U328.4, U1284.26, UPLDB.4, UPLDV.10, UPLDX.4, UPLDY.16
CPU_VA4: U1.29, U3.16, U6.16, U7B.2, U7B.3, U20A.6, U20A.14, U20C.6, U328.6, U1284.28, UPLDB.6, UPLDV.21, UPLDX.6, UPLDY.18
CPU_VA10: U7C.10, U7C.11, UPLDB.13
CPU_VA11: U7C.13, U7C.14, U20A.1, UPLDB.14
CSYNC: J2.4, U725.16, UPLDV.14
DIR_CART245: U20C.1, UPLDB.18
DIR_VID245: U6.26, U20B.1, UPLDB.16
DOT_CLK: Rdot.2, UPLDX.1
DOT_SRC: Rdot.1, Y2.5
FSC4: U725.3, Y3.5
GND: CD1.2, CD2.2, CD3.2, CD4.2, CD5.2, CD6.2, CD7.2, CD8.2, CD9.2, CD10.2, CD11.2, CD12.2, CD13.2, CD14.2, CD15.2, CD16.2, CD17.2, CD18.2, CD19.2, CD20.2, CD21.2, Cbulk.2, Cpad1.2, Cpad2.2, Cva.2, Cxtal4a.2, Cxtal4b.2, Cxtal5a.2, Cxtal5b.2, J1.2, J1.MP, J2.5, J3.1, J4.1, J5.9, J5.10, J6.9, J6.10, J7.2, J7.4, J8.2, J9.2, J36.1, J36.18, J36.19, R75B.2, R75G.2, R75R.2, RD725ag.2, RD725dg.2, RDytrap.2, Raterm.2, Rscale.2, U1.21, U3.14, U6.14, U7A.8, U7B.8, U7C.8, U7D.8, U7E.8, U7F.8, U20A.10, U20B.10, U20C.10, U24.14, U41.14, U328.8, U1284.11, UPLDA.12, UPLDB.12, UPLDV.12, UPLDX.12, UPLDY.12, Y1.4, Y2.4, Y3.4
GND_U725_AGND: Cd725a.2, RD725ag.1, U725.2
GND_U725_DGND: Cd725d.2, RD725dg.1, U725.13
I2C_SCL: J36.21, Rcscl.2
I2C_SCL_MCU: Rcscl.1, U1284.22
I2C_SDA: J36.3, Rcsda.2
I2C_SDA_MCU: Rcsda.1, U1284.23
IRQ_N: U1.4, UPLDY.22
LB_A0: U7D.4, U41.10
LB_A1: U7D.7, U41.9
LB_A2: U7D.9, U41.8
LB_A3: U7D.12, U41.7
LB_A4: U7E.4, U41.6
LB_A5: U7E.7, U41.5
LB_A6: U7E.9, U41.4
LB_A7: U7E.12, U41.3
LB_A8: U7F.4, U41.25
LB_A9: U7F.7, U41.24
LB_A10: U7F.9, U41.21
LB_A11: U7F.12, U41.23
LB_MUX_AB: U7D.1, U7E.1, U7F.1, U1284.17
LB_MUX_G_N: U7D.15, U7E.15, U7F.15
MCU_LB_A2: J6.3, U7D.11, U7F.11, U1284.3
MCU_LB_A3: J6.4, U7D.14, U7F.14, U1284.4
MCU_LB_A4: J6.5, U7E.2, U41.2, U1284.5
MCU_LB_A6: J6.7, U7E.11, U41.1, U1284.7
MCU_LB_A7: J6.8, U7E.14, U1284.8
MUX_G_N: U7A.15, U7B.15, U7C.15
NMI_N: U1.6, UPLDX.14
OE_CART245: U20C.19, UPLDB.19
P1_COIN: J5.7, U1284.34
P1_DOWN: J5.3, U1284.38
P1_LEFT: J5.2, U1284.39
P1_RIGHT: J5.1, U1284.40
P1_START: J5.8, U1284.33
P1_UP: J5.4, U1284.37
P1_X: J5.5, U1284.36
P1_Y: J5.6, U1284.35
P2_LEFT: J6.2, U7D.5, U7F.5, U1284.2
P2_RIGHT: J6.1, U7D.2, U7F.2, U1284.1
P2_Y: J6.6, U7E.5, U41.26, U1284.6
PAD_DATA: Rdata1.1, Rdata2.1, Rpu1.2, U1284.16
PAD_DATA_P1: J3.2, Rdata1.2
PAD_DATA_P2: J4.2, Rdata2.2
PAD_VCC_P1: Cpad1.1, F2.2, J3.4
PAD_VCC_P2: Cpad2.1, F3.2, J4.4
PHI2_BUF: Rphi.2, U1.37, U2.1, U2.2, U7A.1, U7B.1, U7C.1
PHI2_SRC: Rphi.1, Y1.5
PPU_VA1: U1.32, U3.12, U6.12, U7A.5, U7A.6, U20A.3, U20A.17, U20C.3, U328.3, U1284.25, UPLDB.3, UPLDV.9, UPLDX.3, UPLDY.15
PPU_VA7: U1.26, U3.19, U6.19, U7B.13, U7B.14, U20A.9, U20A.11, U20C.9, U328.13, U1284.21, UPLDB.9, UPLDX.9, UPLDY.21
PPU_VA8: U7C.2, U7C.3, UPLDB.10
PPU_VA9: U7C.5, U7C.6, UPLDB.11
PROM_A0: U24.10, UPLDV.2
PROM_A1: U24.9, UPLDV.3
PROM_A2: U24.8, UPLDV.4
PROM_A3: U24.7, UPLDV.5
PROM_A4: U24.6, UPLDV.6
PROM_A5: U24.5, UPLDV.7
PROM_D0: RB0.1, U24.11
PROM_D1: RB1.1, U24.12
PROM_D2: RG0.1, U24.13
PROM_D3: RG1.1, U24.15
PROM_D4: RG2.1, U24.16
PROM_D5: RR0.1, U24.17
PROM_D6: RR1.1, U24.18
PROM_D7: RR2.1, U24.19
RESET_N: J7.3, U1.40, U2.3, UPLDX.13
SCALE_1X: Rscale.1, SW1.1, UPLDV.13
SEL_FE02: U1284.19, UPLDA.15, UPLDB.23
SEL_FE03: UPLDA.16, UPLDX.11
SEL_FE04: UPLDA.17, UPLDY.23
SEL_FE05: U1284.14, UPLDA.18, UPLDA.19
SEL_FE06: U1284.18, UPLDA.14
SEL_FE10: UPLDA.23, UPLDB.22
SEL_FE92: U1284.15, UPLDA.20, UPLDA.21, UPLDA.22, UPLDV.20
VIDEO_B: CinB.1, J2.3, R75B.1, RB0.2, RB1.2
VIDEO_G: CinG.1, J2.2, R75G.1, RG0.2, RG1.2, RG2.2
VIDEO_R: CinR.1, J2.1, R75R.1, RR0.2, RR1.2, RR2.2
VIN_FUSED: F1.2, FB1.1
VIN_PROT: D1.2, F1.1
VIN_RAW: D1.1, J1.1
VRAM_A0: U6.10, U7A.4
VRAM_A1: U6.9, U7A.7
VRAM_A2: U6.8, U7A.9
VRAM_A3: U6.7, U7A.12
VRAM_A4: U6.6, U7B.4
VRAM_A5: U6.5, U7B.7
VRAM_A6: U6.4, U7B.9
VRAM_A7: U6.3, U7B.12
VRAM_A8: U6.25, U7C.4
VRAM_A9: U6.24, U7C.7
VRAM_A10: U6.21, U7C.9
VRAM_A11: U6.23, U7C.12
VRAM_A12: U6.2, U20A.19, UPLDB.15
VRAM_A14: U6.1, U20B.19, UPLDB.17
XTAL328: Cxtal5a.1, U328.9, Y5.1
XTAL328b: Cxtal5b.1, U328.10, Y5.2
XTAL1284: Cxtal4a.1, U1284.13, Y4.1
XTAL1284b: Cxtal4b.1, U1284.12, Y4.2
YTRAP: Lytrap.1, U725.12
YTRAP_MID: Cytrap.1, Lytrap.2
YTRAP_RET: Cytrap.2, RDytrap.1

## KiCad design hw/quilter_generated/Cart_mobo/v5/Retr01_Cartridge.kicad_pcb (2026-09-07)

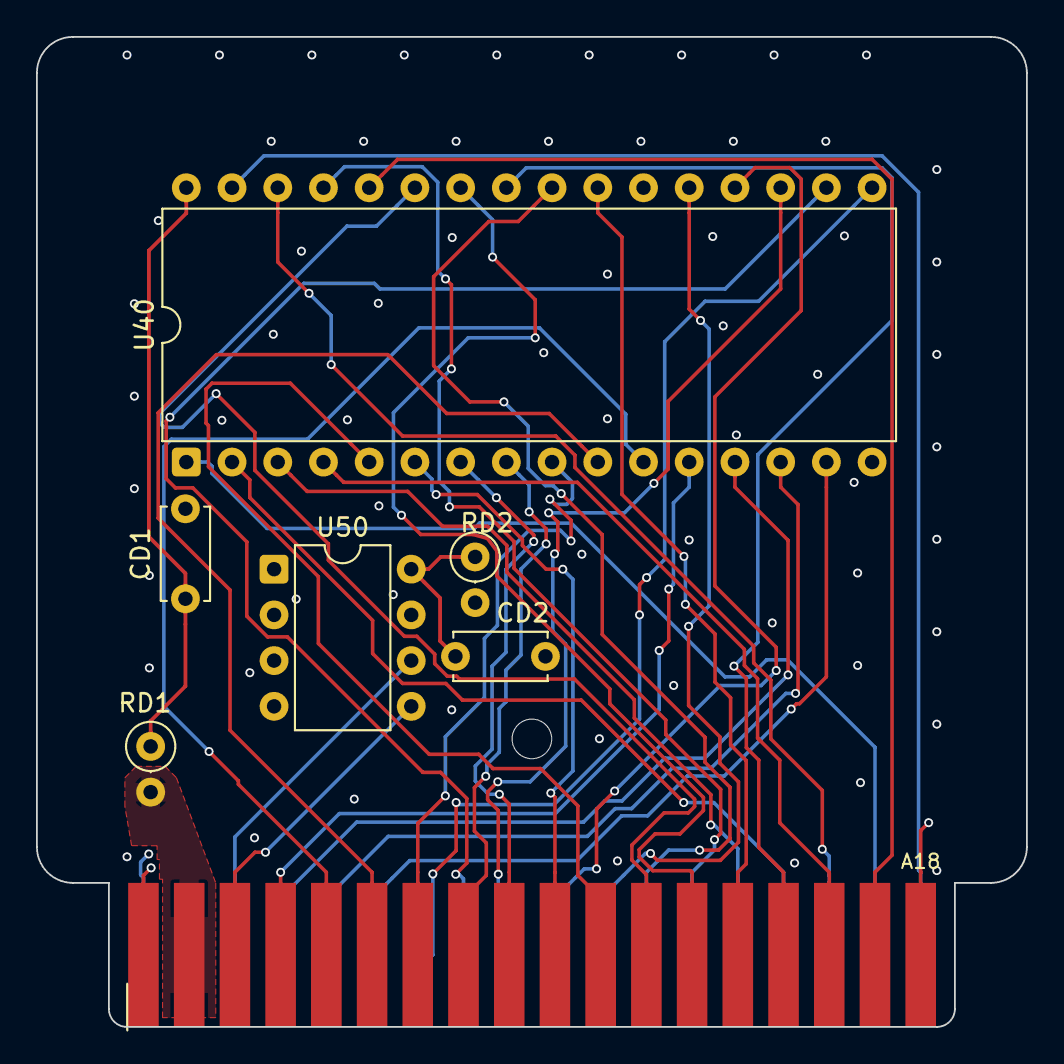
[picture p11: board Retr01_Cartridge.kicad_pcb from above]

Board: 4 copper layers, 55.0 x 55.0 mm, 8 parts (0 on the bottom side), 35 nets.

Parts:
CD1, CD2: 100nF; C_Disc_D5.0mm_W2.5mm_P5.00mm
J36: CART_EDGE_36; Cart_Edge_2x18_P2.54mm
RD1, RD2: 0; R_Axial_DIN0207_L6.3mm_D2.5mm_P2.54mm_Vertical
Screw: MountingHole_2.2mm_M2
U40: SST39SF040; DIP-32_W15.24mm
U50: 24C64; DIP-8_W7.62mm

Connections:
+5V: J36.2, J36.20, RD1.2, RD2.2
+5V_U40: CD1.1, RD1.1, U40.32
+5V_U50: CD2.1, RD2.1, U50.8
CART_A0: J36.4, U40.12
CART_A1: J36.5, U40.11
CART_A2: J36.6, U40.10
CART_A3: J36.7, U40.9
CART_A4: J36.8, U40.8
CART_A5: J36.9, U40.7
CART_A6: J36.10, U40.6
CART_A7: J36.11, U40.5
CART_A8: J36.12, U40.27
CART_A9: J36.13, U40.26
CART_A10: J36.14, U40.23
CART_A11: J36.15, U40.25
CART_A12: J36.16, U40.4
CART_A13: J36.17, U40.28
CART_A14: J36.31, U40.29
CART_A15: J36.32, U40.3
CART_A16: J36.33, U40.2
CART_A17: J36.34, U40.30
CART_A18: J36.35, U40.1
CART_D0: J36.22, U40.13
CART_D1: J36.23, U40.14
CART_D2: J36.24, U40.15
CART_D3: J36.25, U40.17
CART_D4: J36.26, U40.18
CART_D5: J36.27, U40.19
CART_D6: J36.28, U40.20
CART_D7: J36.29, U40.21
CART_OE_N: J36.30, U40.24
CART_WE_N: J36.36, U40.31
GND: CD1.2, CD2.2, J36.1, J36.18, J36.19, U40.16, U40.22, U50.1, U50.2, U50.3, U50.4, U50.7
I2C_SCL: J36.21, U50.6
I2C_SDA: J36.3, U50.5

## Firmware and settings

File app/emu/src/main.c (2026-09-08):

#include "retr01_emu/machine.h"
#include "retr01_emu/play.h"
#include "retr01_emu/video.h"
#include "r01_bgm_host.h"
#include "r01_custom_logic_scan.h"
#include "r01_pad_keys.h"

#include <SDL.h>

#include <stdio.h>
#include <stdlib.h>
#include <string.h>
#include <sys/stat.h>

#ifdef R01_DEFAULT_CART
#define R01E_DEFAULT_CART R01_DEFAULT_CART
#endif

#ifndef R01E_DEFAULT_CART
#define R01E_DEFAULT_CART "../../output/test.retr01"
#endif

static int path_is_file(const char *path) {
    struct stat st;
    return path && path[0] && stat(path, &st) == 0 && S_ISREG(st.st_mode);
}

/* output/test.retr01 -> output */
static void cart_output_dir(const char *cart_path, char *out, size_t out_cap) {
    const char *slash;
    size_t n;
    if (!out || out_cap < 2) {
        return;
    }
    out[0] = '\0';
    if (!cart_path || !cart_path[0]) {
        return;
    }
    slash = strrchr(cart_path, '/');
    if (!slash) {
        snprintf(out, out_cap, ".");
        return;
    }
    n = (size_t)(slash - cart_path);
    if (n + 1 > out_cap) {
        n = out_cap - 1;
    }
    memcpy(out, cart_path, n);
    out[n] = '\0';
}

static void emu_sfx_x(void) {
    r01_bgm_host_sfx_play(R01_SFX_X);
}

static void emu_sfx_y(void) {
    r01_bgm_host_sfx_play(R01_SFX_Y);
}

static void emu_start_host_bgm(const char *cart_path) {
    char out_dir[512];
    char logic[576];
    char bin[576];
    int track = 0;
    int i;
    static const char *const logic_fallbacks[] = {
        "output/C/custom_logic.c",
        "../output/C/custom_logic.c",
        "../../output/C/custom_logic.c",
        NULL,
    };

    cart_output_dir(cart_path && cart_path[0] ? cart_path : R01E_DEFAULT_CART, out_dir, sizeof(out_dir));
    if (r01_custom_logic_path_for_output(out_dir, logic, sizeof(logic)) != 0) {
        snprintf(logic, sizeof(logic), "%s/C/custom_logic.c", out_dir);
    }

    if (!path_is_file(logic)) {
        for (i = 0; logic_fallbacks[i]; i++) {
            if (path_is_file(logic_fallbacks[i])) {
                snprintf(logic, sizeof(logic), "%s", logic_fallbacks[i]);
                break;
            }
        }
    }

    if (r01_custom_logic_scan_bgm_play(logic, &track) != 0) {
        return;
    }
    if (r01_bgm_track_bin_path(out_dir, track, bin, sizeof(bin)) != 0) {
        bin[0] = '\0';
    }
    if (!path_is_file(bin)) {
        /* Fall back to known relative output trees (cwd may not be repo root). */
        static const char *const root_fallbacks[] = {"output", "../output", "../../output", NULL};
        for (i = 0; root_fallbacks[i]; i++) {
            char try_bin[576];
            if (r01_bgm_track_bin_path(root_fallbacks[i], track, try_bin, sizeof(try_bin)) == 0 &&
                path_is_file(try_bin)) {
                snprintf(bin, sizeof(bin), "%s", try_bin);
                break;
            }
        }
    }
    if (r01_bgm_host_play(track, path_is_file(bin) ? bin : NULL) != 0) {
        if (r01_bgm_host_play(track, NULL) != 0) {
            fprintf(stderr, "retr01_emu: BGM host start failed (%s)\n", SDL_GetError());
        }
    }
}
/* Debug pane: VRAM atlas + world map + active BG/SPR palette rows + CPU budget. */
#define DBG_GAP 8
#define DBG_MAP_CELL 10
#define DBG_MAP_MAX_CELLS 16
#define DBG_MAP_W (DBG_MAP_CELL * DBG_MAP_MAX_CELLS)
#define DBG_MAP_H (DBG_MAP_CELL * DBG_MAP_MAX_CELLS)
#define DBG_PAL_SWATCH 8
#define DBG_PAL_GAP 2
#define DBG_PAL_GROUP_GAP 4
#define DBG_PAL_LABEL_W 28
#define DBG_PAL_H (DBG_PAL_SWATCH * 2 + DBG_PAL_GAP + 10)
#define DBG_CHART_BARS 20
#define DBG_CHART_HZ 2
#define DBG_CHART_H 72
#define DBG_CHART_PAD 6
#define DBG_CHART_LABEL_H 12
#define DBG_ATLAS_W R01E_VRAM_ATLAS_W
#define DBG_ATLAS_H R01E_VRAM_ATLAS_H
#define DBG_MASK_W R01E_SCREEN_PX_W
#define DBG_MASK_H R01E_SCREEN_PX_H
#define DBG_TOP_ROW_H DBG_ATLAS_H
#define DBG_WIN_W (DBG_ATLAS_W + DBG_GAP + DBG_ATLAS_W + DBG_GAP + DBG_MAP_W)
#define DBG_ROW2_Y (DBG_TOP_ROW_H + DBG_GAP)
#define DBG_WIN_H (DBG_ROW2_Y + DBG_MASK_H + DBG_GAP + DBG_PAL_H + DBG_GAP + DBG_CHART_H + DBG_CHART_LABEL_H)

static void draw_world_map(SDL_Renderer *ren, R01eMachine *m, int ox, int oy) {
    R01eWorldView wv;
    const uint8_t *dir;
    uint8_t present[DBG_MAP_MAX_CELLS][DBG_MAP_MAX_CELLS];
    int si, c, r;
    int cur_c, cur_r;
    int min_c, min_r, max_c, max_r;
    int cols, rows;
    int map_ox, map_oy;

    memset(present, 0, sizeof(present));
    min_c = min_r = DBG_MAP_MAX_CELLS;
    max_c = max_r = -1;
    if (r01e_cart_world(&m->cart, (int)m->io.world, &wv) != 0) {
        return;
    }
    dir = r01e_cart_ptr(&m->cart, wv.base + wv.off_screen_dir, (size_t)wv.screen_count * 12u);
    if (dir) {
        for (si = 0; si < wv.screen_count; si++) {
            const uint8_t *e = dir + (size_t)si * 12u;
            int col = R01E_CELL_COL(e[0]);
            int row = R01E_CELL_ROW(e[0]);
            if (col >= 0 && col < DBG_MAP_MAX_CELLS && row >= 0 && row < DBG_MAP_MAX_CELLS) {
                present[row][col] = 1;
                if (col < min_c) {
                    min_c = col;
                }
                if (row < min_r) {
                    min_r = row;
                }
                if (col > max_c) {
                    max_c = col;
                }
                if (row > max_r) {
                    max_r = row;
                }
            }
        }
    }
    if (max_c < min_c || max_r < min_r) {
        return;
    }
    cols = max_c - min_c + 1;
    rows = max_r - min_r + 1;

    if (m->play.enabled) {
        cur_c = (m->play.player_x + R01E_PLAY_PLAYER_W / 2) / R01E_SCREEN_PX_W;
        cur_r = (m->play.player_y + R01E_PLAY_PLAYER_H / 2) / R01E_SCREEN_PX_H;
    } else {
        cur_c = m->video.cam_origin_col;
        cur_r = m->video.cam_origin_row;
    }

    /* Center the used bounding box in the map pane. */
    map_ox = ox + (DBG_MAP_W - DBG_MAP_CELL * cols) / 2;
    map_oy = oy + (DBG_ATLAS_H - DBG_MAP_CELL * rows) / 2;

    for (r = min_r; r <= max_r; r++) {
        for (c = min_c; c <= max_c; c++) {
            SDL_Rect cell;
            cell.x = map_ox + (c - min_c) * DBG_MAP_CELL + 1;
            cell.y = map_oy + (r - min_r) * DBG_MAP_CELL + 1;
            cell.w = DBG_MAP_CELL - 2;
            cell.h = DBG_MAP_CELL - 2;
            if (c == cur_c && r == cur_r && present[r][c]) {
                SDL_SetRenderDrawColor(ren, 255, 200, 40, 255); /* current screen */
            } else if (present[r][c]) {
                SDL_SetRenderDrawColor(ren, 70, 110, 150, 255); /* present */
            } else {
                SDL_SetRenderDrawColor(ren, 28, 30, 36, 255); /* hole in bbox */
            }
            SDL_RenderFillRect(ren, &cell);
            SDL_SetRenderDrawColor(ren, 18, 20, 24, 255);
            SDL_RenderDrawRect(ren, &cell);
        }
    }
}

/* 5x7 uppercase glyphs (MSB = leftmost). */
static const uint8_t DBG_GLYPH_B[7] = {0x1E, 0x11, 0x11, 0x1E, 0x11, 0x11, 0x1E};
static const uint8_t DBG_GLYPH_G[7] = {0x0E, 0x11, 0x10, 0x17, 0x11, 0x11, 0x0E};
static const uint8_t DBG_GLYPH_S[7] = {0x0E, 0x11, 0x10, 0x0E, 0x01, 0x11, 0x0E};
static const uint8_t DBG_GLYPH_P[7] = {0x1E, 0x11, 0x11, 0x1E, 0x10, 0x10, 0x10};
static const uint8_t DBG_GLYPH_R[7] = {0x1E, 0x11, 0x11, 0x1E, 0x14, 0x12, 0x11};

static void dbg_blit_glyph(SDL_Renderer *ren, int x, int y, const uint8_t rows[7], Uint8 R, Uint8 G,
                           Uint8 B) {
    int row, col;
    SDL_SetRenderDrawColor(ren, R, G, B, 255);
    for (row = 0; row < 7; row++) {
        for (col = 0; col < 5; col++) {
            if (rows[row] & (1u << (4 - col))) {
                SDL_RenderDrawPoint(ren, x + col, y + row);
            }
        }
    }
}

static void draw_pal_strip(SDL_Renderer *ren, int x, int y, const uint8_t *row16) {
    int pal, c;
    int cx = x;
    SDL_Rect cell;

    for (pal = 0; pal < R01E_PALS_PER_ROW; pal++) {
        for (c = 0; c < R01E_PAL_COLORS; c++) {
            uint8_t cr, cg, cb;
            uint8_t master = row16 ? (row16[pal * R01E_PAL_COLORS + c] & 63u) : 0;
            r01e_video_kit_rgb(master, &cr, &cg, &cb);
            cell.x = cx;
            cell.y = y;
            cell.w = DBG_PAL_SWATCH;
            cell.h = DBG_PAL_SWATCH;
            SDL_SetRenderDrawColor(ren, cr, cg, cb, 255);
            SDL_RenderFillRect(ren, &cell);
            SDL_SetRenderDrawColor(ren, 50, 55, 60, 255);
            SDL_RenderDrawRect(ren, &cell);
            cx += DBG_PAL_SWATCH + 1;
        }
        cx += DBG_PAL_GROUP_GAP - 1;
    }
}

static void draw_active_palettes(SDL_Renderer *ren, R01eMachine *m, int ox, int oy) {
    int y2 = oy + DBG_PAL_SWATCH + DBG_PAL_GAP;

    dbg_blit_glyph(ren, ox, oy, DBG_GLYPH_B, 160, 180, 160);
    dbg_blit_glyph(ren, ox + 6, oy, DBG_GLYPH_G, 160, 180, 160);
    draw_pal_strip(ren, ox + DBG_PAL_LABEL_W, oy, m->io.pal);

    dbg_blit_glyph(ren, ox, y2, DBG_GLYPH_S, 180, 160, 160);
    dbg_blit_glyph(ren, ox + 6, y2, DBG_GLYPH_P, 180, 160, 160);
    dbg_blit_glyph(ren, ox + 12, y2, DBG_GLYPH_R, 180, 160, 160);
    draw_pal_strip(ren, ox + DBG_PAL_LABEL_W, y2, m->io.pal + R01E_PAL_ROW_BYTES);
}

typedef struct DbgCpuChart {
    uint64_t active[DBG_CHART_BARS];
    uint64_t vblank[DBG_CHART_BARS];
    int count;
    int head; /* next write index */
    uint64_t peak_active;
    uint64_t peak_vblank;
    Uint32 last_sample_ms;
} DbgCpuChart;

static void dbg_chart_note_frame(DbgCpuChart *ch, const R01eMachine *m) {
    if (!ch || !m) {
        return;
    }
    if (m->prof_last_active > ch->peak_active) {
        ch->peak_active = m->prof_last_active;
    }
    if (m->prof_last_vblank > ch->peak_vblank) {
        ch->peak_vblank = m->prof_last_vblank;
    }
}

static void dbg_chart_maybe_sample(DbgCpuChart *ch, Uint32 now_ms) {
    int i;
    if (!ch) {
        return;
    }
    if (ch->last_sample_ms == 0) {
        ch->last_sample_ms = now_ms;
        return;
    }
    if ((int)(now_ms - ch->last_sample_ms) < (1000 / DBG_CHART_HZ)) {
        return;
    }
    i = ch->head;
    ch->active[i] = ch->peak_active;
    ch->vblank[i] = ch->peak_vblank;
    ch->head = (ch->head + 1) % DBG_CHART_BARS;
    if (ch->count < DBG_CHART_BARS) {
        ch->count++;
    }
    ch->peak_active = 0;
    ch->peak_vblank = 0;
    ch->last_sample_ms = now_ms;
}

static void draw_cpu_budget_chart(SDL_Renderer *ren, const DbgCpuChart *ch, int ox, int oy) {
    SDL_Rect frame;
    SDL_Rect bar;
    int plot_w = DBG_WIN_W - 2 * DBG_CHART_PAD;
    int plot_h = DBG_CHART_H - DBG_CHART_PAD;
    int slot_w;
    int budget_y;
    int n, slot;
    uint64_t budget = R01E_CPU_BUDGET_CYCLES;

    frame.x = ox;
    frame.y = oy;
    frame.w = DBG_WIN_W;
    frame.h = DBG_CHART_H + DBG_CHART_LABEL_H;
    SDL_SetRenderDrawColor(ren, 18, 20, 26, 255);
    SDL_RenderFillRect(ren, &frame);
    SDL_SetRenderDrawColor(ren, 40, 44, 52, 255);
    SDL_RenderDrawRect(ren, &frame);

    /* Legend swatches */
    bar.x = ox + DBG_CHART_PAD;
    bar.y = oy + 2;
    bar.w = 8;
    bar.h = 6;
    SDL_SetRenderDrawColor(ren, 70, 190, 200, 255);
    SDL_RenderFillRect(ren, &bar);
    bar.x += 12;
    SDL_SetRenderDrawColor(ren, 220, 140, 50, 255);
    SDL_RenderFillRect(ren, &bar);

    slot_w = plot_w / DBG_CHART_BARS;
    if (slot_w < 2) {
        slot_w = 2;
    }
    /* 100% budget line at top of plot (full frame CPU allotment). */
    budget_y = oy + DBG_CHART_LABEL_H;
    SDL_SetRenderDrawColor(ren, 120, 55, 55, 255);
    SDL_RenderDrawLine(ren, ox + DBG_CHART_PAD, budget_y, ox + DBG_CHART_PAD + plot_w - 1, budget_y);

    n = ch ? ch->count : 0;
    for (slot = 0; slot < n; slot++) {
        /* Oldest on the left */
        int idx = (ch->head - n + slot + DBG_CHART_BARS * 2) % DBG_CHART_BARS;
        uint64_t act = ch->active[idx];
        uint64_t vbl = ch->vblank[idx];
        uint64_t total = act + vbl;
        int h_tot, h_act, h_vbl;
        int bx = ox + DBG_CHART_PAD + slot * slot_w + 1;
        int bw = slot_w - 2;
        int base_y = oy + DBG_CHART_LABEL_H + plot_h;

        if (bw < 1) {
            bw = 1;
        }
        if (total > budget) {
            /* Scale so overflow still fits (clip at 150% visual). */
            uint64_t scale = (budget * 3u) / 2u;
            if (scale < total) {
                act = act * scale / total;
                vbl = vbl * scale / total;
                total = act + vbl;
            }
        }
        h_tot = (int)((total * (uint64_t)plot_h) / (budget ? budget : 1));
        h_act = (int)((act * (uint64_t)plot_h) / (budget ? budget : 1));
        h_vbl = (int)((vbl * (uint64_t)plot_h) / (budget ? budget : 1));
        if (h_tot > plot_h) {
            /* Preserve active:vblank ratio when clipping to plot. */
            if (total > 0) {
                h_act = (int)((act * (uint64_t)plot_h) / total);
                h_vbl = plot_h - h_act;
            } else {
                h_act = 0;
                h_vbl = 0;
            }
            h_tot = plot_h;
        } else {
            h_vbl = h_tot - h_act;
        }
        if (total > 0 && h_tot < 1) {
            h_tot = 1;
            h_act = (act >= vbl) ? 1 : 0;
            h_vbl = h_tot - h_act;
        }

        /* Stacked: active (bottom / cyan), vblank (top / orange) */
        if (h_act > 0) {
            bar.x = bx;
            bar.y = base_y - h_act;
            bar.w = bw;
            bar.h = h_act;
            SDL_SetRenderDrawColor(ren, 70, 190, 200, 255);
            SDL_RenderFillRect(ren, &bar);
        }
        if (h_vbl > 0) {
            bar.x = bx;
            bar.y = base_y - h_act - h_vbl;
            bar.w = bw;
            bar.h = h_vbl;
            SDL_SetRenderDrawColor(ren, 220, 140, 50, 255);
            SDL_RenderFillRect(ren, &bar);
        }
    }
}

static void present_debug_pane(SDL_Renderer *dbg_ren, SDL_Texture *vram_tex, SDL_Texture *bg0_tex,
                              SDL_Texture *mask_tex, R01eMachine *m, const DbgCpuChart *chart) {
    SDL_Rect dst;
    SDL_Rect vp;
    int chart_y;
    int bg0_x = DBG_ATLAS_W + DBG_GAP;
    int map_x = DBG_ATLAS_W + DBG_GAP + DBG_ATLAS_W + DBG_GAP;
    int l0_sx;
    int l0_sy;

    r01e_video_render_vram_atlas(m);
    r01e_video_render_bg0_atlas(m);
    r01e_video_render_l1_mask(m);
    SDL_UpdateTexture(vram_tex, NULL, m->video.vram_atlas, DBG_ATLAS_W * 3);
    SDL_UpdateTexture(bg0_tex, NULL, m->video.bg0_atlas, DBG_ATLAS_W * 3);
    SDL_UpdateTexture(mask_tex, NULL, m->video.l1_mask, DBG_MASK_W * 3);

    SDL_SetRenderDrawColor(dbg_ren, 12, 14, 18, 255);
    SDL_RenderClear(dbg_ren);

    dst.x = 0;
    dst.y = 0;
    dst.w = DBG_ATLAS_W;
    dst.h = DBG_ATLAS_H;
    SDL_RenderCopy(dbg_ren, vram_tex, NULL, &dst);

    dst.x = bg0_x;
    dst.y = 0;
    dst.w = DBG_ATLAS_W;
    dst.h = DBG_ATLAS_H;
    SDL_RenderCopy(dbg_ren, bg0_tex, NULL, &dst);

    vp.x = (int)m->io.scroll_x;
    vp.y = (int)m->io.scroll_y;
    vp.w = R01E_SCREEN_PX_W;
    vp.h = R01E_SCREEN_PX_H;
    SDL_SetRenderDrawColor(dbg_ren, 255, 40, 40, 255);
    SDL_RenderDrawRect(dbg_ren, &vp);
    vp.x += 1;
    vp.y += 1;
    vp.w -= 2;
    vp.h -= 2;
    if (vp.w > 0 && vp.h > 0) {
        SDL_RenderDrawRect(dbg_ren, &vp);
    }

    l0_sx = m->video.l0_cam_x % R01E_SCREEN_PX_W;
    l0_sy = m->video.l0_cam_y % R01E_SCREEN_PX_H;
    vp.x = bg0_x + l0_sx;
    vp.y = l0_sy;
    vp.w = R01E_SCREEN_PX_W;
    vp.h = R01E_SCREEN_PX_H;
    SDL_SetRenderDrawColor(dbg_ren, 80, 220, 120, 255);
    SDL_RenderDrawRect(dbg_ren, &vp);
    vp.x += 1;
    vp.y += 1;
    vp.w -= 2;
    vp.h -= 2;
    if (vp.w > 0 && vp.h > 0) {
        SDL_RenderDrawRect(dbg_ren, &vp);
    }

    draw_world_map(dbg_ren, m, map_x, 0);

    dst.x = 0;
    dst.y = DBG_ROW2_Y;
    dst.w = DBG_MASK_W;
    dst.h = DBG_MASK_H;
    SDL_RenderCopy(dbg_ren, mask_tex, NULL, &dst);

    draw_active_palettes(dbg_ren, m, 4, DBG_ROW2_Y + DBG_MASK_H + DBG_GAP);
    chart_y = DBG_ROW2_Y + DBG_MASK_H + DBG_GAP + DBG_PAL_H + DBG_GAP;
    draw_cpu_budget_chart(dbg_ren, chart, 0, chart_y);
    SDL_RenderPresent(dbg_ren);
}
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

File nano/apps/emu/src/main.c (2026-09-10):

#include "retr01_nano_emu/machine.h"

#include <SDL.h>

#include <stdio.h>
#include <stdlib.h>
#include <string.h>

#ifdef R01NE_DEFAULT_CART
#define DEFAULT_CART R01NE_DEFAULT_CART
#else
#define DEFAULT_CART "../../output/nano/test.r01nano"
#endif

int main(int argc, char **argv) {
    const char *path = argc > 1 ? argv[1] : DEFAULT_CART;
    R01neMachine machine;
    char err[256];
    SDL_Window *win = NULL;
    SDL_Renderer *ren = NULL;
    SDL_Texture *tex = NULL;
    int scale = 2;
    int running = 1;
    Uint32 last_ticks;

    memset(&machine, 0, sizeof(machine));
    if (r01ne_machine_boot(&machine, path, err, sizeof(err)) != 0) {
        fprintf(stderr, "nano_emu: boot failed: %s\n", err);
        return 1;
    }

    if (SDL_Init(SDL_INIT_VIDEO) != 0) {
        fprintf(stderr, "SDL_Init: %s\n", SDL_GetError());
        r01ne_machine_shutdown(&machine);
        return 1;
    }

    SDL_SetHint(SDL_HINT_RENDER_SCALE_QUALITY, "nearest");

    /* Hidden until the first composed frame is presented (avoids open flicker). */
    win = SDL_CreateWindow("Retr01 Nano Emu", SDL_WINDOWPOS_CENTERED, SDL_WINDOWPOS_CENTERED,
                           R01NE_VISIBLE_W * scale, R01NE_VISIBLE_H * scale, SDL_WINDOW_HIDDEN);
    if (!win) {
        fprintf(stderr, "SDL_CreateWindow: %s\n", SDL_GetError());
        r01ne_machine_shutdown(&machine);
        SDL_Quit();
        return 1;
    }
    ren = SDL_CreateRenderer(win, -1, SDL_RENDERER_ACCELERATED | SDL_RENDERER_PRESENTVSYNC);
    if (!ren) {
        ren = SDL_CreateRenderer(win, -1, 0);
    }
    if (!ren) {
        fprintf(stderr, "SDL_CreateRenderer: %s\n", SDL_GetError());
        SDL_DestroyWindow(win);
        r01ne_machine_shutdown(&machine);
        SDL_Quit();
        return 1;
    }
    SDL_RenderSetLogicalSize(ren, R01NE_VISIBLE_W, R01NE_VISIBLE_H);
    tex = SDL_CreateTexture(ren, SDL_PIXELFORMAT_RGB24, SDL_TEXTUREACCESS_STREAMING, R01NE_VISIBLE_W,
                            R01NE_VISIBLE_H);
    if (!tex) {
        fprintf(stderr, "SDL_CreateTexture: %s\n", SDL_GetError());
        SDL_DestroyRenderer(ren);
        SDL_DestroyWindow(win);
        r01ne_machine_shutdown(&machine);
        SDL_Quit();
        return 1;
    }

    printf("nano_emu: %s (%zu bytes)\n", path, machine.cart.len);
    printf("  world 0: %u screens, spawn (%u,%u) — MAP preview only (no sprites/input)\n",
           (unsigned)machine.world.screen_count, (unsigned)machine.world.spawn_col,
           (unsigned)machine.world.spawn_row);
    printf("Esc quit. R reset. Ctrl+1/2/3 scale.\n");

    SDL_UpdateTexture(tex, NULL, machine.video.fb, R01NE_VISIBLE_W * 3);
    SDL_SetRenderDrawColor(ren, 0, 0, 0, 255);
    SDL_RenderClear(ren);
    SDL_RenderCopy(ren, tex, NULL, NULL);
    SDL_RenderPresent(ren);
    SDL_ShowWindow(win);

    last_ticks = SDL_GetTicks();
    while (running) {
        SDL_Event ev;
        int framed = 0;
        while (SDL_PollEvent(&ev)) {
            if (ev.type == SDL_QUIT) {
                running = 0;
            } else if (ev.type == SDL_KEYDOWN) {
                if (ev.key.keysym.sym == SDLK_ESCAPE) {
                    running = 0;
                } else if ((ev.key.keysym.mod & KMOD_CTRL) && ev.key.keysym.sym == SDLK_1) {
                    scale = 1;
                    SDL_SetWindowSize(win, R01NE_VISIBLE_W * scale, R01NE_VISIBLE_H * scale);
                } else if ((ev.key.keysym.mod & KMOD_CTRL) && ev.key.keysym.sym == SDLK_2) {
                    scale = 2;
                    SDL_SetWindowSize(win, R01NE_VISIBLE_W * scale, R01NE_VISIBLE_H * scale);
                } else if ((ev.key.keysym.mod & KMOD_CTRL) && ev.key.keysym.sym == SDLK_3) {
                    scale = 3;
                    SDL_SetWindowSize(win, R01NE_VISIBLE_W * scale, R01NE_VISIBLE_H * scale);
                } else if (ev.key.keysym.sym == SDLK_r) {
                    (void)r01ne_machine_reset(&machine);
                    framed = 1;
                }
            }
        }

        {
            Uint32 now = SDL_GetTicks();
            if ((int)(now - last_ticks) >= 16) {
                r01ne_machine_frame(&machine);
                last_ticks = now;
                framed = 1;
            }
        }

        if (framed) {
            SDL_UpdateTexture(tex, NULL, machine.video.fb, R01NE_VISIBLE_W * 3);
            SDL_SetRenderDrawColor(ren, 0, 0, 0, 255);
            SDL_RenderClear(ren);
            SDL_RenderCopy(ren, tex, NULL, NULL);
            SDL_RenderPresent(ren);
        } else {
            SDL_Delay(1);
        }
    }

    SDL_DestroyTexture(tex);
    SDL_DestroyRenderer(ren);
    SDL_DestroyWindow(win);
    r01ne_machine_shutdown(&machine);
    SDL_Quit();
    return 0;
}

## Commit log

2026-09-07 Working on new PCB iterations
    [Retr01_Cartridge.kicad_pcb, Retr01_Motherboard_v_09.kicad_pcb]
2026-09-07 Increased to 128 OAM (from 64)
    [Retr01_Cartridge.kicad_pcb, Retr01_Motherboard.kicad_pcb, Retr01_Motherboard.kicad_sch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]
2026-09-07 Working on wave audio visualizer in Sim
    [Retr01_Cartridge.kicad_pcb, Retr01_Motherboard.kicad_pcb]
2026-09-07 New cart PCB design
    [Retr01_Cartridge.kicad_pcb]
2026-09-07 Working on more PCBs
    [Retr01_Cartridge.kicad_pcb, Retr01_Motherboard.kicad_pcb]
2026-09-07 Removed .history kicad files
2026-09-07 Working on PCBs
    [Retr01_Cartridge.kicad_pcb, Retr01_Motherboard.kicad_pcb]
2026-09-07 Fixed issue with BG0 rendering
    [Retr01_Cartridge.kicad_pcb]
2026-09-08 Fixing issues with wave monitor
    [main.c]
2026-09-08 Fixing UI for Nano Studio
    [play_collision.cfg]
2026-09-08 Added main pitch line
2026-09-08 Working on Nano emulator + Nano Studio
    [game.cfg]
2026-09-08 Fixed Nano Emu flicker + expanding Nano test world
    [main.c]
2026-09-08 Added laser shooting to Nano demo
2026-09-08 Fixed pads issue in Nano Sim
    [atmega1284p_nano.c]
2026-09-08 Preparing more pre-netlist Nano docs
    [Retr01_Motherboard.kicad_pcb]
2026-09-08 Working on clearance trick (non-Nano work)
    [Retr01_Motherboard.kicad_pcb]
2026-09-08 Added THT ATmega footprint (Nano)
    [nano_main_pcb_v_01.kicad_pcb, nano_main_pcb_v_01.kicad_sch]
2026-09-08 Initial PCBs for main and cart (Nano)
    [Nano_Cart_PCB_v_01.kicad_pcb, Nano_Cart_PCB_v_01.kicad_sch, nano_main_pcb_v_01.kicad_pcb]
2026-09-08 Fully THT cart footprint (Nano)
    [Nano_Cart_PCB_v_01.kicad_pcb]
2026-09-08 Gitignore changes
    [Nano_Cart_PCB_v_01.kicad_pcb]
2026-09-08 KiCad 2-layer tutorial
    [Nano_Cart_PCB_v_01.kicad_pcb]
2026-09-08 Updated Nano cart PCB
    [Nano_Cart_PCB_v_01.kicad_pcb]
2026-09-09 Small UI fixes on Nano Sim
    [nano_main_pcb_v_01.kicad_pcb]
2026-09-09 Expanding Nano PCB capabilities
    [nano_main_pcb_v_01.kicad_pcb]
2026-09-09 Manual design on main Nano PCB
    [nano_main_pcb_v_01.kicad_pcb]
2026-09-09 Fixed ASCII drawing + updated PCB files
    [nano_main_pcb_v_01.kicad_pcb]
2026-09-09 Workin on main Nano PCB design
    [nano_main_pcb_v_01.kicad_pcb]
2026-09-10 Updated main Nano README
    [nano_main_pcb_v_01.kicad_pcb]
2026-09-10 Zero concept of sprite/tile-entities in Nano
    [game.cfg]
2026-09-10 Manually routed Nano main PCB
    [main_pcb_phase_1.kicad_pcb, main_pcb_phase_1.kicad_sch]
